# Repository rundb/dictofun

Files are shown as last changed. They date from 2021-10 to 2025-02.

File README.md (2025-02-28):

# DictoFun



Small wearable NRF52832-based-based voice recorder.

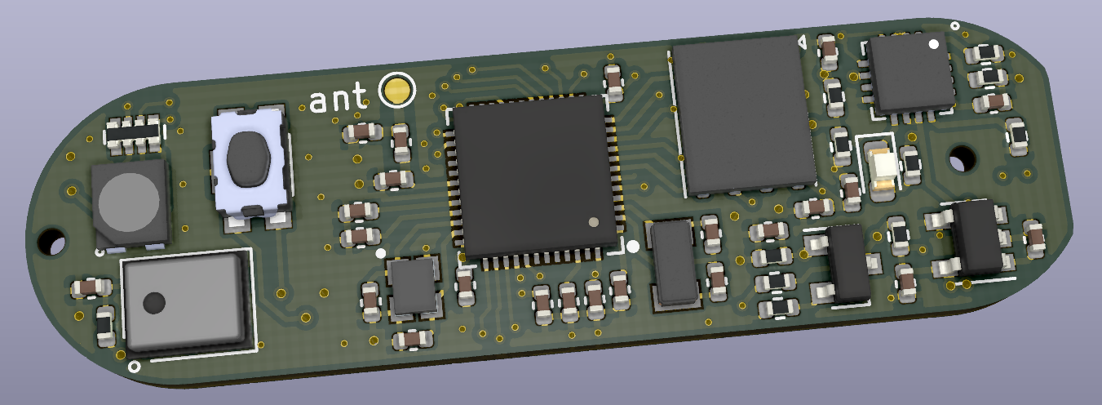
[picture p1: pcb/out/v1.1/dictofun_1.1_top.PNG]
DictoFun


## Concept

Device was initiated after my frustration while using voice recorder for storing ideas. It was taking up to 7 seconds from taking the voice recorder of the pocket to start recording the data. 

Idea behind the device: press and hold the big button on the device and start speaking. The device should start recording _immediately_ (== under human reaction time, <=0.4 sec), without the need for any other presses or for looking at the screen. When you're done - release the button. This should end the record. 

After finishing the record device should transfer the record to the phone. The record is then transferred to the voice recognition service. The recognized text should then be sent to the note keeper of your choice.

## Project structure

Project consists of 3 parts: 
* `pcb` - everything related to the schematics/PCB/boards' production. Currently v1.0, 1.1 and 1.2 exist, only v1.2 is supported in the software.
* `firmware` - software components for NRF52 chip. 
* `case` - STL files for 3D-printing the case for the Dictofun device.
* `doc` - folder with documentation used in the process of the development (datasheets, and potentially later schematic files).

`iOS` and `Android` counterparts are placed in a separate repository.

## Schematics

Relevant schematics for device is located here: `out/v1.2/schematic/nRF52832_qfaa.pdf`

## Build firmware

TBD.

Before building the firmware, SDK should be downloaded. To do that, go to `firmware/sdk` folder and execute script
`download_nordic_sdk.sh`. This command downloads and extracts the SDK files into the folder locally.

After the download one can open a corresponding Segger SES Project with SES. Later it should be possible to build with CMake. 

## Prerequisites

* install `gcc-arm-none-eabi-10.3-2021.10` to `/usr/share/gcc-arm-none-eabi-10.3-2021.10`.
* install `cmake` 3.22 or newer
* install `make`
* run script `firmware/sdk/download_nordic_sdk.sh`

## Flashing

`nrfjprog` is required to flash firmware into the device. Following command performs flashing (without changing the SoftDevice)

```
nrfjprog --reset --program ./build/src/targets/dictofun/Dictofun.hex --sectorerase --family NRF52 --verify
```

If SoftDevice is not flashed, it should be flashed using the following command:

```
nrfjprog --reset --program ./sdk/nRF5_SDK_17.1.0_ddde560/components/softdevice/s140/hex/s140_nrf52_7.2.0_softdevice.hex  --family NRF52 --sectorerase --verify
```

Both commands should be executed from folder `firmware` in the project structure.

## Clang-format

This command is used to format code recursively. 

```
find ./ -iname "*h" -o -iname "*.cpp" | xargs clang-format -i
```

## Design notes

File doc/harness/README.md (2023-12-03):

# Dictofun flashing harness

Special harness PCB has been developed to ease development of Dictofun. It is basically a bed of nails, where nails are connected
to pins of `Raspberry Pi Pico` evaluation board. It allows to combine flashing device, USB-UART bridge and button control into one 
single device and thus use only one USB connection to do all functions needed during the development.

In order to use this harness, following steps should be performed:
- flash Picoprobe firmware into Raspberry Pi Pico
- build OpenOCD with support of Picoprobe
- set up Picoprobe OpenOCD rules

After that flashing becomes possible.

## Picoprobe firmware

Picoprobe firmware implements a composite USB device with 2 devices: one used by OpenOCD for flashing and one - USB-UART bridge.

Here is the list of steps to perform (particular revision of repo is used in order to guarantee reproducibility):

```
# Assumption: we are in our working folder
# export DICTOFUN_PATH=/home/user/dictofun
git clone https://github.com/raspberrypi/pico-sdk.git
cd pico-sdk
git checkout 6a7db34ff63345a7badec79ebea3aaef1712f374
git submodule update --init --recursive
cd ..
git clone https://github.com/raspberrypi/picoprobe.git
cd picoprobe
git checkout 7de418cce3dae75ad854029b14e8869955f0afaa
git submodule update --init --recursive
git apply $DICTOFUN_PATH/doc/harness/dictofun_harness_config.patch
mkdir build && cd build
export PICO_SDK_PATH=../../pico-sdk
cmake ..
make -j
```

This chain of commands results in file `picoprobe.uf2` residing in the `build` folder. This file should be used to flash Raspberry Pi Pico on 
the harness. After flashing this file (instructions for that can be found in Chapter 3.2.4 of [Getting started with Raspberry Pi Pico](https://datasheets.raspberrypi.com/pico/getting-started-with-pico.pdf)) Raspberry Pico becomes a flashing device as well as a USB-UART bridge.

## OpenOCD

OpenOCD has to be built according to `Appendix A` in [Getting started with Raspberry Pi Pico](https://datasheets.raspberrypi.com/pico/getting-started-with-pico.pdf) document (here - Linux only)

```
cd <DEVELOPMENT/FOLDER>
sudo apt install automake autoconf build-essential texinfo libtool libftdi-dev libusb-1.0-0-dev
git clone https://github.com/raspberrypi/openocd.git --branch rp2040 --depth=1
cd openocd
./bootstrap
./configure
make -j
sudo make install
```

## udev rules

I had to install `udev` rules as well. It might eventually work without it, as I haven't checked this scenario, but I don't think it's a bad idea to install them:

```
# /etc/udev/rules.d/99-pico.rules

# Make an RP2040 in BOOTSEL mode writable by all users, so you can `picotool`
# without `sudo`. 
SUBSYSTEM=="usb", ATTRS{idVendor}=="2e8a", ATTRS{idProduct}=="0003", MODE="0666"

# Symlink an RP2040 running MicroPython from /dev/pico.
#
# Then you can `mpr connect $(realpath /dev/pico)`.
SUBSYSTEM=="tty", ATTRS{idVendor}=="2e8a", ATTRS{idProduct}=="0005", SYMLINK+="pico"

#picoprobe
SUBSYSTEM=="usb", ATTRS{idVendor}=="2e8a", MODE="0666"

#after adding this execute
# sudo udevadm control --reload-rules &&  sudo udevadm trigger 
# connect and disconnetc the USB device
#
```
I have connected and disconnected the device after that and also rebooted the computer. After that I was able to launch flashing scripts.

## Usage

Following script performs flashing of an appropriate HEX file (assuming that build has been done):

```
cd <PATH/TO/DICTOFUN/firmware/build>
openocd -f interface/cmsis-dap.cfg -f target/nrf52.cfg -c "program ./src/targets/dictofun/Dictofun.hex verify reset exit"
```

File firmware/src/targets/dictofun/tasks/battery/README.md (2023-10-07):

# Battery measurement

Battery measurement is taken to a separate task due to the importance of this function.

Basically this task performs 3 functions:
- perform measurements of battery voltage level (so it configures ADC and performs filtering)
- perform a conversion of the collected samples into an estimation of voltage level
- provide the battery level estimation to the consumers.

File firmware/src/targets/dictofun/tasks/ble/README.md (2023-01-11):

# BLE subsystem

This module aggregates all BLE configurations and functions. 

Dictofun should utilize following services:

- Led and Button service - a basic service used to bring up basic software and hardware components.
- Object Transfer service - main service that should be used 
- Distant Firmware Update service - service used for firmware upgrades

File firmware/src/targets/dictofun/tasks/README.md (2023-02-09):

# Tasks architecture

This module implements following system architecture:

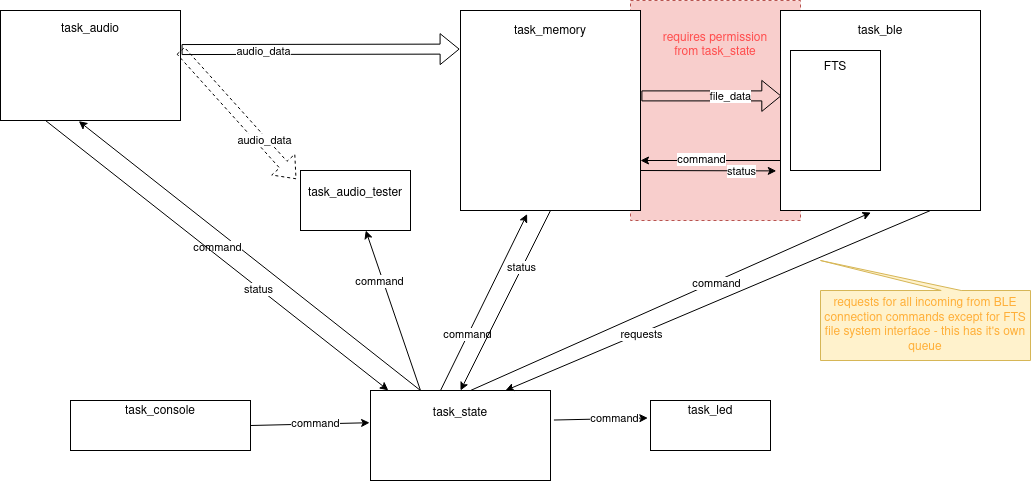
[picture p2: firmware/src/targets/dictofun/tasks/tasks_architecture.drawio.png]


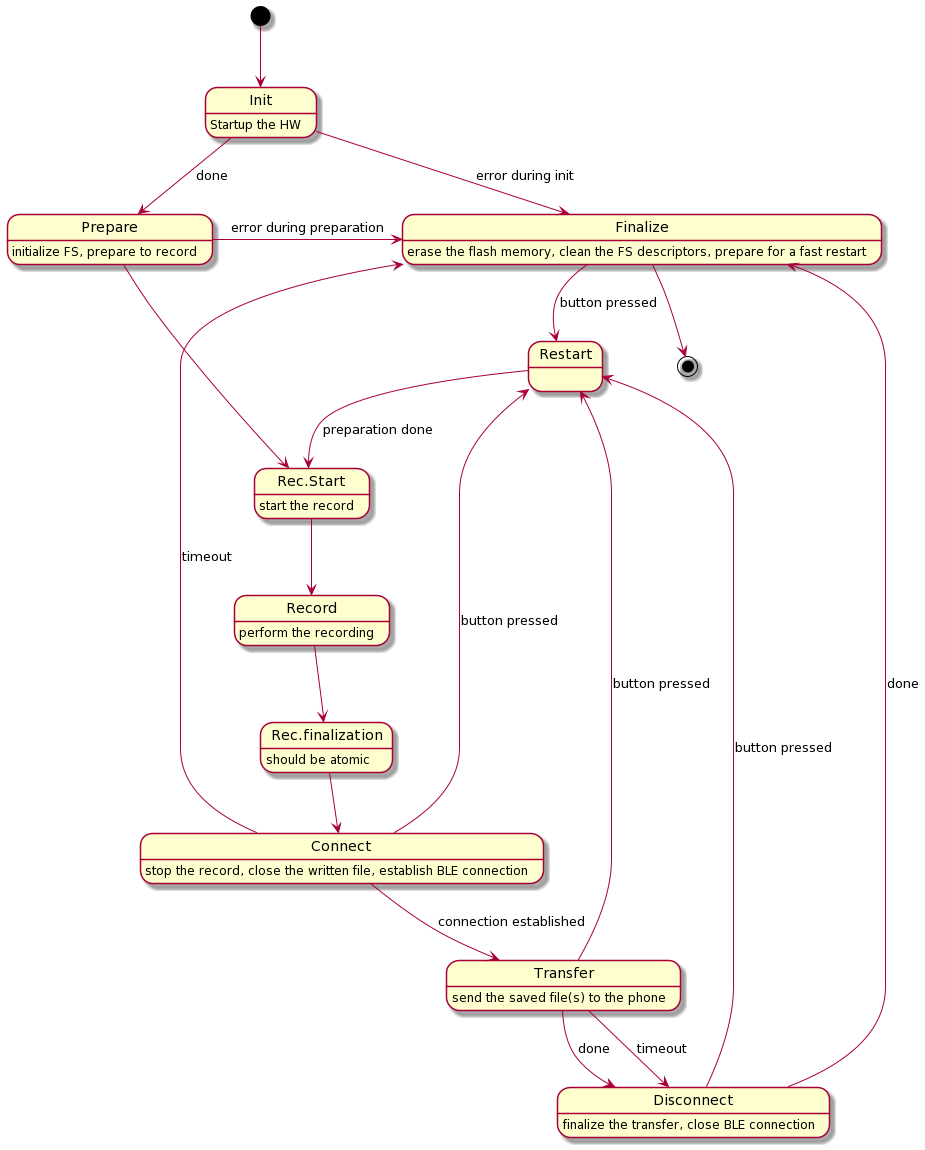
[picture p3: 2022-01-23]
firmware/src/targets/dictofun/tasks/dictofun_fsm.png

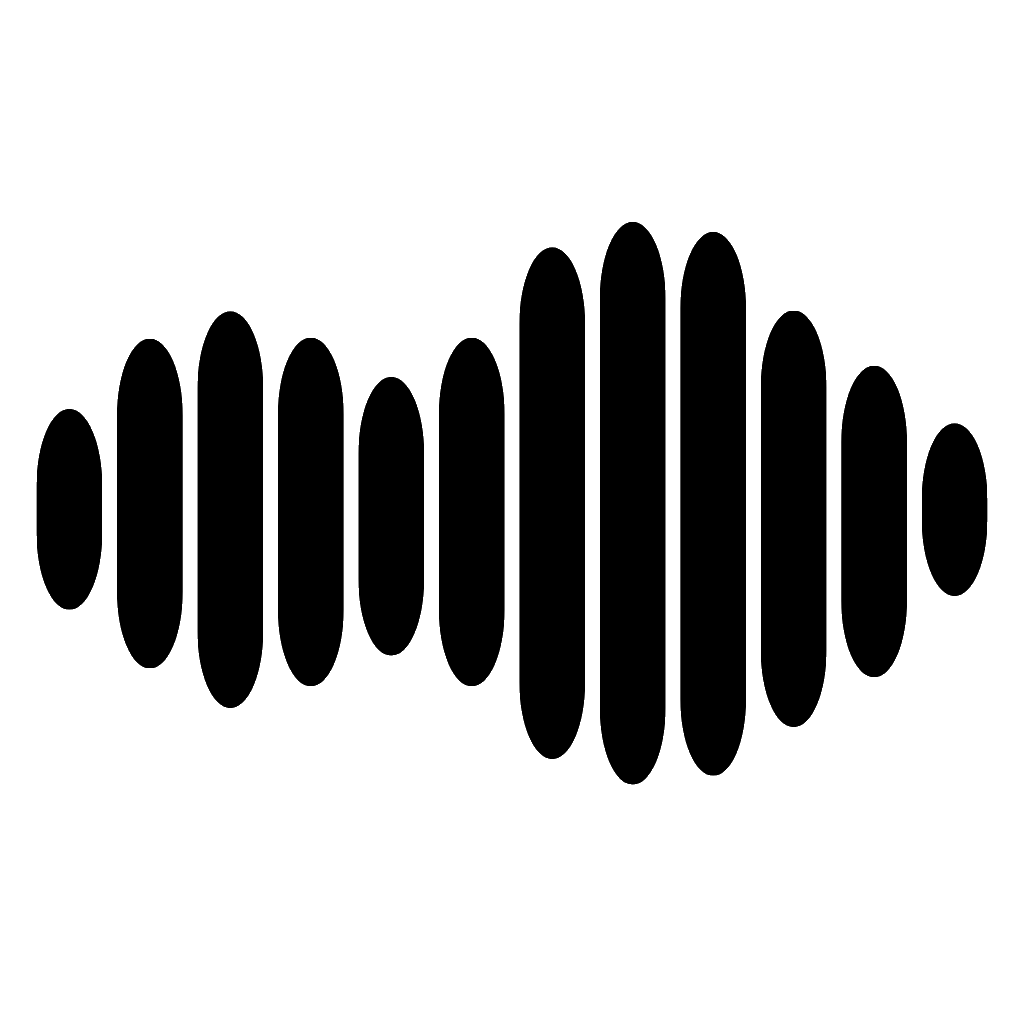
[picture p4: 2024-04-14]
pcb/Dictofun.png

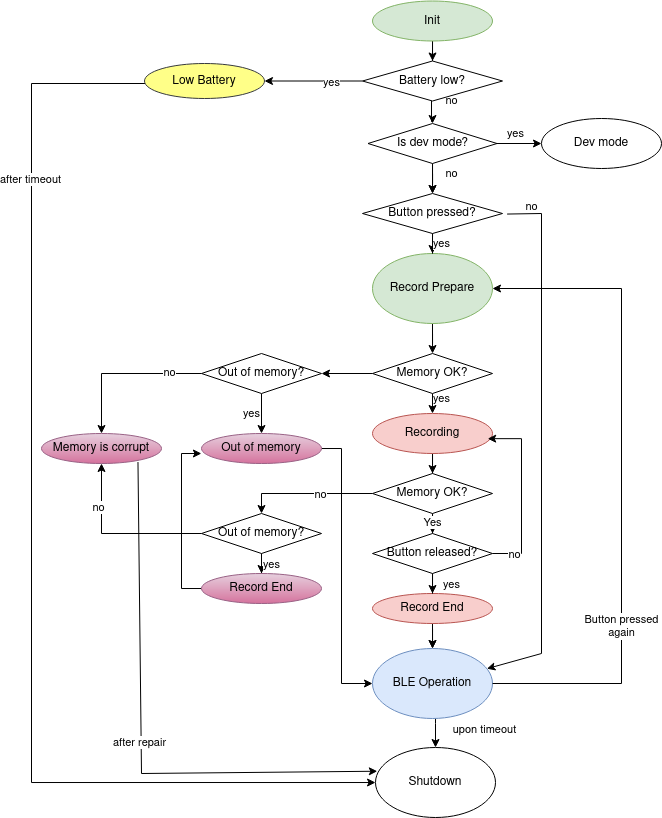
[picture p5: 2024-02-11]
firmware/src/targets/dictofun/tasks/systemstate/df-states.drawio.png

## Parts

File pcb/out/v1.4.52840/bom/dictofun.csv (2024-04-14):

Designator | Value | Footprint | LCSC | Qty
C1, C2 | 22uF | Capacitor_SMD:C_0603_1608Metric | C84419 | 2
C3, C4, C5, C7, C8, C13, C15, C18, C22, C25, C27, C53, C54 | 100nF | Capacitor_SMD:C_0402_1005Metric | C1525 | 13
C6, C14, C17, C19, C24, C26, C55 | 1uF | Capacitor_SMD:C_0402_1005Metric | C77007 | 7
C9, C10, C11, C12 | 10pF | Capacitor_SMD:C_0402_1005Metric | C32949 | 4
C20, C21 | 4.7uF | Capacitor_SMD:C_0402_1005Metric | C23733 | 2
C23 | 10uF | Capacitor_SMD:C_0402_1005Metric | C15525 | 1
C28 | 100p | Capacitor_SMD:C_0402_1005Metric | C445763 | 1
C29 | 47nF | Capacitor_SMD:C_0402_1005Metric | C338148 | 1
C47 | 0.7pF | Capacitor_SMD:C_0402_1005Metric | C2194394 | 1
C49 | 820pF | Capacitor_SMD:C_0402_1005Metric | C161159 | 1
C50, C51, C52 | 4.7uF | Capacitor_SMD:C_0603_1608Metric | C108342 | 3
D1 | PRTR5V0U2X | Package_TO_SOT_SMD:SOT-143 | C2827688 | 1
D3 | LED | LED_SMD:LED_0603_1608Metric | C2981448 | 1
D5 | D_Schottky | Diode_SMD:D_SOD-123F | C223608 | 1
FB1, FB2, FB3 | FerriteBead | Inductor_SMD:L_0402_1005Metric | C19136 | 3
L1 | 0.47uH | Inductor_SMD:L_1008_2520Metric | C1333867 | 1
L2 | 10uH | Inductor_SMD:L_0402_1005Metric | C910650 | 1
L3 | 15nH | Inductor_SMD:L_0402_1005Metric |  | 1
L7 | 2.2nH | Inductor_SMD:L_0402_1005Metric | C97985 | 1
Q1 | PMOS | Package_TO_SOT_SMD:SOT-23 | C332106 | 1
R1, R14, R18, R19, R24 | 100K | Resistor_SMD:R_0402_1005Metric | C25741 | 5
R2, R4, R22 | 4.7k | Resistor_SMD:R_0402_1005Metric | C25900 | 3
R3, R12, R25 | 330 | Resistor_SMD:R_0402_1005Metric | C25104 | 3
R5, R17, R21 | 1.6K | Resistor_SMD:R_0402_1005Metric | C25867 | 3
R6 | 1.13K | Resistor_SMD:R_0402_1005Metric | C67014 | 1
R7 | 10K | Resistor_SMD:R_0402_1005Metric | C25744 | 1
R8 | 1.18K | Resistor_SMD:R_0402_1005Metric | C270651 | 1
R9, R13 | 1K | Resistor_SMD:R_0402_1005Metric | C11702 | 2
R10, R11, R23 | 1M | Resistor_SMD:R_0402_1005Metric | C226699 | 3
R15 | 255k | Resistor_SMD:R_0603_1608Metric | C728604 | 1
R16 | 91k | Resistor_SMD:R_0603_1608Metric | C227535 | 1
RN3 | R_Pack04 | Resistor_SMD:R_Array_Convex_4x0402 | C25726 | 1
S1 | KMR221GLFS | df_components:SW_KMR221GLFS | C72443 | 1
U1 | nRF52840 | Package_DFN_QFN:Nordic_AQFN-73-1EP_7x7mm_P0.5mm | C190794 | 1
U2 | W25Q128JWPIQ | nRF52832_qfaa:WSON-8-1EP_6x5mm_P1.27mm_EP3.4x4.3mm | C2689660 | 1
U3 | TPS63802DLAR | df_components:VREG_TPS63802DLAR | C2845237 | 1
U4 | BQ24078RGTR | _other:VQFN-16-1EP_3x3mm_P0.5mm_EP1.45x1.45mm_ThermalVias | C15464 | 1
U6 | SN74LVC1G79DBVT | Package_TO_SOT_SMD:SOT-23-5 | C42878 | 1

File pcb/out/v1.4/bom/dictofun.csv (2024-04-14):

Designator | Footprint | LCSC
C1 | Capacitor_SMD:C_0603_1608Metric | C109447
C2 | Capacitor_SMD:C_0603_1608Metric | C109447
C3 | Capacitor_SMD:C_0402_1005Metric | C1525
C4 | Capacitor_SMD:C_0201_0603Metric | C5142565
C5 | Capacitor_SMD:C_0201_0603Metric | C5142565
C6 | Capacitor_SMD:C_0402_1005Metric | C77007
C7 | Capacitor_SMD:C_0201_0603Metric | C5142565
C8 | Capacitor_SMD:C_0201_0603Metric | C5142565
C10 | Capacitor_SMD:C_0402_1005Metric | C32949
C13 | Capacitor_SMD:C_0402_1005Metric | C32949
C15 | Capacitor_SMD:C_0402_1005Metric | C1525
C17 | Capacitor_SMD:C_0402_1005Metric | C52923
C18 | Capacitor_SMD:C_0402_1005Metric | C1525
C19 | Capacitor_SMD:C_0402_1005Metric | C52923
C20 | Capacitor_SMD:C_0402_1005Metric | C23733
C21 | Capacitor_SMD:C_0402_1005Metric | C23733
C23 | Capacitor_SMD:C_0402_1005Metric | C15525
C24 | Capacitor_SMD:C_0402_1005Metric | C52923
C25 | Capacitor_SMD:C_0402_1005Metric | C1525
C26 | Capacitor_SMD:C_0402_1005Metric | C52923
C27 | Capacitor_SMD:C_0402_1005Metric | C1525
C28 | Capacitor_SMD:C_0201_0603Metric | C5142565
C29 | Capacitor_SMD:C_0201_0603Metric | C5142565
C30 | Capacitor_SMD:C_0201_0603Metric | C5142565
C31 | Capacitor_SMD:C_0201_0603Metric | C5142565
C32 | Capacitor_SMD:C_0201_0603Metric | C5142565
C33 | Capacitor_SMD:C_0201_0603Metric | C5142565
C34 | Capacitor_SMD:C_0201_0603Metric | C5142565
C35 | Capacitor_SMD:C_0201_0603Metric | C5142565
C37 | Capacitor_SMD:C_0402_1005Metric | C77007
C38 | Capacitor_SMD:C_0402_1005Metric | C77007
C39 | Capacitor_SMD:C_0402_1005Metric | C77007
C40 | Capacitor_SMD:C_0402_1005Metric | C77007
C41 | Capacitor_SMD:C_0603_1608Metric | C77183
C42 | Capacitor_SMD:C_0603_1608Metric | C2961288
C43 | Capacitor_SMD:C_0603_1608Metric | C108342
C44 | Capacitor_SMD:C_0402_1005Metric | C77007
C45 | Capacitor_SMD:C_0201_0603Metric | C5142565
D1 | Package_TO_SOT_SMD:SOT-143 | C2827688
D3 | LED_SMD:LED_0603_1608Metric | C131282
D5 | Diode_SMD:D_SOD-123F | C223608
FB1 | Inductor_SMD:L_0402_1005Metric | C19136
FB2 | Inductor_SMD:L_0402_1005Metric | C19136
FB3 | Inductor_SMD:L_0402_1005Metric | C19136
L1 | Inductor_SMD:L_1008_2520Metric | C1333867
L3 | Inductor_SMD:L_0603_1608Metric | C5339208
L4 | Inductor_SMD:L_0603_1608Metric | C5339208
L5 | Inductor_SMD:L_0201_0603Metric | C1332892
L6 | Inductor_SMD:L_0201_0603Metric | C1332892
L7 | Inductor_SMD:L_0201_0603Metric | C1329438
Q1 | Package_TO_SOT_SMD:SOT-23 | C332106
R1 | Resistor_SMD:R_0402_1005Metric | C25741
R2 | Resistor_SMD:R_0402_1005Metric | C25900
R3 | Resistor_SMD:R_0402_1005Metric | C25104
R4 | Resistor_SMD:R_0402_1005Metric | C25900
R5 | Resistor_SMD:R_0402_1005Metric | C25867
R6 | Resistor_SMD:R_0402_1005Metric | C67014
R7 | Resistor_SMD:R_0402_1005Metric | C25744
R8 | Resistor_SMD:R_0402_1005Metric | C270651
R9 | Resistor_SMD:R_0402_1005Metric | C11702
R10 | Resistor_SMD:R_0402_1005Metric | C226699
R11 | Resistor_SMD:R_0402_1005Metric | C226699
R12 | Resistor_SMD:R_0402_1005Metric | C25104
R13 | Resistor_SMD:R_0402_1005Metric | C11702
R14 | Resistor_SMD:R_0402_1005Metric | C25741
R15 | Resistor_SMD:R_0603_1608Metric | C728604
R16 | Resistor_SMD:R_0603_1608Metric | C227535
R17 | Resistor_SMD:R_0402_1005Metric | C25867
R18 | Resistor_SMD:R_0402_1005Metric | C25741
R19 | Resistor_SMD:R_0402_1005Metric | C25741
R20 | Resistor_SMD:R_0201_0603Metric | C166070
R21 | Resistor_SMD:R_0402_1005Metric | C25867
R22 | Resistor_SMD:R_0402_1005Metric | C25900
R23 | Resistor_SMD:R_0402_1005Metric | C226699
R24 | Resistor_SMD:R_0402_1005Metric | C25741
R25 | Resistor_SMD:R_0402_1005Metric | C25104
RN3 | Resistor_SMD:R_Array_Convex_4x0402 | C25726
S1 | df_components:SW_KMR221GLFS | C72443
U2 | nRF52832_qfaa:WSON-8-1EP_6x5mm_P1.27mm_EP3.4x4.3mm | C2689660
U3 | df_components:VREG_TPS63802DLAR | C2845237
U4 | _other:VQFN-16-1EP_3x3mm_P0.5mm_EP1.45x1.45mm_ThermalVias | C15464
U6 | Package_TO_SOT_SMD:SOT-23-5 | C42878
U7 | _other:XCVR_NRF5340-QKAA-R7 | C3015611
C47 | Capacitor_SMD:C_0402_1005Metric | C384700
C11 | Capacitor_SMD:C_0402_1005Metric | C161369
C12 | Capacitor_SMD:C_0402_1005Metric | C161369

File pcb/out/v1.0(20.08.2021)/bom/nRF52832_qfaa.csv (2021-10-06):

Id | Designator | Package | Quantity | Designation | Supplier and ref
1 | R5 | R_0402_1005Metric | 1 | 1M
2 | R4,R3,R2,R6 | R_0402_1005Metric | 4 | 330
3 | C13,C20,C17,C16,C4,C5,C8 | RESC0402_N | 7 | 100nF
4 | J2 | PinHeader_2x05_P1.27mm_Vertical_SMD | 1 | Conn_02x05_Odd_Even
5 | C19,C18 | C_0603_1608Metric | 2 | 10uF
6 | C15 | RESC0402_N | 1 | 1uF
7 | C10 | RESC0402_N | 1 | 1µF
8 | U4 | SPU0410HR5H | 1 | SPU0410HR5H
9 | J1 | PinHeader_1x02_P2.54mm_Vertical | 1 | Battery
10 | RN1 | R_Array_Convex_4x0603 | 1 | R_Pack04
11 | D1 | LED_Cree-PLCC4_2x2mm_CW | 1 | ASMB-MTB0-0A3A2
12 | J3 | PinHeader_1x03_P2.54mm_Vertical | 1 | Conn_01x03_Male
13 | L2 | RESC0402_N | 1 | 2.7nH
14 | AE1 | ANT_2450AT18B100 | 1 | Antenna_Chip
15 | U5 | WSON-8-1EP_6x5mm_P1.27mm_EP3.4x4.3mm | 1 | W25Q32JVZP
16 | U3 | SOT-23-5 | 1 | TLV75533PDBVR
17 | U2 | LED_BUTTON | 1 | LED-Button
18 | U1 | QFN40P600X600X90-48_N | 1 | NRF52832
19 | X1 | BT-XTAL_2016_N | 1 | 32MHz
20 | L1 | RESC0402_N | 1 | 3.3nH
21 | C2,C1,C11,C12 | RESC0402_N | 4 | 12pF
22 | C3 | RESC0402_N | 1 | 1.2pF
23 | C6 | RESC0402_N | 1 | N.M.
24 | C7 | RESC0402_N | 1 | 100pF
25 | C9 | RESC0603_N | 1 | 4.7µF
26 | X2 | XTAL_3215_N | 1 | 32.768kHz

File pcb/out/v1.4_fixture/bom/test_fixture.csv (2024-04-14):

Designator | Comment | Footprint | LCSC
C2, C3, C6, C7, C11, C12, C13, C14 | 100n | Capacitor_SMD:C_0402_1005Metric | C1525
C9 | 10u | Resistor_SMD:R_1206_3216Metric | C165101
C10 | 22u | Capacitor_SMD:C_1206_3216Metric | C92818
Q1 | NMOS | Package_TO_SOT_SMD:SOT-23 | C916396
R1 | 415 | Resistor_SMD:R_0603_1608Metric | C114669
R2 | 187 | Resistor_SMD:R_0603_1608Metric | C22828
R4, R5, R6, R11 | 100K | Resistor_SMD:R_0603_1608Metric | C122538
R7 | 200K | Resistor_SMD:R_0603_1608Metric | C118142
R8 | 300K | Resistor_SMD:R_0603_1608Metric | C103526
R10, R12 | 1K | Resistor_SMD:R_0603_1608Metric | C375503
SW1 | SW_SPDT | df_footprints:K3_1235S_f1 | C92660
U2 | MIC29302WU | Package_TO_SOT_SMD:TO-263-5_TabPin3 | C11149
U4, U6, U7 | SN74AVC4T774RSVR | df_footprints:QFN40P260X180X55_16N | C1849454
U5 | TXB0104RGY | Package_DFN_QFN:Texas_S-PVQFN-N14 | C400708

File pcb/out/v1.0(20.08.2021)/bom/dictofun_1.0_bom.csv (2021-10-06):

Comment | Designator | Footprint | LCSC
100pF | C7 | C_0402 | C1546
NRF52832 | U1 | QFN40P600X600X90-48_N | C77540
12pF | C1,C2,C11,C12 | C_0402 | C85873
0.8pF | C3 | C_0402 | C88902
1µF | C10 | C_0402 | C92755
1uF | C15 | C_0402 | C92755
1M | R5 | R_0402 | C93949
2.7nH | L2 | L_0402 | C98058
4.7µF | C9 | C_0603 | C109456
R_Pack04 | RN1 | R_Array_Convex_4x0603 | C110021
3.3nH | L1 | L_0402 | C162542
330 | R2,R3,R4,R6 | R_0402 | C168225
10uF | C18,C19 | C_0603 | C326057
TLV75533PDBVR | U3 | SOT-23-5 | C404027
100nF | C4,C5,C8,C13,C16,C17,C20 | C_0402 | C541464
W25Q32JVZP | U5 | WSON-8 | C2689660

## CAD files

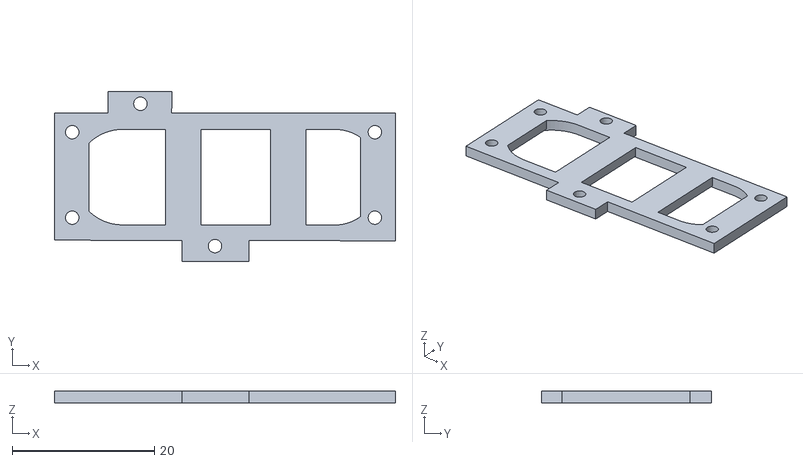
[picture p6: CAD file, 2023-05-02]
case/dictofun_1.3_bed_top.stl
48.0 x 23.9 x 1.70

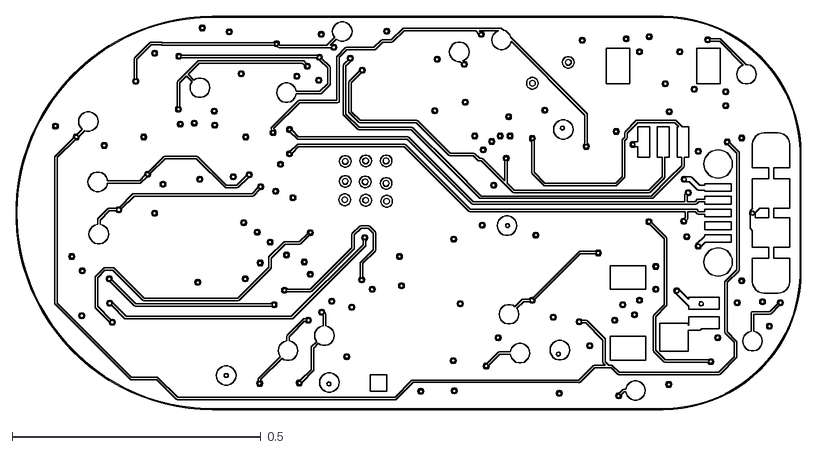
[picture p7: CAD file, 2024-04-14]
pcb/test_fixture/v1.4/dictofun-Bottom.dxf
1.58 x 0.789

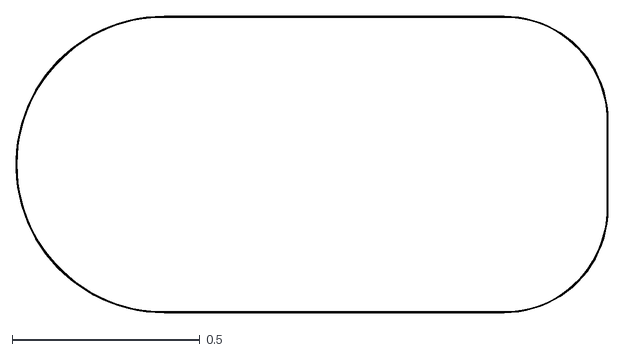
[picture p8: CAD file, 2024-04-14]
pcb/v1.4/nrf52840/out/v1.4_fixture/dictofun-Edge_Cuts.dxf
1.58 x 0.789

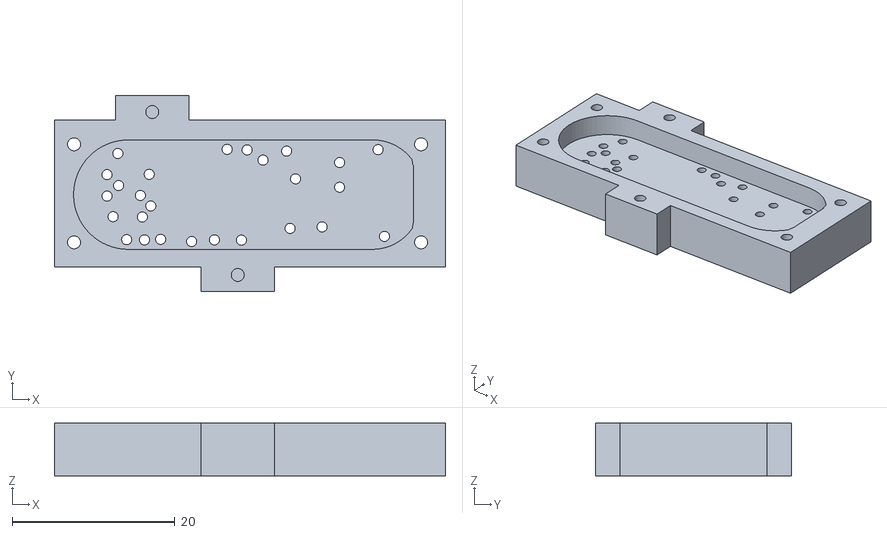
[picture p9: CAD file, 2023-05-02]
case/dictofun_1.3_bed_of_nails.stl
48.0 x 24.0 x 6.50

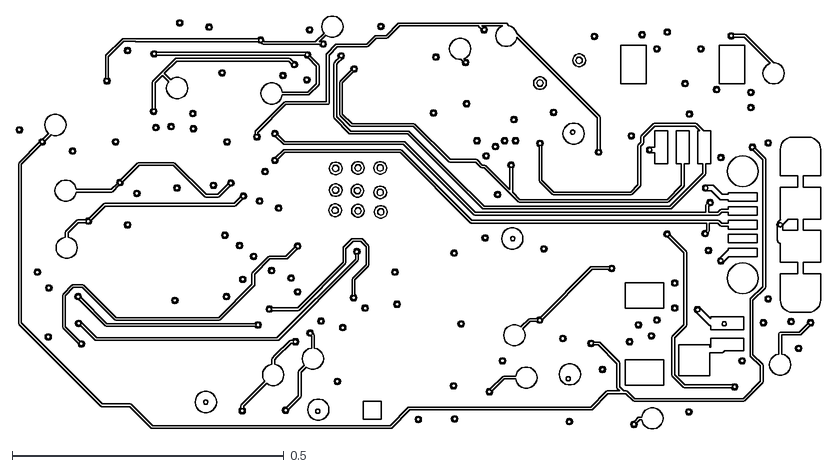
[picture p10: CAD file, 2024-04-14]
pcb/v1.4/nrf52840/out/v1.4_fixture/dictofun-Bottom.dxf
1.48 x 0.76

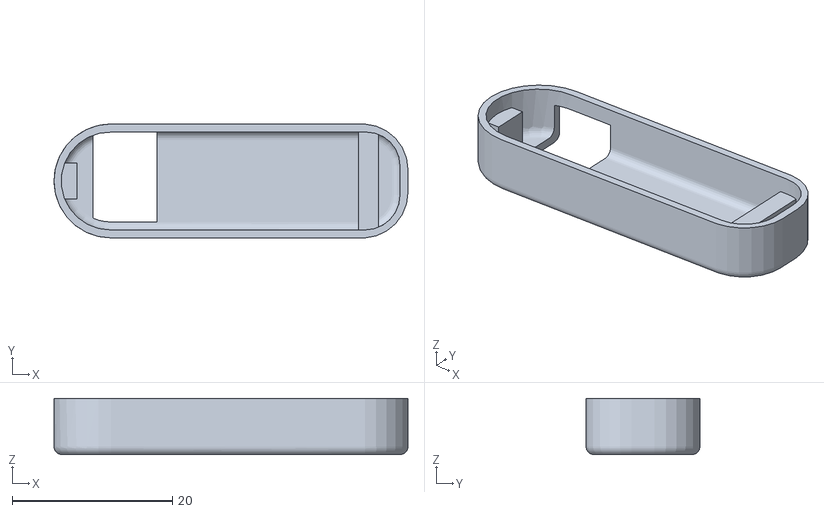
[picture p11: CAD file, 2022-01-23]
case/bottom.stl
44.1 x 14.2 x 7.00

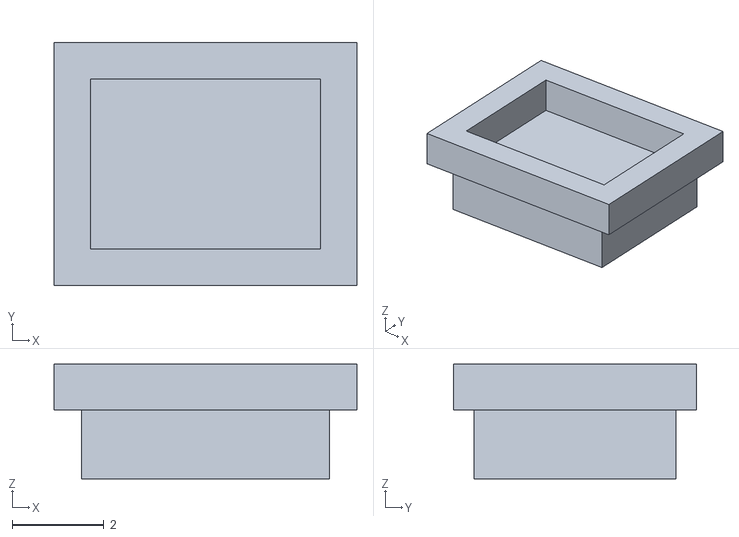
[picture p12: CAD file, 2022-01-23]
case/button.stl
6.60 x 5.30 x 2.50

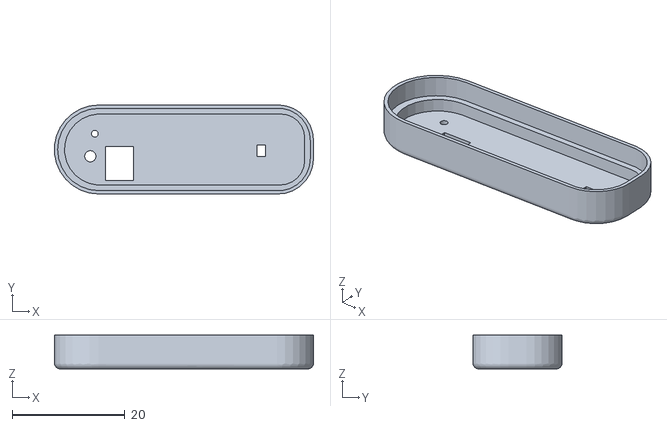
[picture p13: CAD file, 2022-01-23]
case/top.stl
46.0 x 15.8 x 6.00

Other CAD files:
case/bottom.ipt
case/button.ipt
case/dictofun_1.3_bed_of_nails.f3d
case/dictofun_1.3_bed_top.f3d
case/dictofun_button.f3d
case/dictofun_case_bottom.f3d
case/ductofun_case_top.f3d
case/top.ipt

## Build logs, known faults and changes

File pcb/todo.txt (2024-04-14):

v1.4
- install Schottky between button and LDO input
- consider lower operating voltage
- optimize power circuit by price and components' availability
- (consider) replacing power circuits with NPM1300
- leave more space around the button
- take interrupt output of the RTC as wake up input to power regulator
- use a bigger flash memory
- utilize NRF5340
- consider the option of installing NFC antenna
- install USB Type C connector
- figure out, where VDDH should be connected

Rework for v1.1.
* cut lines that are coming to pins p0.25 and p0.26 and put a ~1k resistor into the cut. If this is not done, NRF52 burns down.

TODO for v1.1:
* investigate why LDO is not shutdown after it is pulled down.

For newer versionss
* add current limiting resistors on lines MAIN_BUTTON and DBG_POWER_LATCH that enter the microcontroller. 
* use teardrops for the pins
* enforce the testpoints and b- / b+ points (with vias and/or with thicker lines/more vias)
* consider a debug plug that wouldn't require soldering a 10-pin JTAG connector for flashing.

Requirements for v1.2

* fix known issues of v1.1
* move button closer to the center of the PCB
* strict size constraints are not a prio anymore (width can be increased to 1-2 mm, length as well)
* develop a sufficient set of testpoints for bring-up checks and tests
* provide bottom testpoints for development purposes
* provide top testpoints for power, battery and charging-related tests + JTAG + console
* develop a test fixture with pogo-pins for development

Development testpoints (bottom)
* all JTAG pins
* UART
* power input
* charger output
* LDO en
* 3.3V
* one of DEC caps
* PDM clock and data
* SPI bus
* 1-3 GPIOs

Production testpoints (top)
* JTAG
* UART
* power in
* LDO in
* LDO out
* charger in

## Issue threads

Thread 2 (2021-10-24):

Add BQ24072RGTR to the schematics

rundb, 2021-10-24:
https://www.ti.com/store/ti/en/p/product/?p=BQ24072RGTR

Add this charger control to the schematics (including periphery and necessary resistors/LEDs/test points).

Please perform it in the branch https://github.com/rundb/dictofun/tree/rotu/add_ldo_latching_circuit (thus no need to redo work on the electrical OR for LDO)

al-nordlicht, 2021-11-21:
done

Closed 2021-11-21.

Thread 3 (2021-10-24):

Implement pairing procedure between Android and DictoFun

rundb, 2021-10-24:
Implement proper pairing procedure (several activities on Android side, reset procedures for both Android and device)

rundb, 2021-12-22:
https://github.com/rundb/dictofun/pull/4

Closed 2021-12-22.

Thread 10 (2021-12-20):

FTS is not starting

rundb, 2021-12-20:
After pairing is complete, file transfer never starts.

Steps to reproduce:
HW 1.1.

Build the Nordic SW. Erase the chip. Download the app. Start recording.

On the phone side - erase the bonds, exit the app, start again. Start pairing procedure.

Pairing procedure passes. After it Android attempts to start file transfer, but _fts_data_handler_ doesn't receive any FTS requests on the nordic side.

rundb, 2021-12-22:
**Rootcause:** Android app has been connecting to the first element of associations, without relating it to any of the bonds. Therefore, when I changed platform from 1.0 to 1.1, app still has been trying to connect to the device with MAC address of the device 1.0.

**Resolution:** Erase the associations' list together with erase of the bonds, connect to the first bonded device. Current workflow makes it impossible to pair more than one dictofun, so this fix should be sufficient with the current SW structure.

Closed 2021-12-22.

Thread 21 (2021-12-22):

Implement proper SPI Flash driver

rundb, 2021-12-22:
* utilize all 256 bytes of the SPI Flash page
* utilize DMA, if it is not yet utilized

rundb, 2022-02-19:
Resolved by  PR #39

Closed 2022-02-19.

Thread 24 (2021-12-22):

Create case for the device

rundb, 2021-12-22:
Design, prototype and print the cases for the device

rundb, 2022-01-23:
Resolved without PR in commit f7a7b3be24397b7ddcb93116247e966a12858f35

Closed 2022-01-23.

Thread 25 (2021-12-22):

Implement battery management

rundb, 2021-12-22:
1) use battery power
2) test battery charging
3) implement battery level monitoring and management

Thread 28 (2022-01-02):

[pcb] current limiting resistors are missing on lines MAIN_BUTTON and DBG_POWER_LATCH

rundb, 2022-01-02:
First run of the board burns down the power controller of the Nordic  chip.

Closed 2022-01-14.

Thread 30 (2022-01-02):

HW v1.1 restarts after shutdown with LDO

rundb, 2022-01-02:
**TODO:** add a note on the set of fixes that should be applied for the next revision of the hardware.

After the transmission of the last recorded file to the phone is done, device should shutdown. This is done by pulling LDO_EN pin down.

Observed behavior: device restarts, records exactly 0 bytes of data and attempts a data transfer again.

Probable rootcause: self-latch of LDO isn't properly shut down with LDO_EN pin pulling down. Should be checked with an oscilloscope.
Possible solutions:
- cut the self-latch line (most radical one)
- select a proper resistor nominal for this self-latch line and for the LDO_EN line.
- possibly: find a SW solution to ensure pin is pulled down properly (like noInitRam containing status which enforces pulling the line down ASAP after the startup of the chip)

rundb, 2022-02-19:
Additional note: LDO_EN needs additionally a 10n capacitor

Closed 2022-07-08.

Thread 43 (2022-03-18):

When >1 files are recorded, all files but first are corrupt

rundb, 2022-03-18:
When several files are transferred from device to the phone, second, third and so on files fail to play/recognize

Closed 2022-03-18.

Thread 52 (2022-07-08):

Implement full button-related FSM

rundb, 2022-07-08:
Currently FSM supports only linear movement along the FSM. Add jumps back to the recording state from all other states (connection, transmission, etc)

rundb, 2022-07-28:
done with other PRs

Closed 2022-07-28.

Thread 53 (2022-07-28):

Integrate an Audio codec

rundb, 2022-07-28:
Currently we have 2 big issues - long transmission time and short battery life. Both issues can be solved with a codec.

Current audio data rate - 24 kByte/sec. Target - >= 4kByte/sec, I'd be happy to see 1 KByte/sec.

Closed 2023-02-26.

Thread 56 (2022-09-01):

Current set of issues

rundb, 2022-09-01:
1. IPhone often fails to issue the appropriate set of commands that trigger the transaction.
2. Restart behavior is unstable. In particular, seems like device attempts to reconnect to the phone before the recording is finished.

Closed 2022-11-09.

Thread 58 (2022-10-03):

Set of tasks needed to convert project to a platform

rundb, 2022-10-03:
Most of current project issues are related to its initially planned lifetime. It wasn't developed initially as a platform, and thus it's hard to introduce now any kind of complex logic and make any significant changes in the logic.

Purpose of this issue is to move the project from a standalone state into a sort of a SW platform, so that a) any new developer can be easily introduced into the development and b) project could be presented to the open-source community.

What has to be changed?

* introduce a platform-independent build system
* introduce a reliable firmware update process (based on both BLE and UART)
* introduce a clearer architecture (consider using FreeRTOS)
** possibly - introduce RTOS
** possibly - add app modes, development/engineering and field (with different shutdown and startup procedures)
* add support of automated unit-tests for the modules
* add console and set of tester modules for the existing driver/logic modules

Closed 2023-02-26.

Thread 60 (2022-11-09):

Hardware improvements for next revision

rundb, 2022-11-09:
* add set of TPs for a full testability (plus several testpoints to connect external test devices)
* add RTC
* use a discrete logical element with a fixed state for enabling/disabling the LDO
* switch to a low-power DC-DC converter for the supply

Closed 2023-02-26.

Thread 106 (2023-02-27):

Implement full setup control with RP2040

rundb, 2023-02-27:
1. enable openocd-based flashing process using RP2040
2. use RP2040 as a bridge for the UART console
3. implement control over setup using GPIO pins (button on/off in particular)
4. implement ADC readout to PC
5. implement PC counterpart for tests

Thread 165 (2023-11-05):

Shutdown happens soon after recording restart

rundb, 2023-11-05:
if record is launched twice or more in one session, the timeout to shutdown doesn't seem to reset back to default value and device shuts down immediately after the record stop

rundb, 2023-11-05:
unable to reproduce consistently

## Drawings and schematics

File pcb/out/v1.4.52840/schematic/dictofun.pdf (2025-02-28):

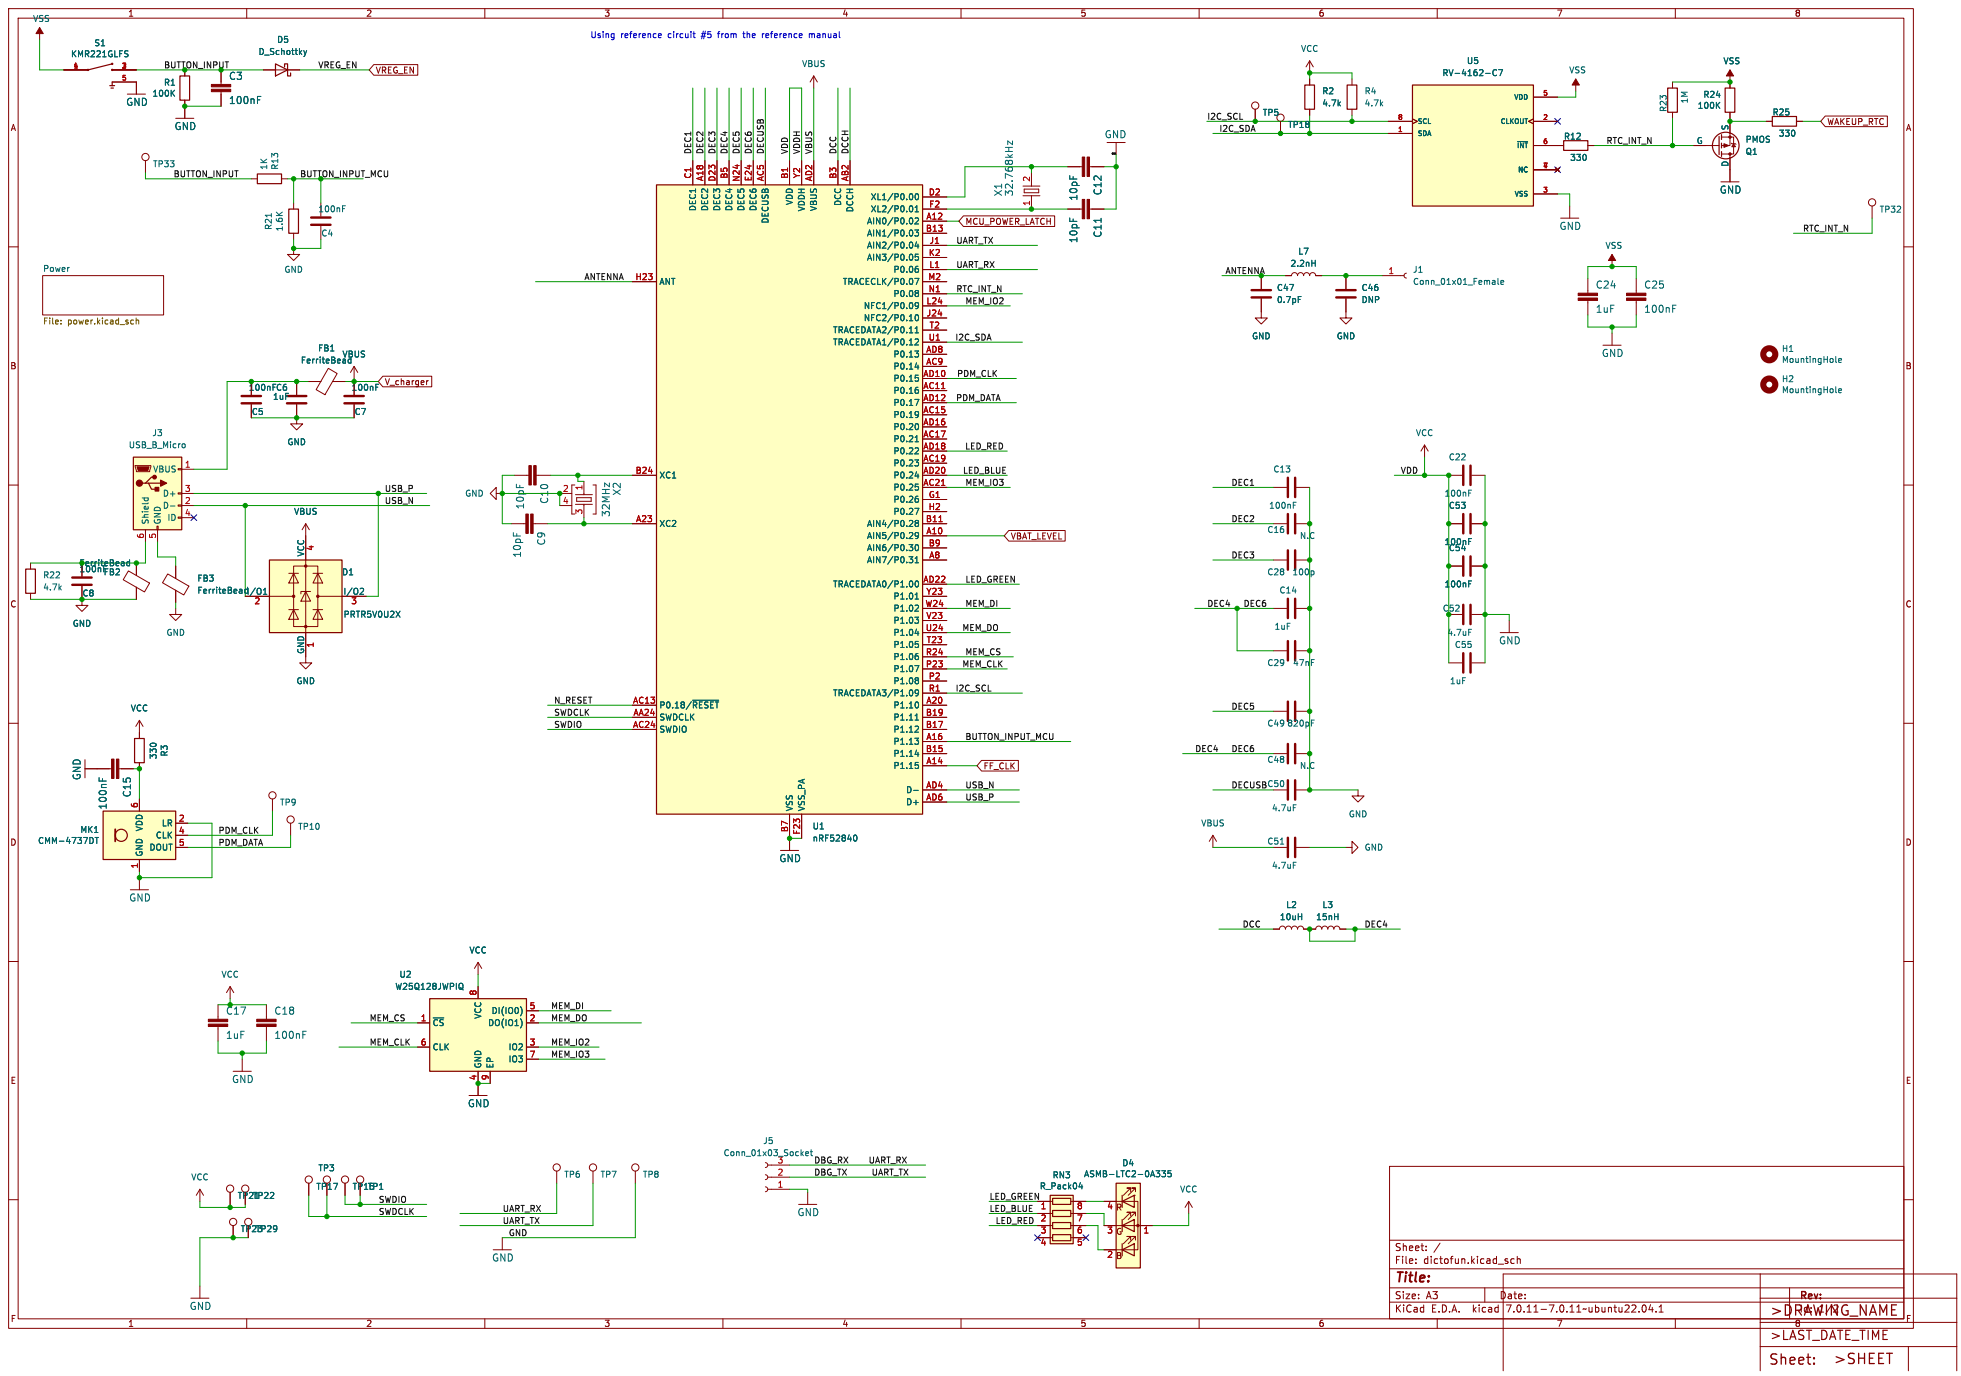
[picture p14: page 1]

LR 2 CLK 4 DOUT 5 VDD

Id: 1/2 Title: File: dictofun.kicad_sch Sheet: /

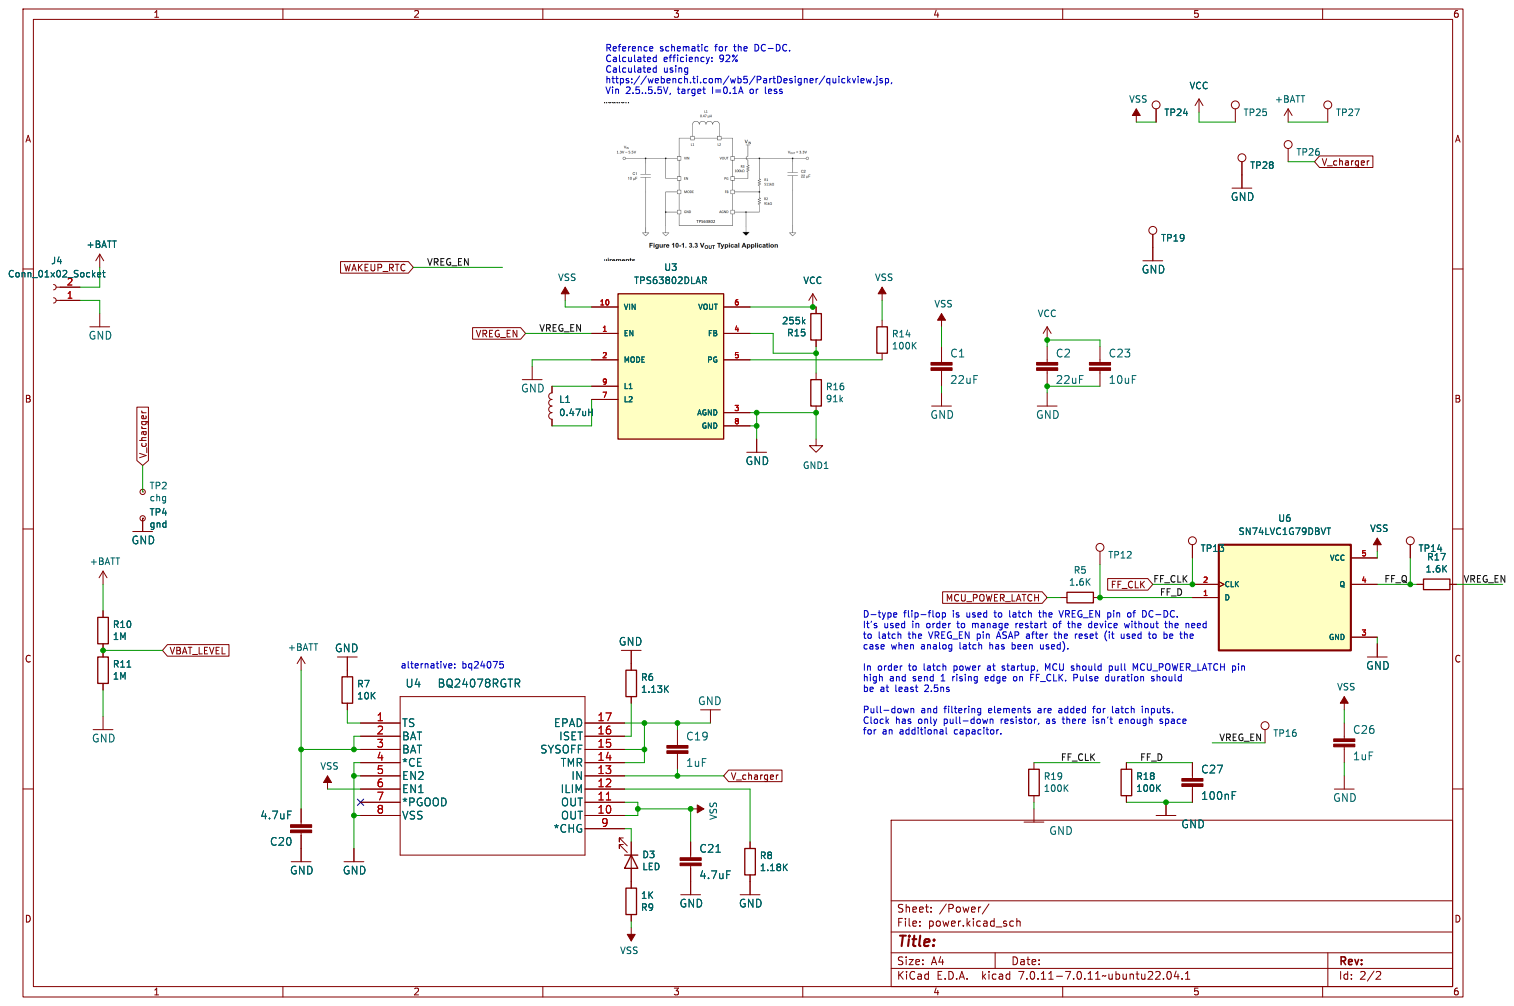
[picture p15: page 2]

It's used in order to manage restart of the device without the need
to latch the VREG_EN pin ASAP after the reset (it used to be the
case when analog latch has been used).

Id: 2/2 Title: File: power.kicad_sch Sheet: /Power/

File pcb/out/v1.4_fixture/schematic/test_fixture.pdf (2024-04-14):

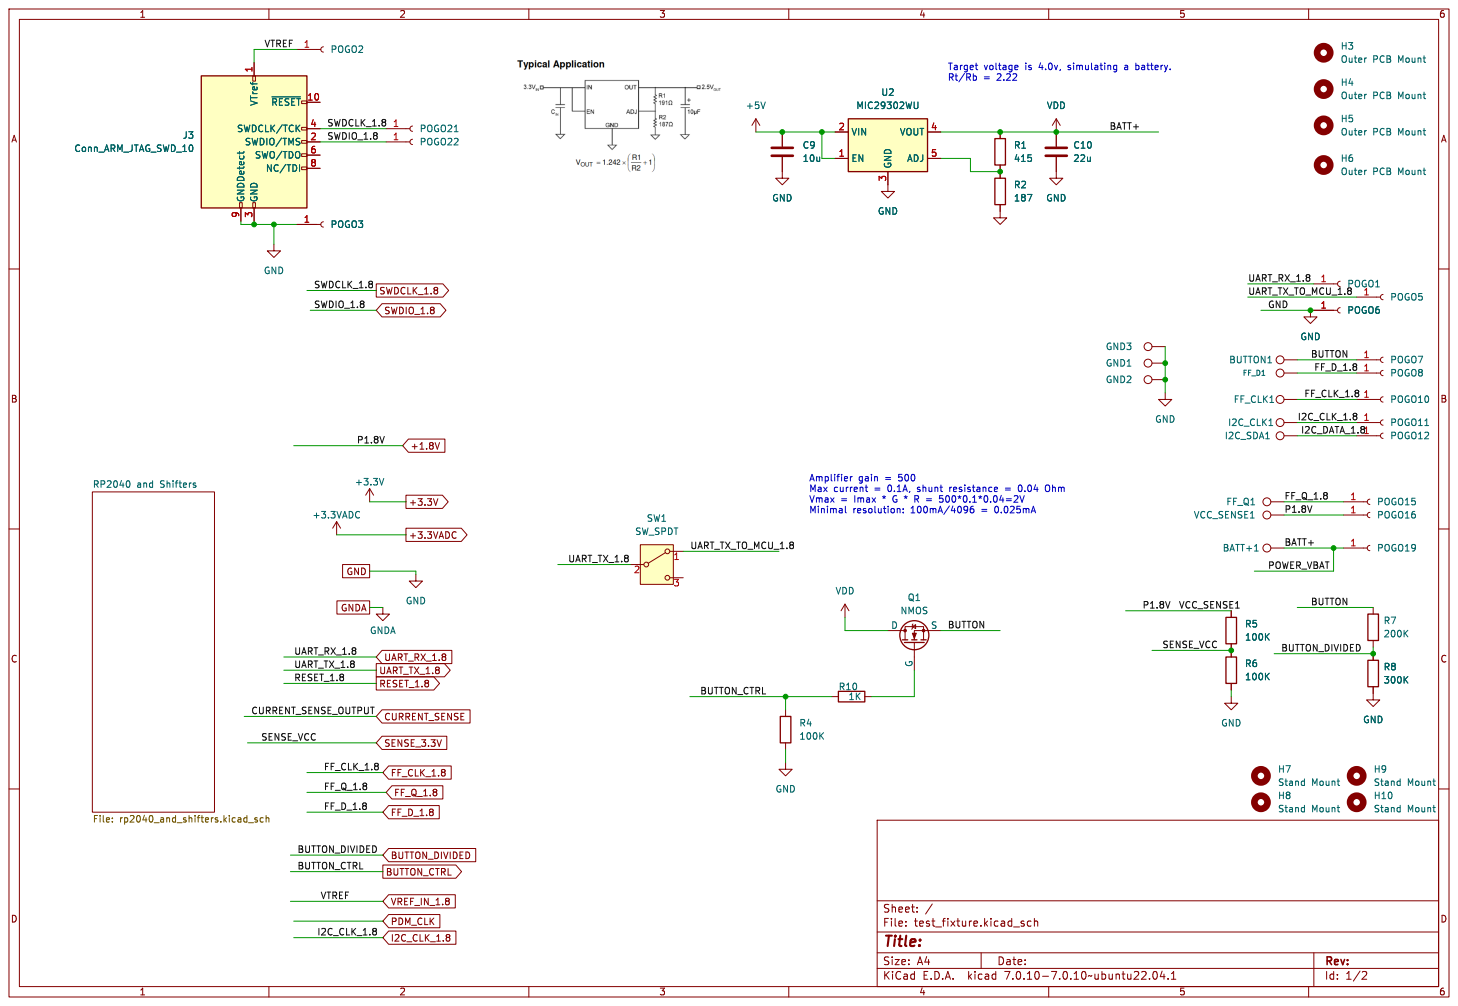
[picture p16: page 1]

3 SWDCLK/TCK 4 SWO/TDO 6 NC/TDI 8 GNDDetect 9
BATT+ CURRENT_SENSE_OUTPUT VTREF

3 SWDCLK/TCK 4 SWO/TDO 6 NC/TDI 8 GNDDetect 9 C9

Id: 1/2 Title: File: test_fixture.kicad_sch Sheet: / RP2040 and Shifters File: rp2040_and_shifters.kicad_sch

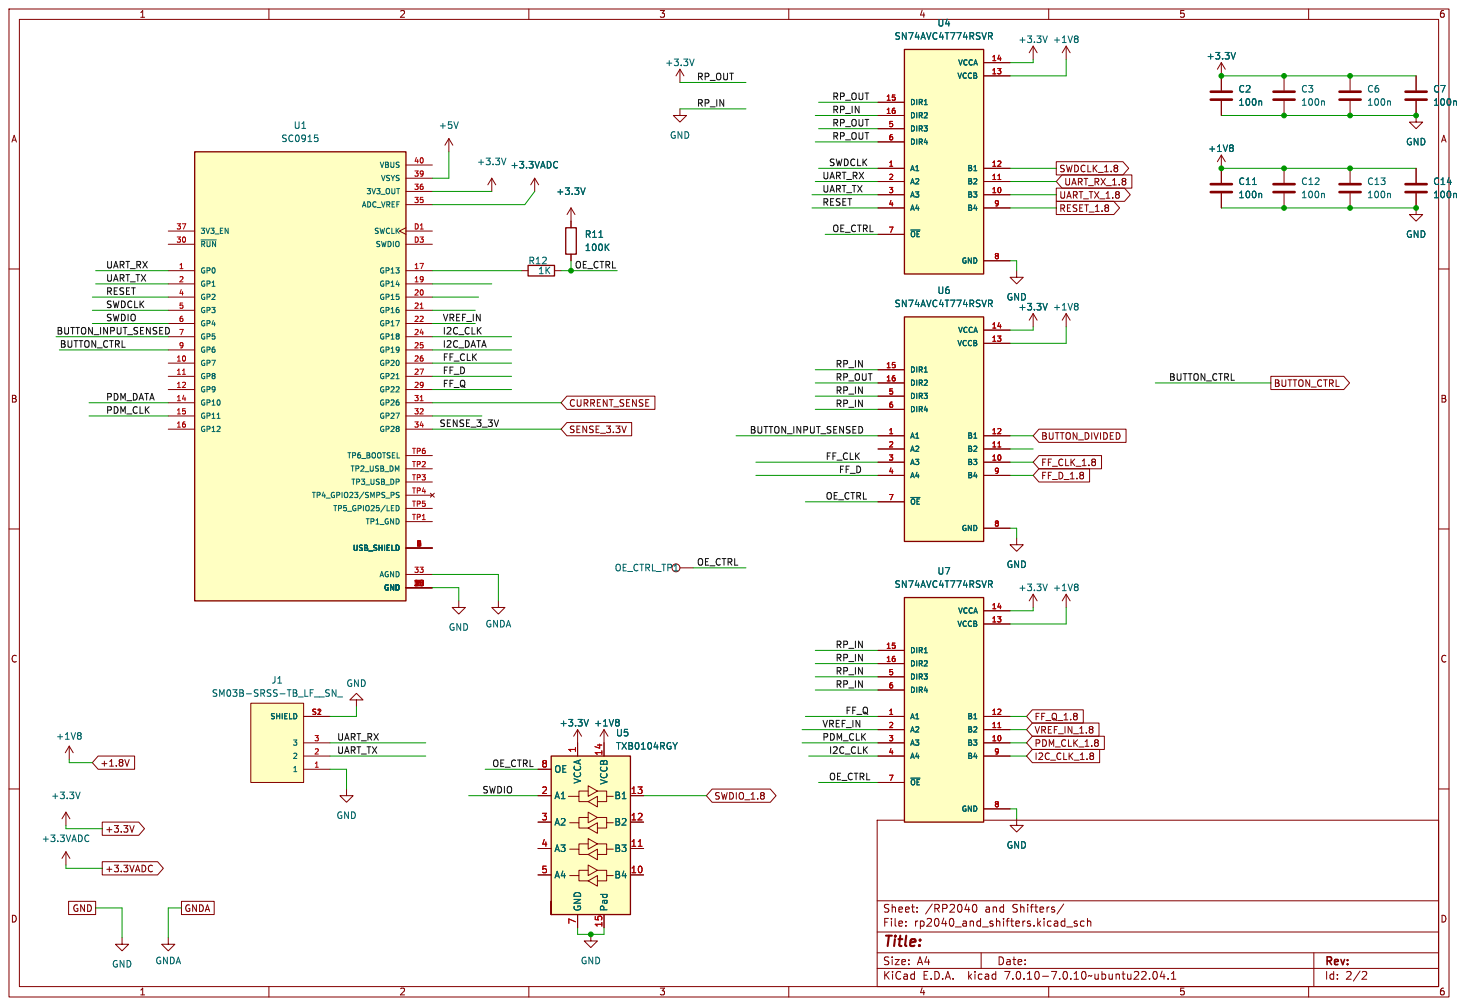
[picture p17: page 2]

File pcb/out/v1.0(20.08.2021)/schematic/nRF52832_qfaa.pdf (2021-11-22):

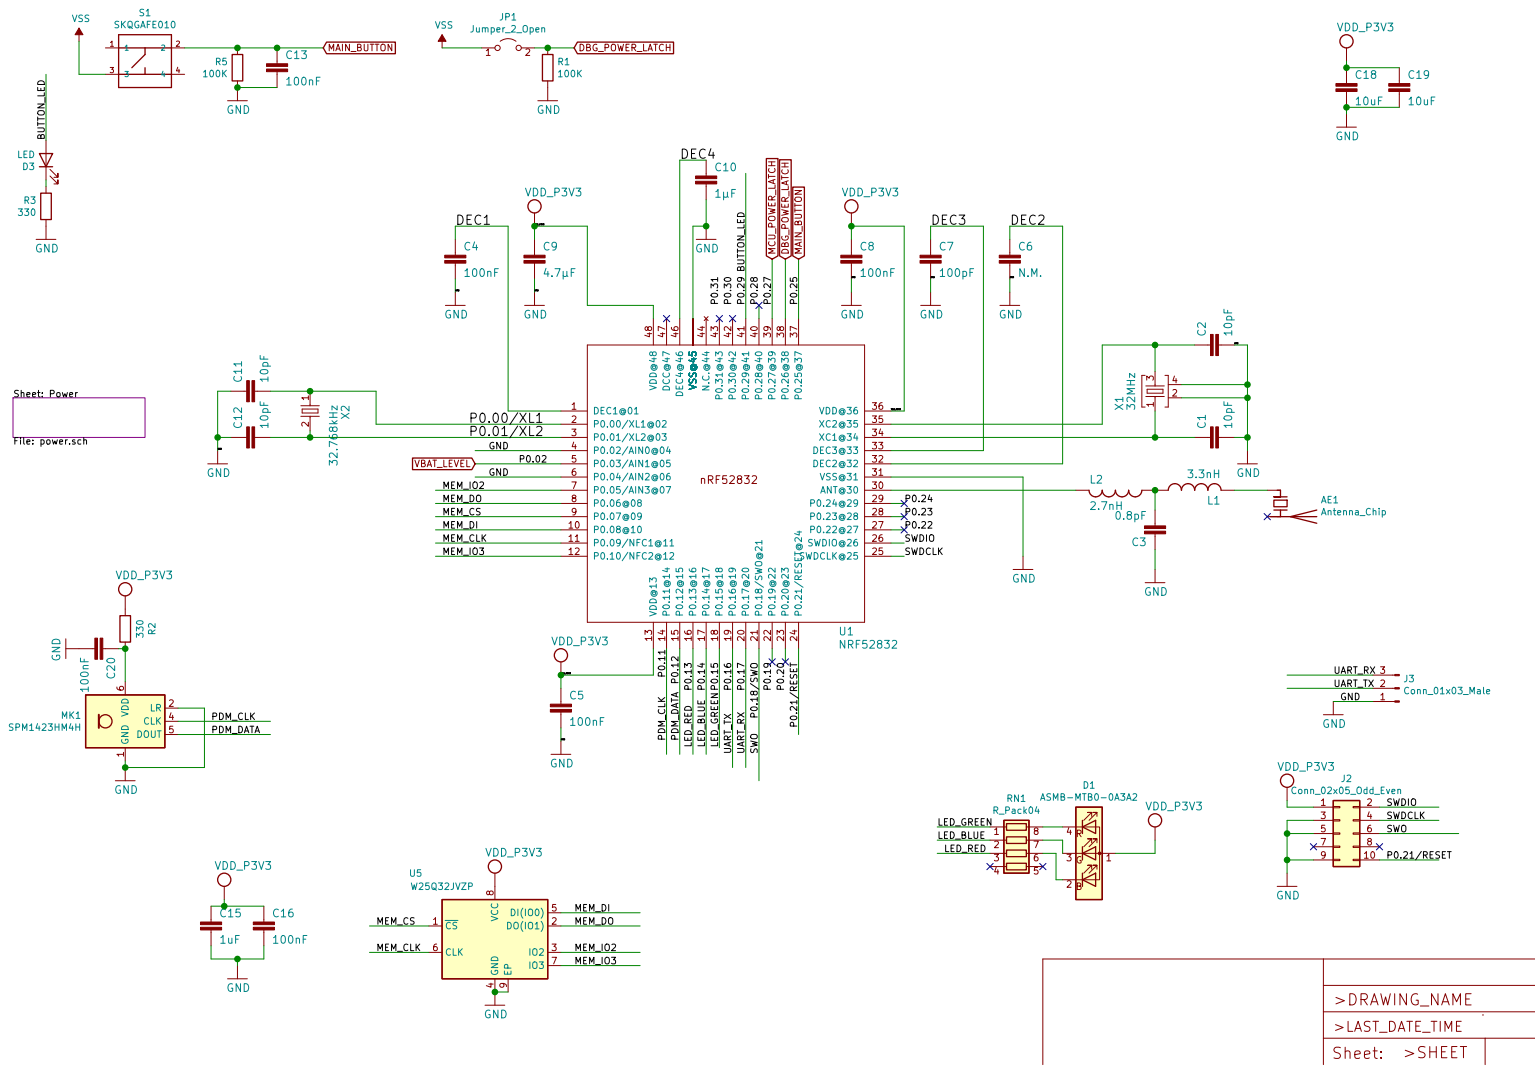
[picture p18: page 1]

Sheet: Power File: power.sch

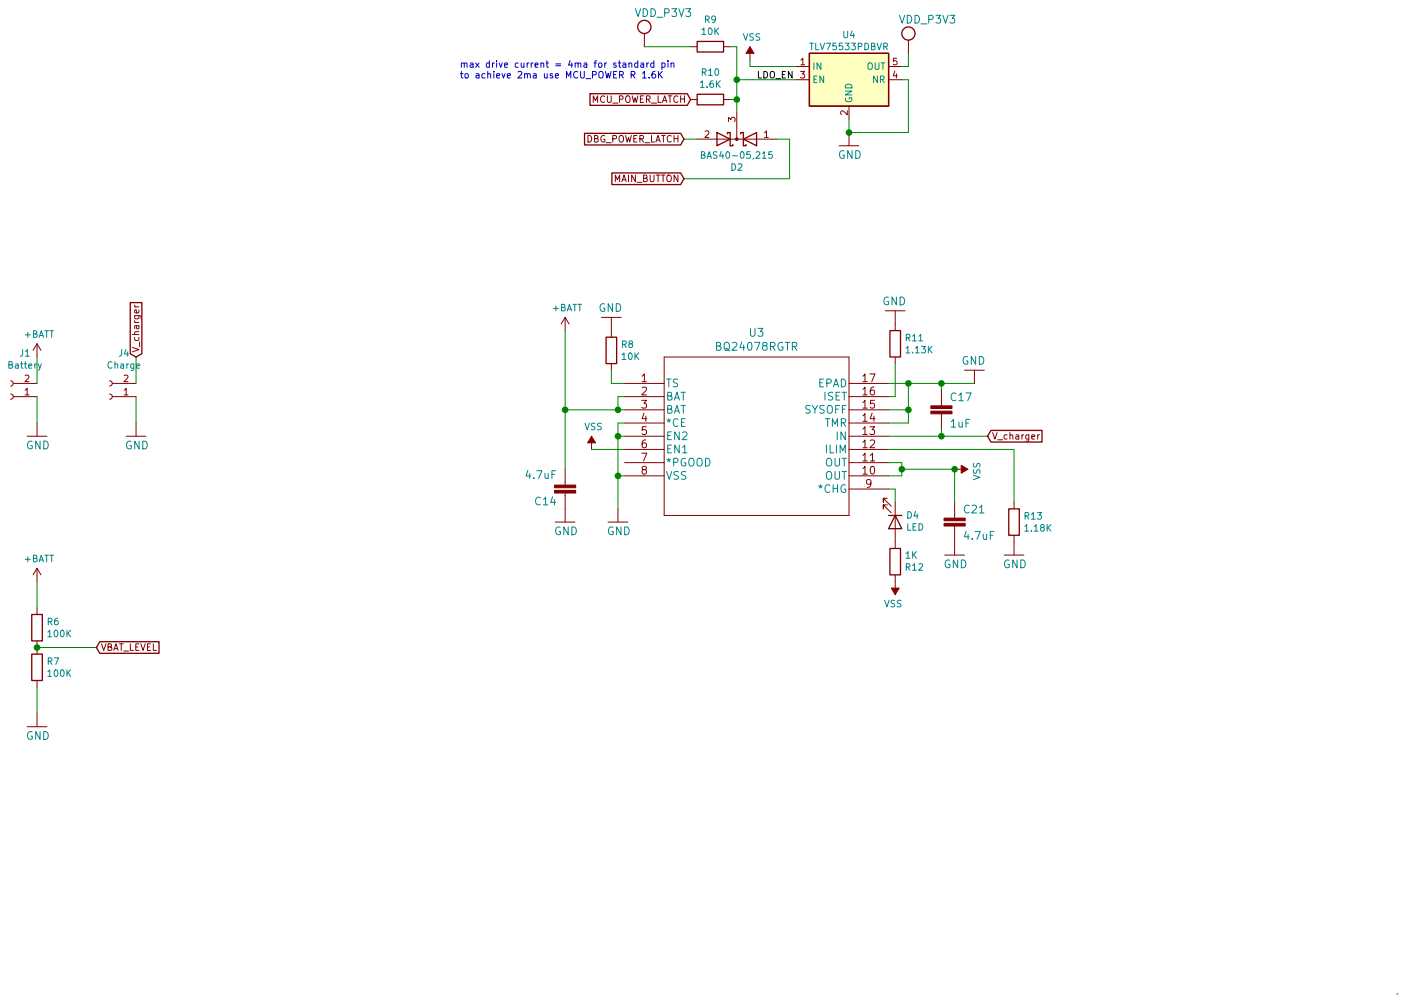
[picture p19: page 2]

LDO_EN max drive current = 4ma for standard pin
to achieve 2ma use MCU_POWER R 1.6K

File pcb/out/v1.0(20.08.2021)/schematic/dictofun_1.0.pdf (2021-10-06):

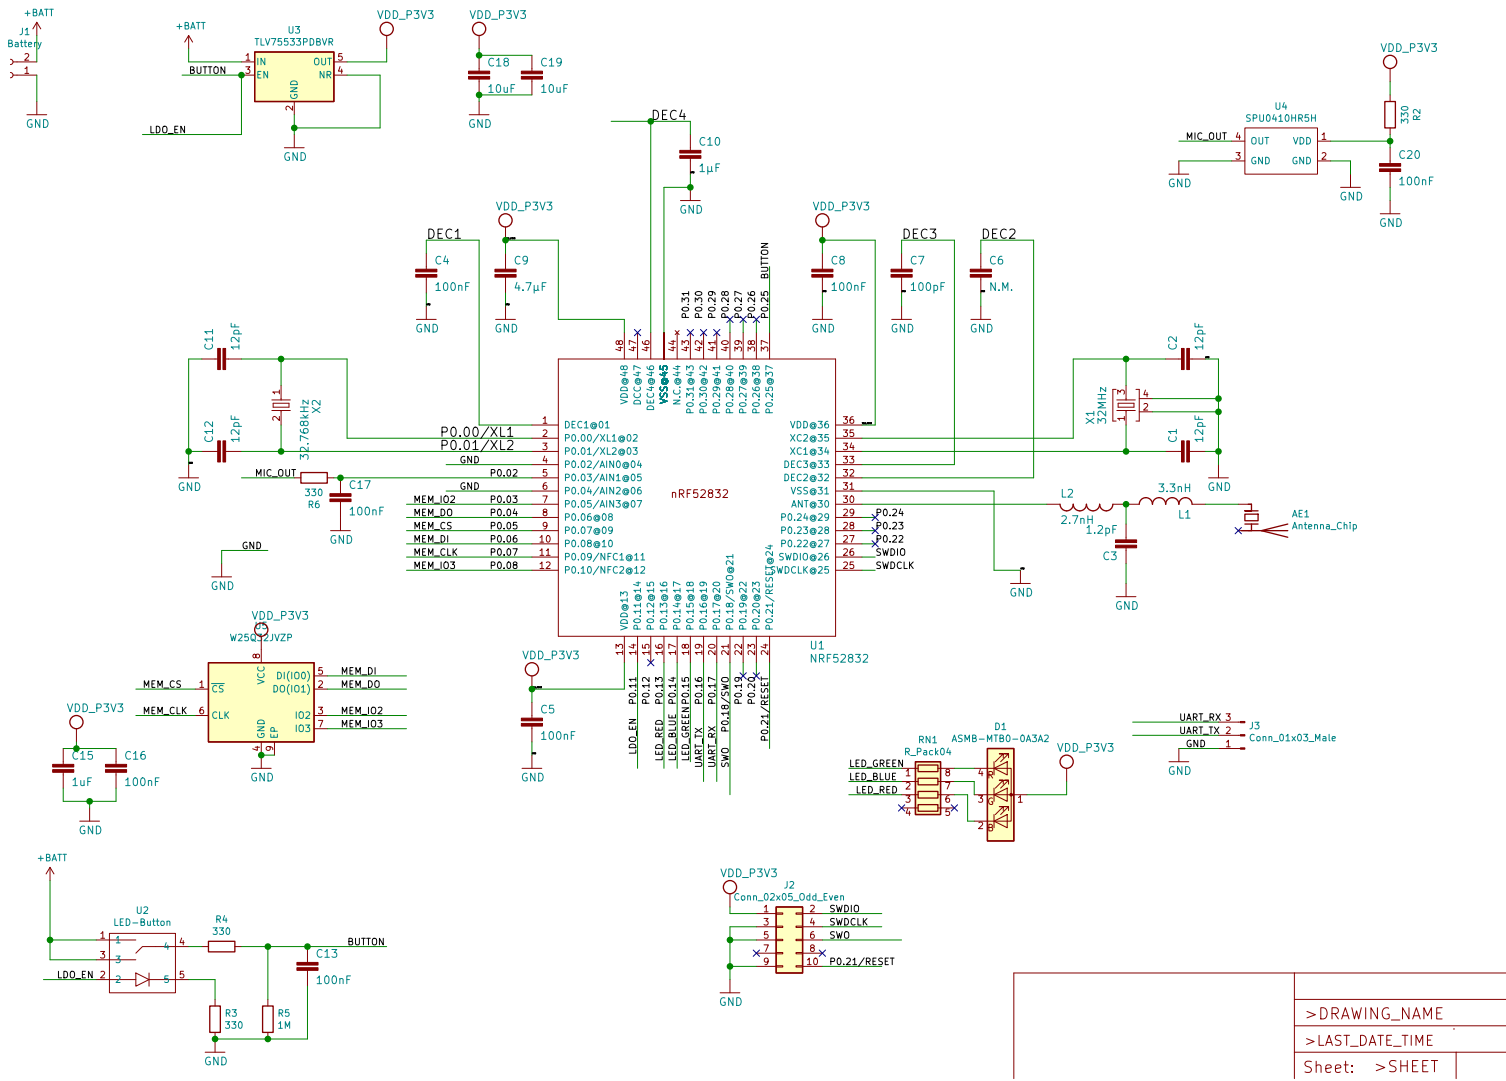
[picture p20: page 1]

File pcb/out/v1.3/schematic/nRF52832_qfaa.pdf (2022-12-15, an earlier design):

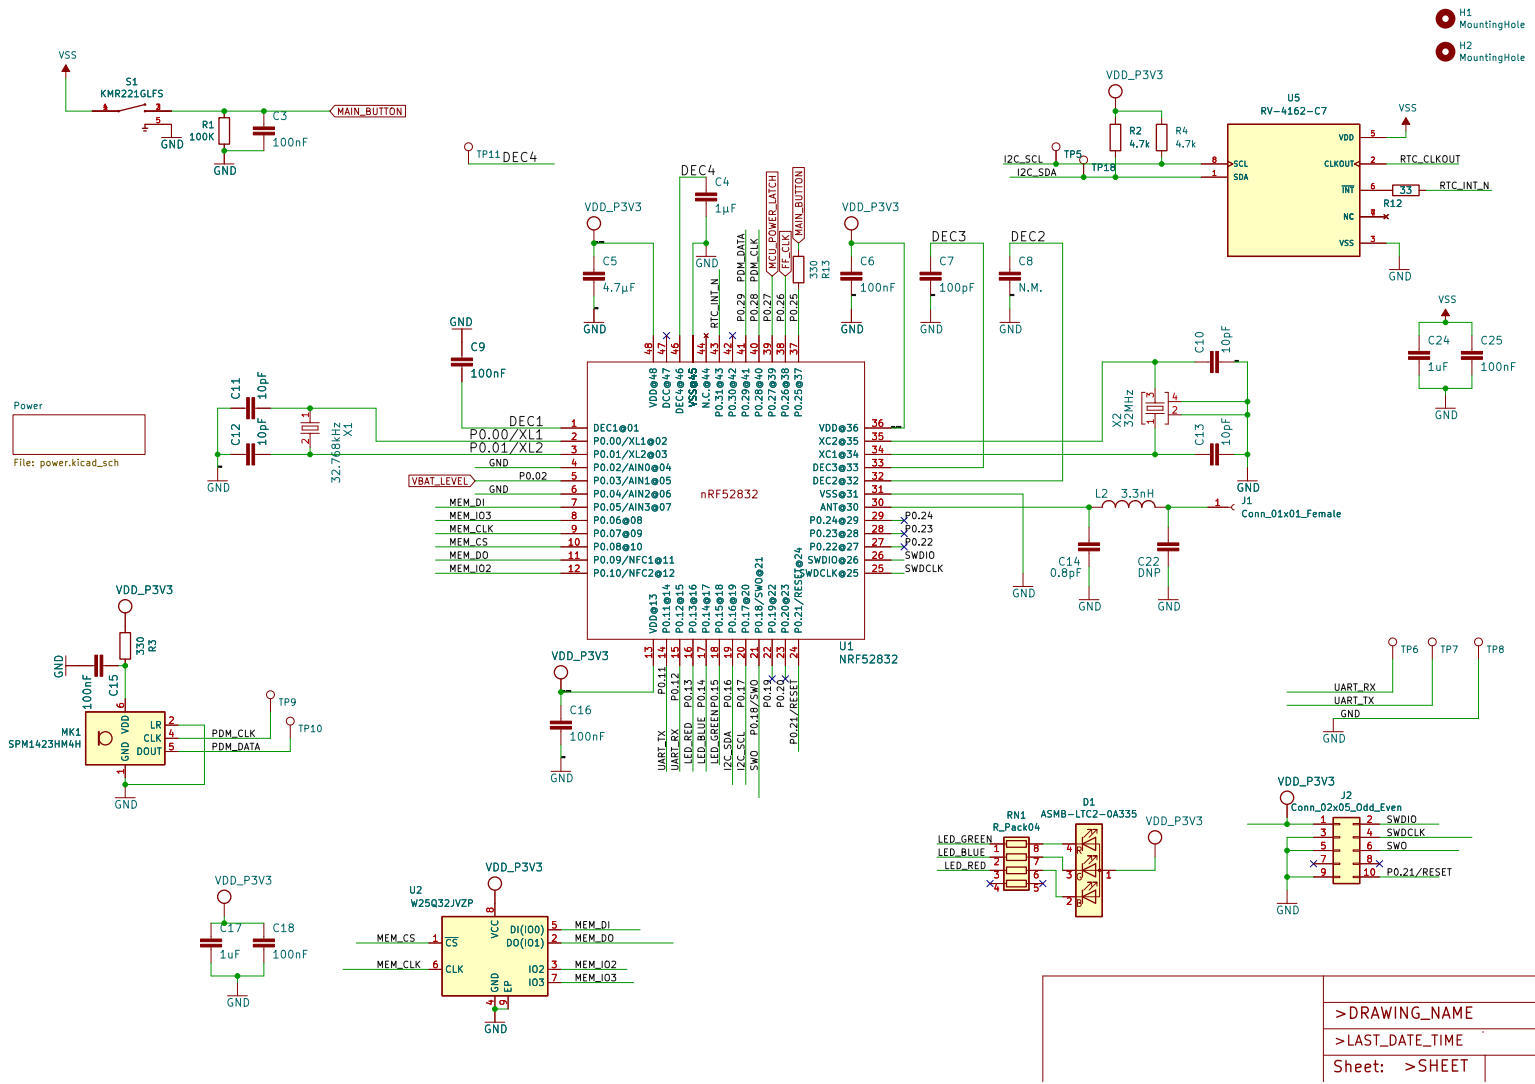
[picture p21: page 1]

9 U2W25Q32JVZP 330 R13 nRF52832 DEC1@01 1 P0.08@10 10 P0.09/NFC1@11 11 P0.10/NFC2@12 12 VDD@13 13 P0.11@14 14 P0.12@15 15 P0.13@16 16 P0.14@17 17 P0.15@18 18 P0.16@19 19 P0.00/XL1@02 2 P0.17@20 20 P0.18/SWO@21 21 P0.19@22 22 P0.20@23 23 P0.21/RESET@24 24 SWDCLK@25 25 SWDIO@26 26 P0.22@27 27 P0.23@28 28 P0.24@29 29 P0.01/XL2@03 3 ANT@30 30 VSS@31 31 DEC2@32 32 DEC3@33 33 XC1@34 34 XC2@35 35 VDD@36 36 P0.25@37 37 P0.26@38 38 P0.27@39 39 P0.02/AIN0@04 4 P0.28@40 40 P0.29@41 41 P0.30@42 42 P0.31@43 43 N.C.@44 44 VSS@45 DEC4@46 46 DCC@47 47 VDD@48 48 P0.03/AIN1@05 5 P0.04/AIN2@06 6 P0.05/AIN3@07 7 P0.06@08 8 P0.07@09 9 VSS@45 U1 VDD_P3V3 NRF52832 VDD_P3V3 GND C10 10pF C22 DNP

VDD_P3V3 PDM_DATA
Power File: power.kicad_sch GND

6 VDD_P3V3 U1NRF52832 DEC1@01 1 P0.08@10 10 P0.09/NFC1@11 11 P0.10/NFC2@12 12 VDD@13 13 P0.11@14 14 P0.12@15 15 P0.13@16 16 P0.14@17 17 P0.15@18 18 P0.16@19 19 P0.00/XL1@02 2 P0.17@20 20 P0.18/SWO@21 21 P0.19@22 22 P0.20@23 23 P0.21/RESET@24 24 SWDCLK@25 25 SWDIO@26 26 P0.22@27 27 P0.23@28 28 P0.24@29 29 P0.01/XL2@03 3 ANT@30 30 VSS@31 31 DEC2@32 32 DEC3@33 33 XC1@34 34 XC2@35 35 VDD@36 36 P0.25@37 37 P0.26@38 38 P0.27@39 39 P0.02/AIN0@04 4 P0.28@40 40 P0.29@41 41 P0.30@42 42 P0.31@43 43 N.C.@44 44 VSS@45 DEC4@46 46 DCC@47 47 VDD@48 48 P0.03/AIN1@05 5 P0.04/AIN2@06 6 P0.05/AIN3@07 7 P0.06@08 8 P0.07@09 9 VSS@45 U2W25Q32JVZP

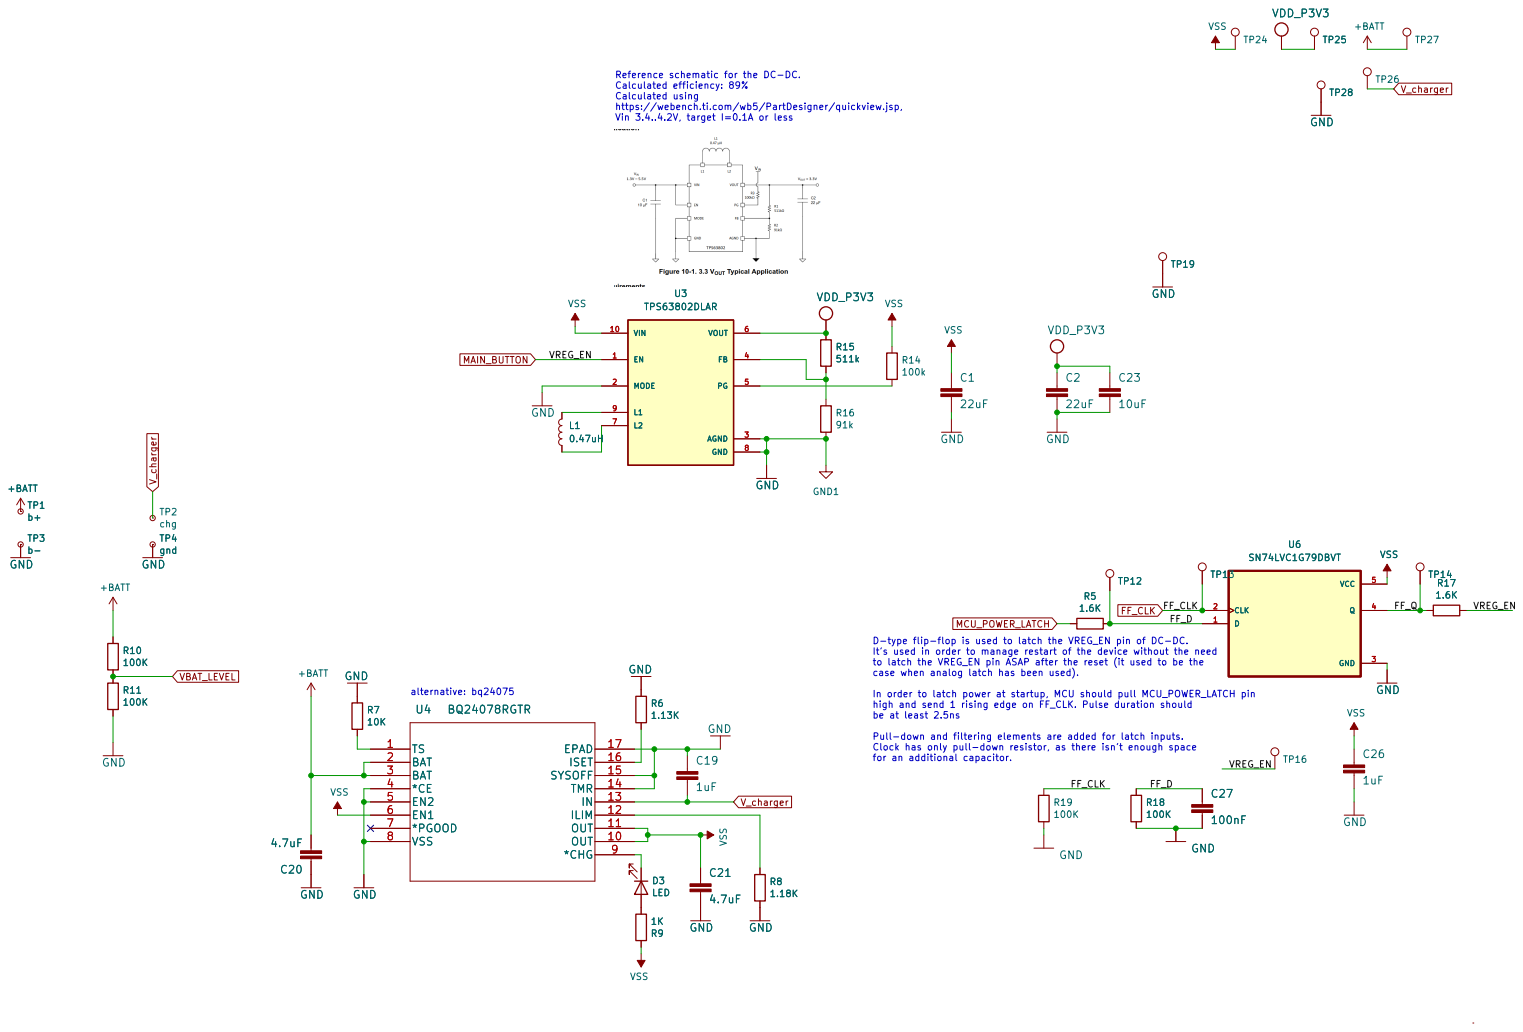
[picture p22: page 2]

Reference schematic for the DC-DC. Calculated efficiency: 89%

Calculated using
https://webench.ti.com/wb5/PartDesigner/quickview.jsp,

D-type flip-flop is used to latch the VREG_EN pin of DC-DC.
It's used in order to manage restart of the device without the need
to latch the VREG_EN pin ASAP after the reset (it used to be the
case when analog latch has been used).

In order to latch power at startup, MCU should pull MCU_POWER_LATCH pin
high and send 1 rising edge on FF_CLK. Pulse duration should be at least 2.5ns Pull-down and filtering elements are added for latch inputs.

Clock has only pull-down resistor, as there isn't enough space
for an additional capacitor.

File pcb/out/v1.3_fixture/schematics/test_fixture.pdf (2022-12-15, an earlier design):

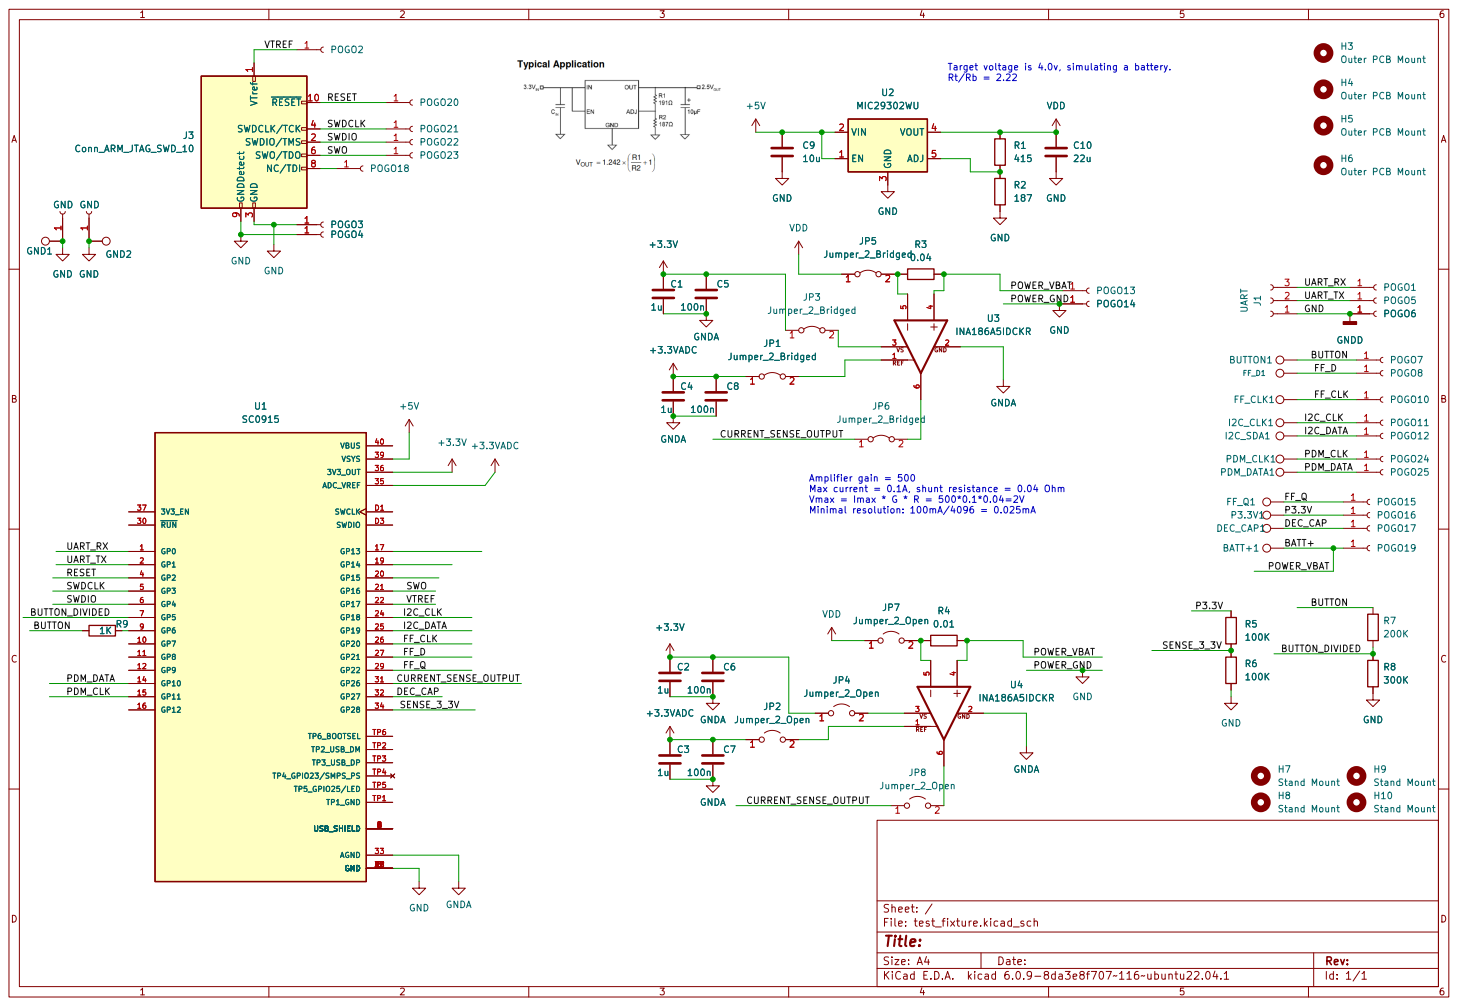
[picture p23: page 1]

3 SWDCLK/TCK 4 SWO/TDO 6 NC/TDI 8 GNDDetect 9 GND2 POGO3 1 POGO4 1 GND

3 SWDCLK/TCK 4 SWO/TDO 6 NC/TDI 8 GNDDetect 9

3 VOUT 4 ADJ 5 POGO14 1 GND GNDA R5

Amplifier gain = 500 Max current = 0.1A, shunt resistance = 0.04 Ohm

Vmax = Imax * G * R = 500*0.1*0.04=2V Minimal resolution: 100mA/4096 = 0.025mA

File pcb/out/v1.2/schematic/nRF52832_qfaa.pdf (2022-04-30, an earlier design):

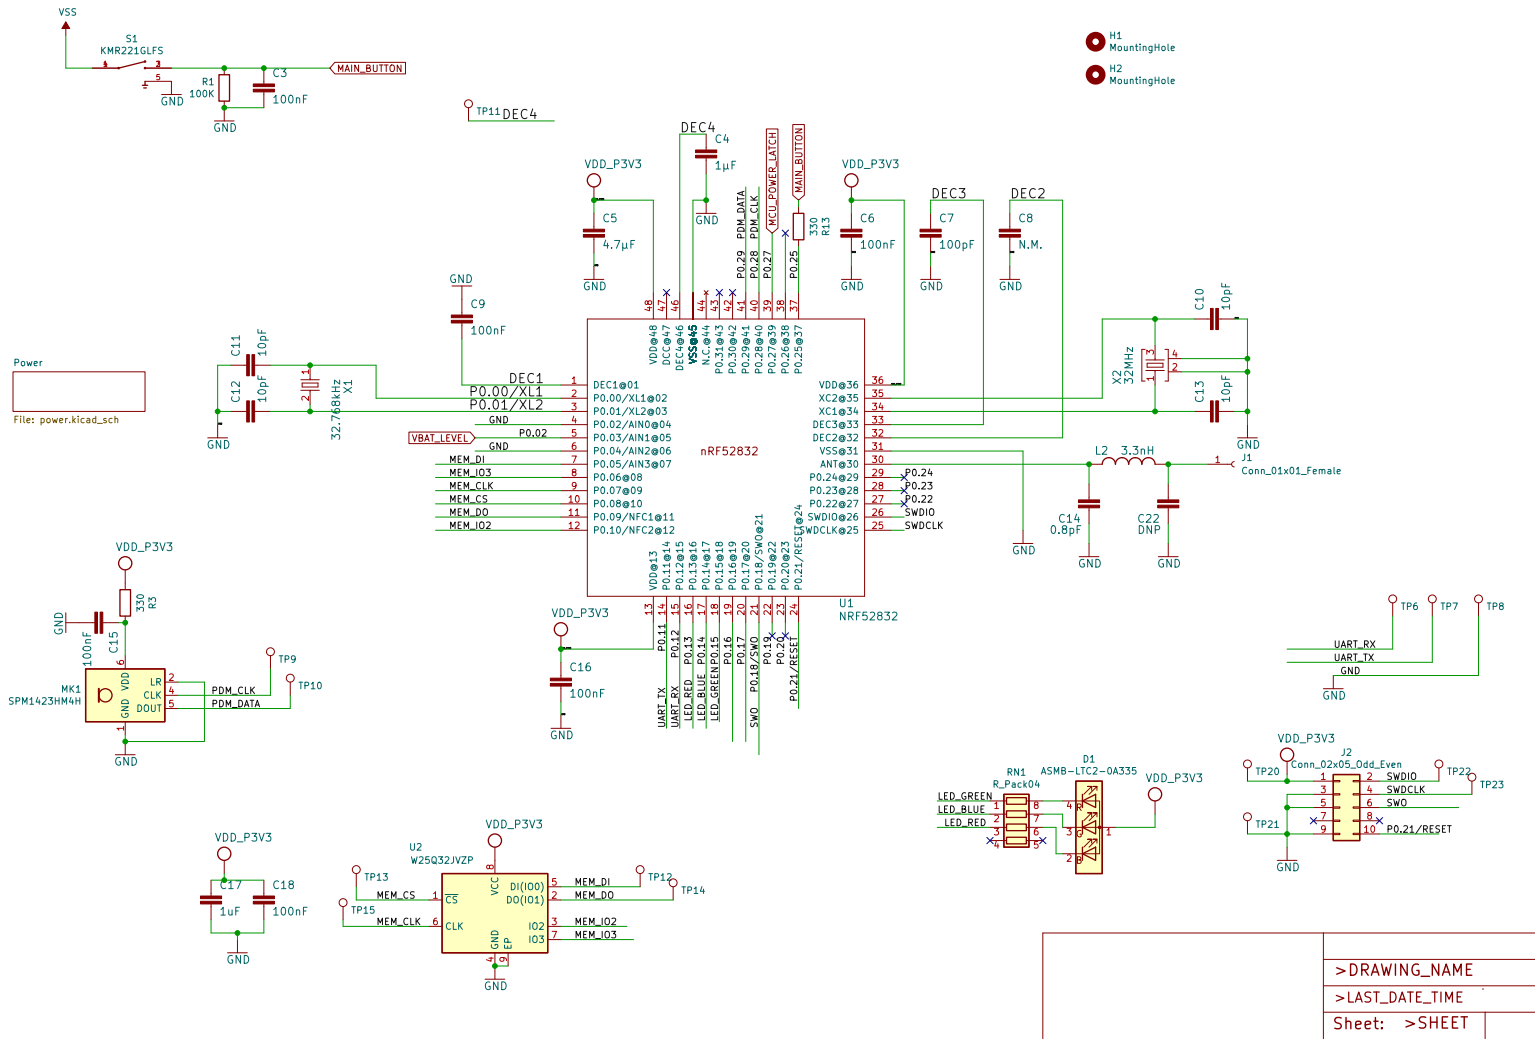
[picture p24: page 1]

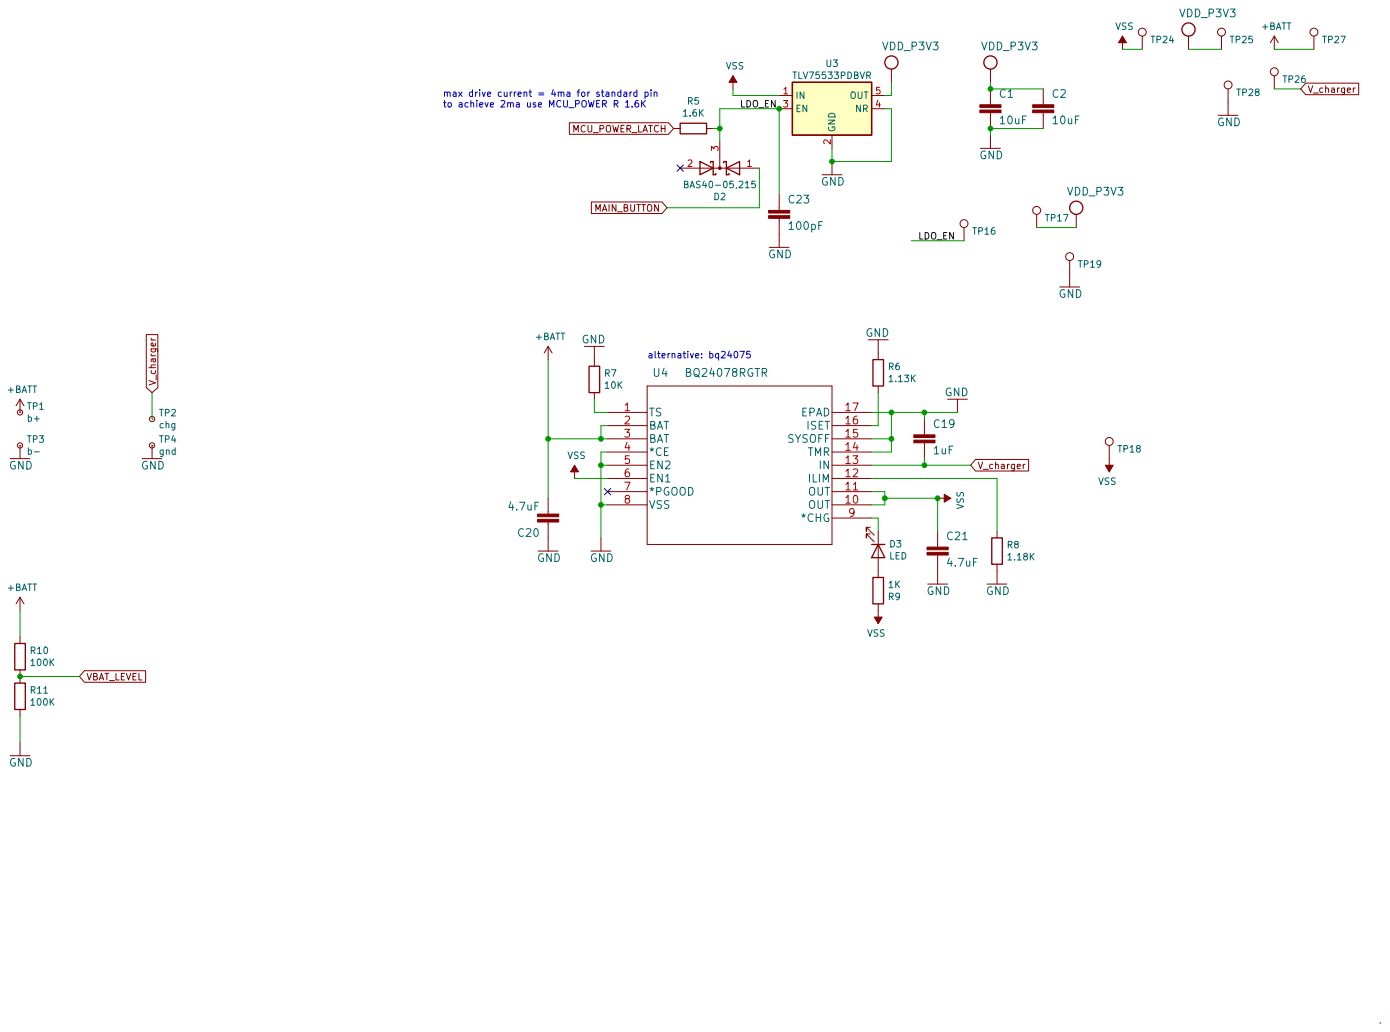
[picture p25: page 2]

max drive current = 4ma for standard pin
to achieve 2ma use MCU_POWER R 1.6K

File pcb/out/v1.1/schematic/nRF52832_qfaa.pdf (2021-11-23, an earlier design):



max drive current = 4ma for standard pin
to achieve 2ma use MCU_POWER R 1.6K

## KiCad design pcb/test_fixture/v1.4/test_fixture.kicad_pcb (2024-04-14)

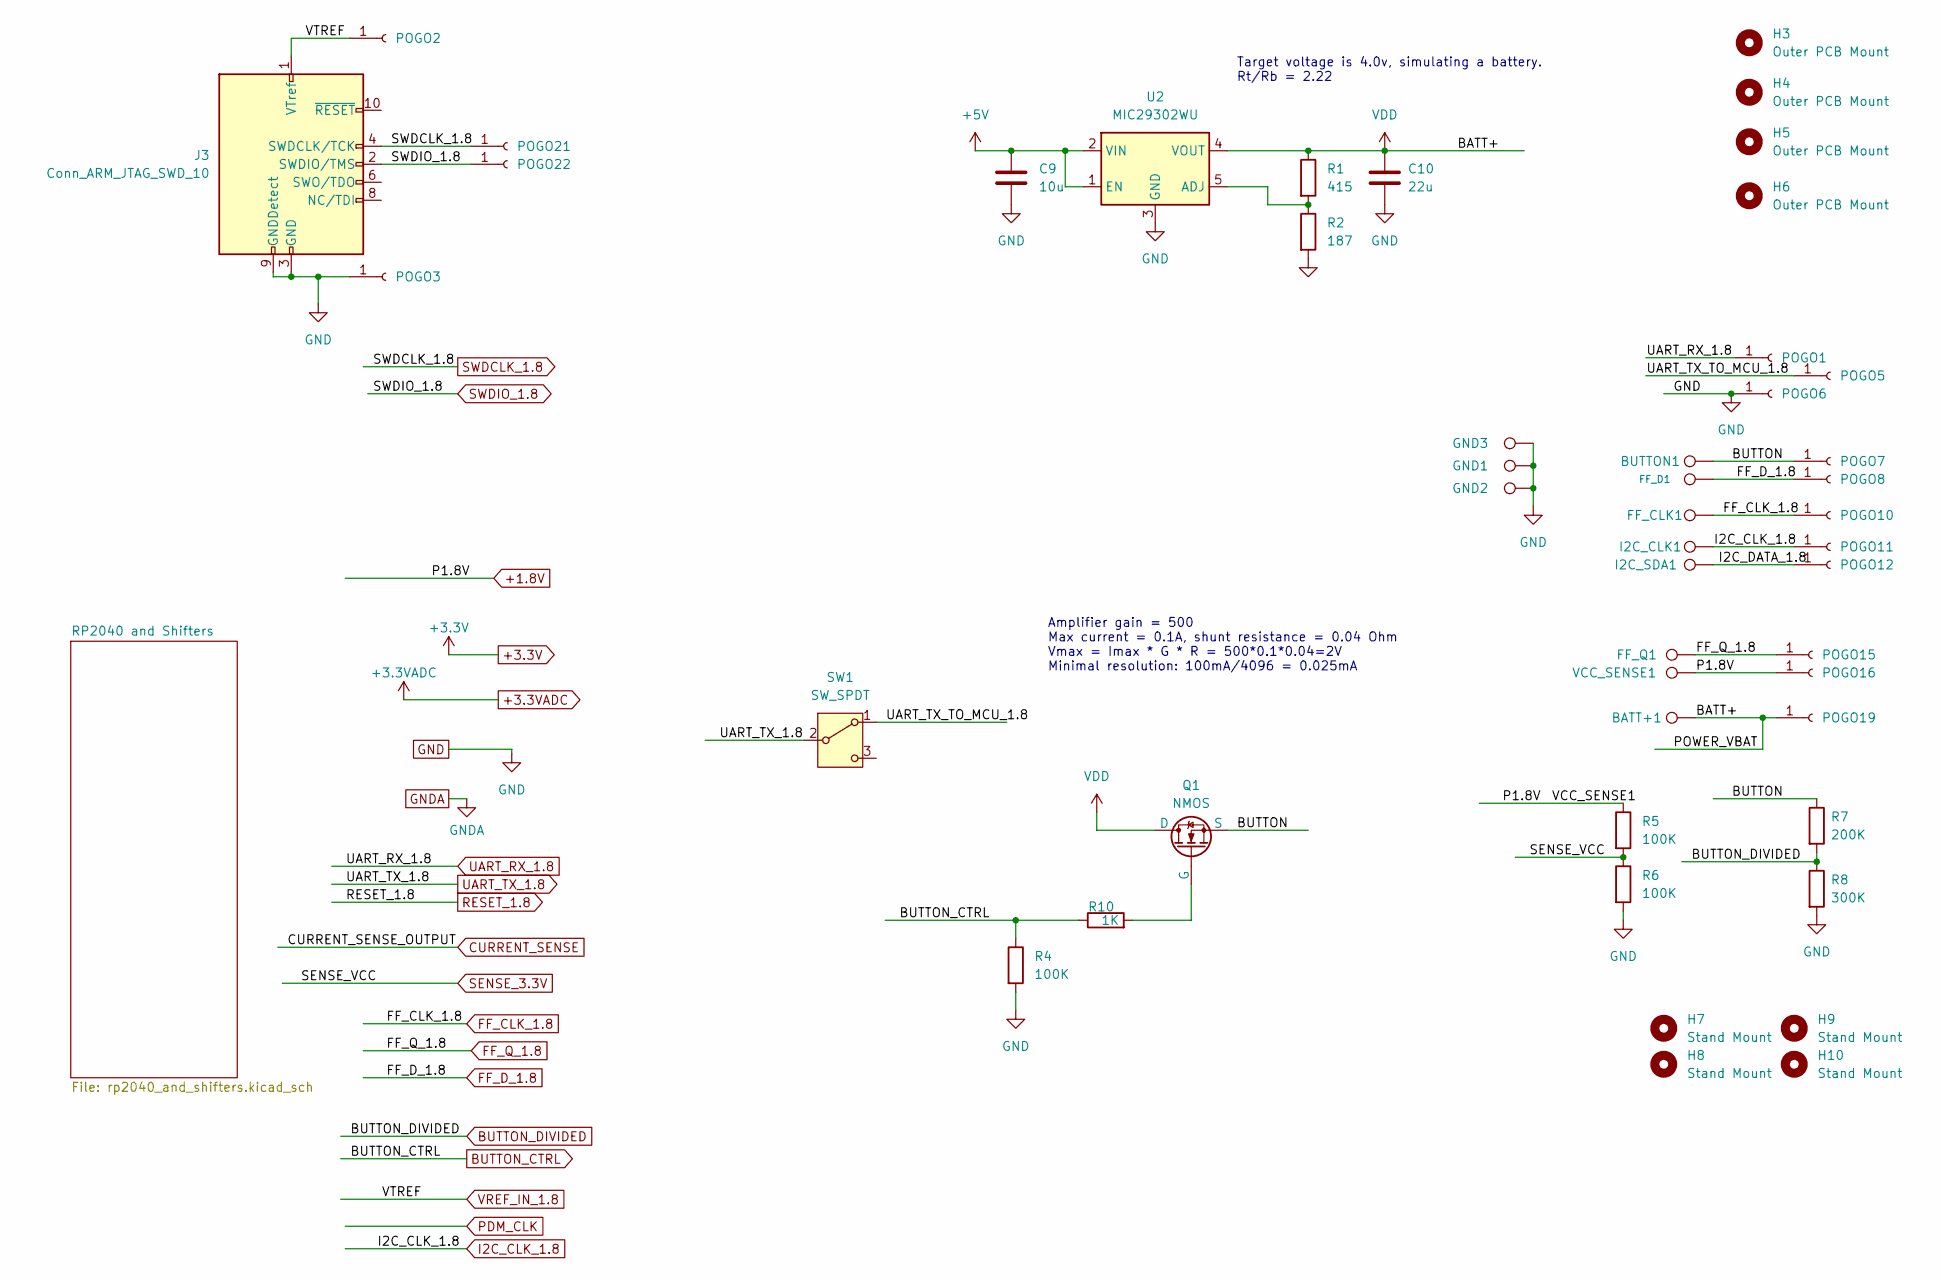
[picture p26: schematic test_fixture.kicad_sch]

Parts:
BATT+1: TestPoint_Pad_D1.5mm
BUTTON1: TestPoint_Pad_D1.5mm
C9: 10u; R_1206_3216Metric; LCSC C165101
C10: 22u; C_1206_3216Metric; LCSC C92818
FF_CLK1: TestPoint_Pad_D1.5mm
FF_D1: TestPoint_Pad_D1.5mm
FF_Q1: TestPoint_Pad_D1.5mm
GND1, GND2, GND3: TestPoint_Pad_D1.5mm
H3, H4, H5, H6: Outer PCB Mount; MountingHole_2.1mm
H7, H8, H9, H10: Stand Mount; MountingHole_2.1mm
I2C_CLK1, I2C_SDA1: TestPoint_Pad_D1.5mm
J3: Conn_ARM_JTAG_SWD_10; PinHeader_2x05_P1.27mm_Vertical_SMD
POGO1, POGO2, POGO3, POGO5, POGO6, POGO7, POGO8, POGO10, POGO11, POGO12, POGO15, POGO16, POGO19, POGO21, POGO22: pogo; POGO
Q1: NMOS; SOT-23; LCSC C916396
R1: 415; R_0603_1608Metric; LCSC C114669
R2: 187; R_0603_1608Metric; LCSC C22828
R4, R5, R6: 100K; R_0603_1608Metric; LCSC C122538
R7: 200K; R_0603_1608Metric; LCSC C118142
R8: 300K; R_0603_1608Metric; LCSC C103526
R10: 1K; R_0603_1608Metric; LCSC C375503
SW1: SW_SPDT; K3-1235S-f1; LCSC C92660
U2: MIC29302WU; TO-263-5_TabPin3; LCSC C11149
VCC_SENSE1: TestPoint_Pad_D1.5mm

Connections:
+1.8V: POGO16.1, R5.1, VCC_SENSE1.1; also elsewhere on the board
+5V: C9.1, U2.1 (EN), U2.2 (VIN); also elsewhere on the board
/BUTTON: BUTTON1.1, POGO7.1, Q1.3 (S), R7.1
/I2C_DATA_1.8: I2C_SDA1.1, POGO12.1
/UART_TX_TO_MCU_1.8: POGO5.1, SW1.1 (A)
BUTTON_CTRL: R4.1, R10.1; also elsewhere on the board
BUTTON_DIVIDED: R7.2, R8.1; also elsewhere on the board
FF_CLK_1.8: FF_CLK1.1, POGO10.1; also elsewhere on the board
FF_D_1.8: FF_D1.1, POGO8.1; also elsewhere on the board
FF_Q_1.8: FF_Q1.1, POGO15.1; also elsewhere on the board
GND: C9.2, C10.2, GND1.1, GND2.1, GND3.1, J3.3 (GND), J3.5 (GND), J3.9 (GNDDetect), POGO3.1, POGO6.1, R2.2, R4.2, R6.2, R8.2, U2.3 (GND); also elsewhere on the board
I2C_CLK_1.8: I2C_CLK1.1, POGO11.1; also elsewhere on the board
unnamed: Q1.2 (G), R10.2
unnamed: R1.2, R2.1, U2.5 (ADJ)
SENSE_3.3V: R5.2, R6.1; also elsewhere on the board
SWDCLK_1.8: J3.4 (SWDCLK/TCK), POGO21.1; also elsewhere on the board
SWDIO_1.8: J3.2 (SWDIO/TMS), POGO22.1; also elsewhere on the board
UART_RX_1.8: POGO1.1; also elsewhere on the board
UART_TX_1.8: SW1.2 (B); also elsewhere on the board
VDD: BATT+1.1, C10.1, POGO19.1, Q1.1 (D), R1.1, U2.4 (VOUT)
VREF_IN_1.8: J3.1 (VTref), POGO2.1; also elsewhere on the board

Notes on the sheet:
Amplifier gain = 500 Max current = 0.1A, shunt resistance = 0.04 Ohm Vmax = Imax * G * R = 500*0.1*0.04=2V Minimal resolution: 100mA/4096 = 0.025mA
Target voltage is 4.0v, simulating a battery. Rt/Rb = 2.22

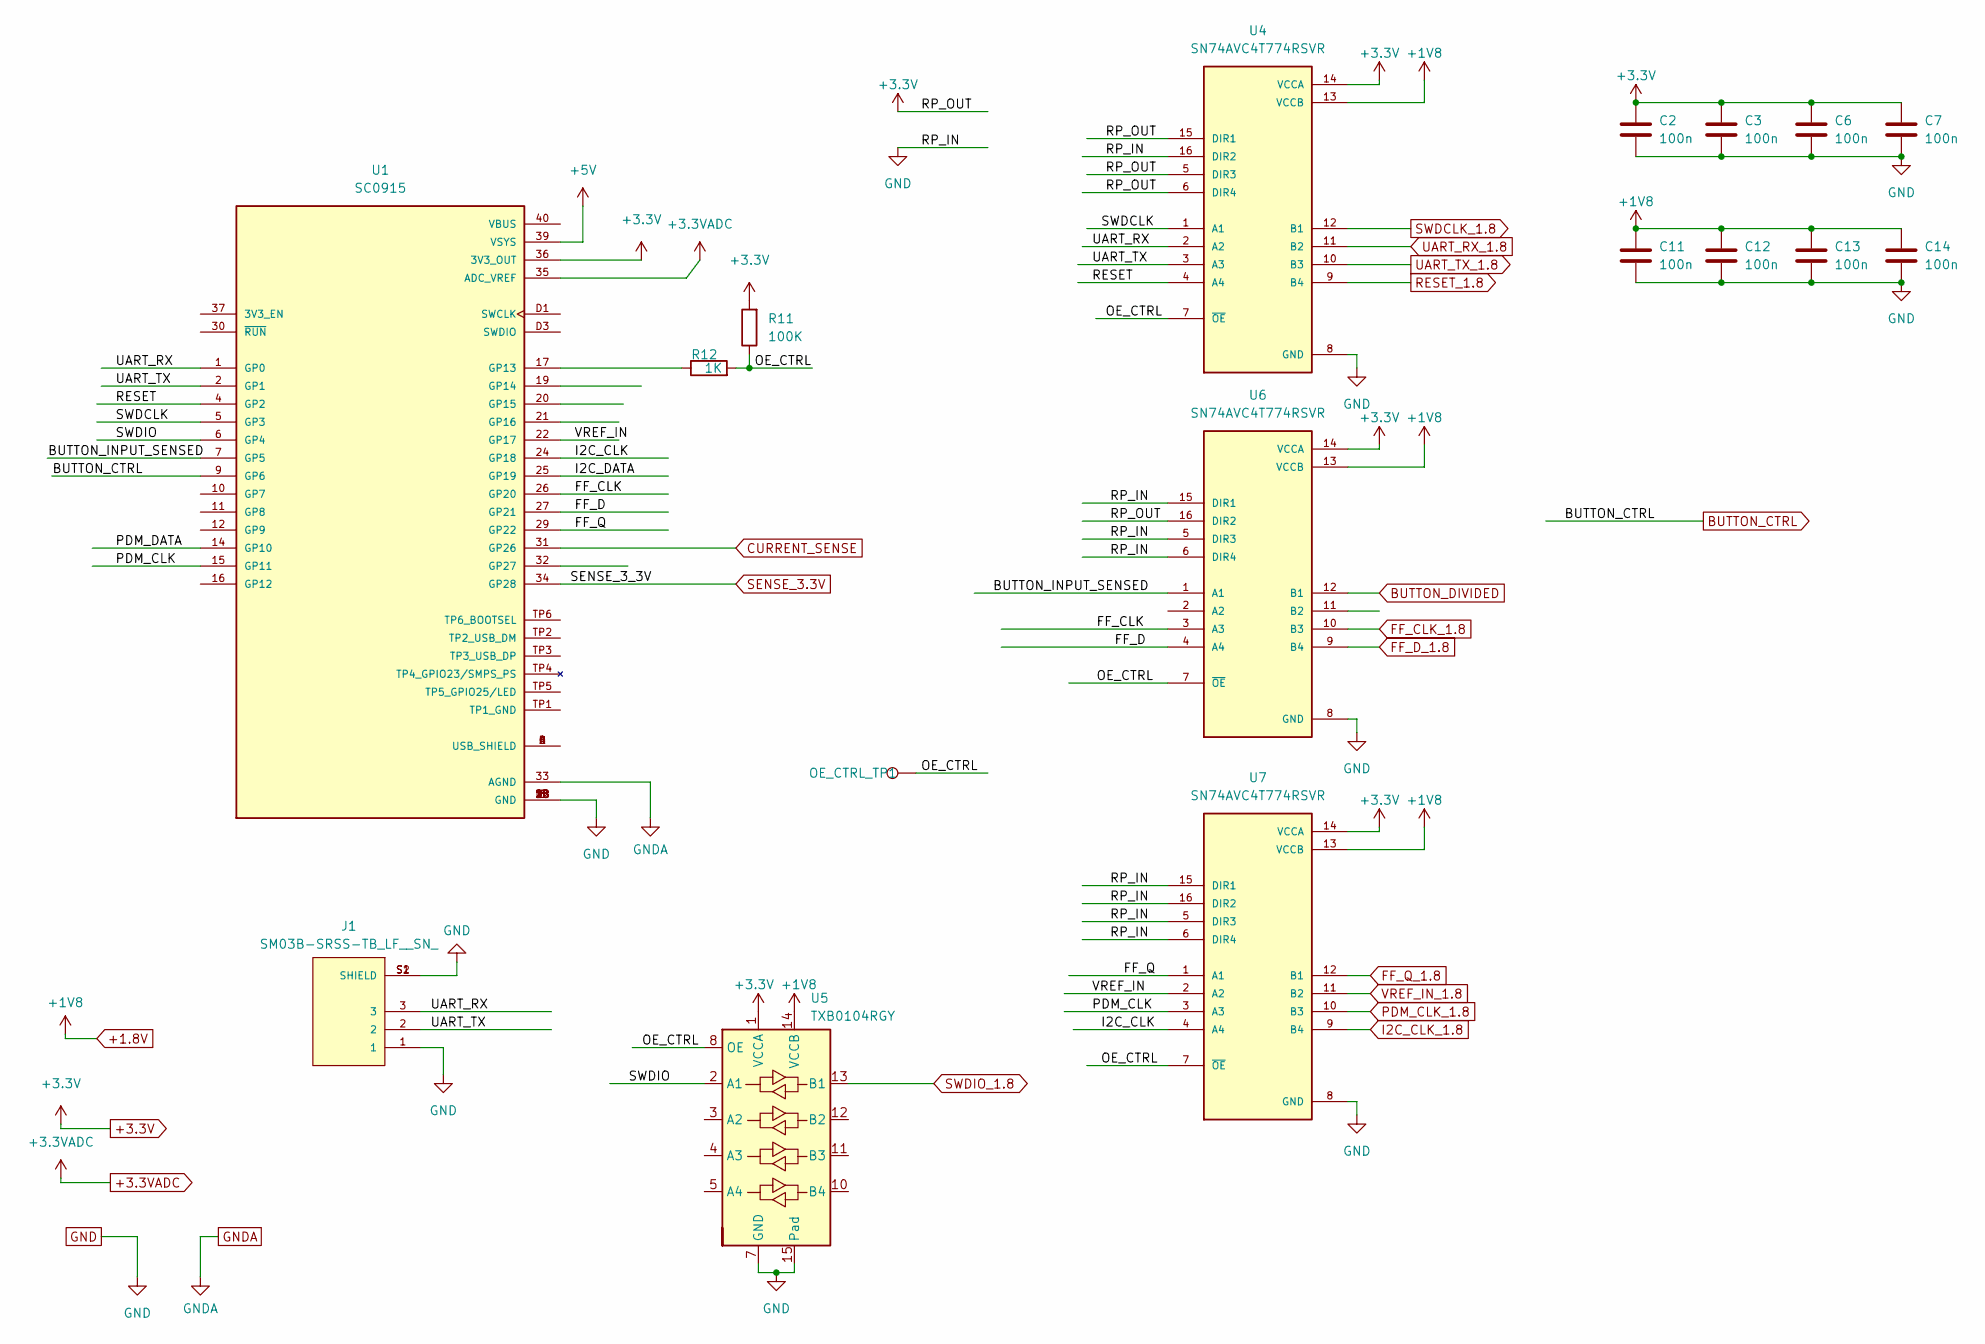
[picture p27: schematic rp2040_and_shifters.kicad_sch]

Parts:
C2, C3, C6, C7, C11, C12, C13, C14: 100n; C_0402_1005Metric; LCSC C1525
J1: SM03B-SRSS-TB_LF__SN_; JST_SM03B-SRSS-TB_LF__SN_
OE_CTRL_TP1: TestPoint_Pad_D1.5mm
R11: 100K; R_0603_1608Metric; LCSC C122538
R12: 1K; R_0603_1608Metric
U1: SC0915; MODULE_SC0915; PARTREV 1.6
U4, U6, U7: SN74AVC4T774RSVR; QFN40P260X180X55-16N; PARTREV E; LCSC C1849454
U5: TXB0104RGY; Texas_S-PVQFN-N14; LCSC C400708

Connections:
+1.8V: C11.1, C12.1, C13.1, C14.1, U4.13 (VCCB), U5.14 (VCCB), U6.13 (VCCB), U7.13 (VCCB); also elsewhere on the board
+3.3V: C2.1, C3.1, C6.1, C7.1, R11.2, U1.36 (3V3_OUT), U4.5 (DIR3), U4.6 (DIR4), U4.14 (VCCA), U4.15 (DIR1), U5.1 (VCCA), U6.14 (VCCA), U6.16 (DIR2), U7.14 (VCCA)
+3.3VADC: U1.35 (ADC_VREF)
+5V: U1.39 (VSYS); also elsewhere on the board
/RP2040 and Shifters/BUTTON_INPUT_SENSED: U1.7 (GP5), U6.1 (A1)
/RP2040 and Shifters/FF_CLK: U1.26 (GP20), U6.3 (A3)
/RP2040 and Shifters/FF_D: U1.27 (GP21), U6.4 (A4)
/RP2040 and Shifters/FF_Q: U1.29 (GP22), U7.1 (A1)
/RP2040 and Shifters/I2C_CLK: U1.24 (GP18), U7.4 (A4)
/RP2040 and Shifters/I2C_DATA: U1.25 (GP19)
/RP2040 and Shifters/OE_CTRL: OE_CTRL_TP1.1, R11.1, R12.2, U4.7 (~OE), U5.8 (OE), U6.7 (~OE), U7.7 (~OE)
/RP2040 and Shifters/PDM_CLK: U1.15 (GP11), U7.3 (A3)
/RP2040 and Shifters/PDM_DATA: U1.14 (GP10)
/RP2040 and Shifters/RESET: U1.4 (GP2), U4.4 (A4)
/RP2040 and Shifters/SWDCLK: U1.5 (GP3), U4.1 (A1)
/RP2040 and Shifters/SWDIO: U1.6 (GP4), U5.2 (A1)
/RP2040 and Shifters/UART_RX: J1.3, U1.1 (GP0), U4.2 (A2)
/RP2040 and Shifters/UART_TX: J1.2, U1.2 (GP1), U4.3 (A3)
/RP2040 and Shifters/VREF_IN: U1.22 (GP17), U7.2 (A2)
BUTTON_CTRL: U1.9 (GP6); also elsewhere on the board
BUTTON_DIVIDED: U6.12 (B1); also elsewhere on the board
CURRENT_SENSE: U1.31 (GP26)
FF_CLK_1.8: U6.10 (B3); also elsewhere on the board
FF_D_1.8: U6.9 (B4); also elsewhere on the board
FF_Q_1.8: U7.12 (B1); also elsewhere on the board
GND: C2.2, C3.2, C6.2, C7.2, C11.2, C12.2, C13.2, C14.2, J1.1, J1.S1 (SHIELD), J1.S2 (SHIELD), U1.3 (GND), U1.8 (GND), U1.13 (GND), U1.18 (GND), U1.23 (GND), U1.28 (GND), U1.38 (GND), U1.D2 (GND), U4.8 (GND), U4.16 (DIR2), U5.7 (GND), U5.15 (Pad), U6.5 (DIR3), U6.6 (DIR4), U6.8 (GND), U6.15 (DIR1), U7.5 (DIR3), U7.6 (DIR4), U7.8 (GND), U7.15 (DIR1), U7.16 (DIR2); also elsewhere on the board
GNDA: U1.33 (AGND)
I2C_CLK_1.8: U7.9 (B4); also elsewhere on the board
unnamed: R12.1, U1.17 (GP13)
unnamed: U1.A (USB_SHIELD), U1.B (USB_SHIELD), U1.C (USB_SHIELD), U1.D (USB_SHIELD)
PDM_CLK_1.8: U7.10 (B3)
RESET_1.8: U4.9 (B4)
SENSE_3.3V: U1.34 (GP28); also elsewhere on the board
SWDCLK_1.8: U4.12 (B1); also elsewhere on the board
SWDIO_1.8: U5.13 (B1); also elsewhere on the board
UART_RX_1.8: U4.11 (B2); also elsewhere on the board
UART_TX_1.8: U4.10 (B3); also elsewhere on the board
VREF_IN_1.8: U7.11 (B2); also elsewhere on the board

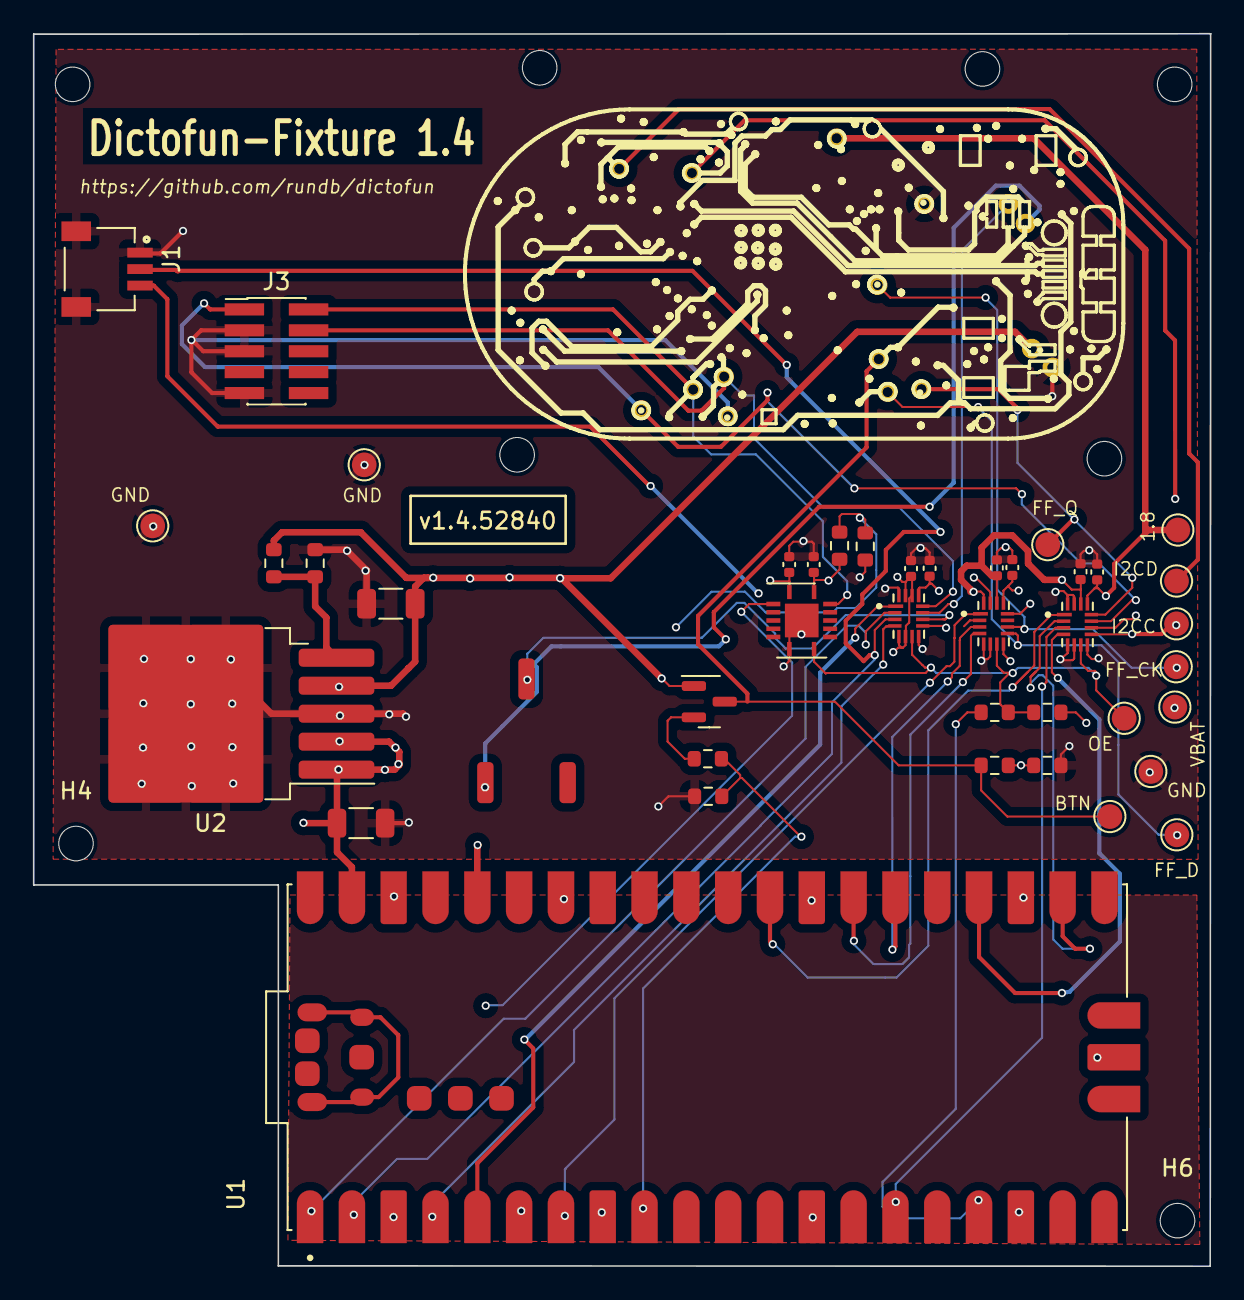
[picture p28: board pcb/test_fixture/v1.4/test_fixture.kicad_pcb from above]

Board: 4 copper layers, 71.5 x 74.9 mm, 66 parts (0 on the bottom side), 37 nets.

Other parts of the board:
POGO14: pogo; POGO

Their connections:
GND: POGO14.1; also elsewhere on the board

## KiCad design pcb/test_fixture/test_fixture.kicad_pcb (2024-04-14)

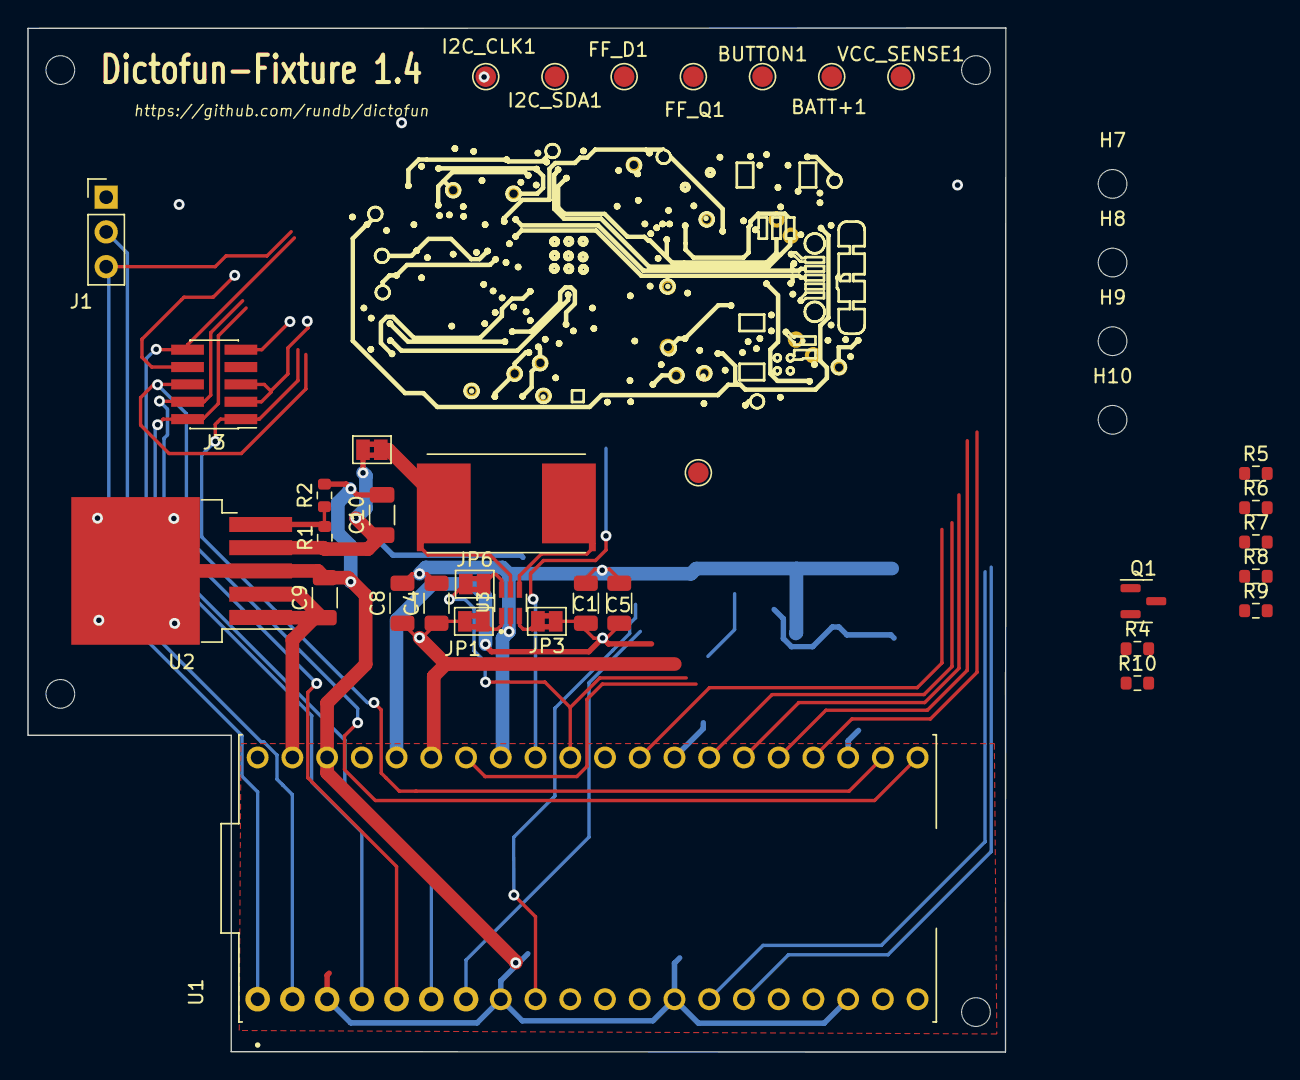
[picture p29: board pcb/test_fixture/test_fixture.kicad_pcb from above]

Board: 2 copper layers, 71.5 x 74.9 mm, 59 parts (0 on the bottom side), 30 nets.

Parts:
BATT+1: TestPoint_Pad_D1.5mm
BUTTON1: TestPoint_Pad_D1.5mm
C1, C4: 1u; R_1206_3216Metric
C5, C8: 100n; R_1206_3216Metric
C9: 10u; R_1206_3216Metric
C10: 22u; C_1206_3216Metric
FF_CLK1: TestPoint_Pad_D1.5mm
FF_D1: TestPoint_Pad_D1.5mm
FF_Q1: TestPoint_Pad_D1.5mm
H3, H4, H5, H6: Outer PCB Mount; MountingHole_2.1mm
H7, H8, H9, H10: Stand Mount; MountingHole_2.1mm
I2C_CLK1, I2C_SDA1: TestPoint_Pad_D1.5mm
J1: UART; PinHeader_1x03_P2.54mm_Vertical
J3: Conn_ARM_JTAG_SWD_10; PinHeader_2x05_P1.27mm_Vertical_SMD
JP1, JP3, JP5, JP6: Jumper_2_Bridged; SolderJumper-2_P1.3mm_Bridged2Bar_Pad1.0x1.5mm
POGO1, POGO2, POGO3, POGO5, POGO6, POGO7, POGO8, POGO10, POGO11, POGO12, POGO13, POGO14, POGO15, POGO16, POGO19, POGO21, POGO22: pogo; POGO
Q1: NMOS; SOT-23
R1: 415; R_0603_1608Metric
R2: 187; R_0603_1608Metric
R3: 0.04; R_Shunt_Vishay_WSR2_WSR3_KelvinConnection
R4, R5, R6: 100K; R_0603_1608Metric
R7: 200K; R_0603_1608Metric
R8: 300K; R_0603_1608Metric
R9, R10: 1K; R_0603_1608Metric
U1: SC0915; MODULE_SC0915
U2: MIC29302WU; TO-263-5_TabPin3
U3: INA186A5IDCKR; SOT65P210X110-6N
VCC_SENSE1: TestPoint_Pad_D1.5mm

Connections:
+3.3V: C1.1, C5.1, JP3.1 (A), U1.36 (3V3_OUT)
+3.3VADC: C4.1, C8.1, JP1.1 (A), U1.35 (ADC_VREF)
+5V: C9.1, U1.39 (VSYS), U2.1 (EN), U2.2 (VIN)
/BATT+: BATT+1.1, POGO13.1, POGO19.1, R3.2, U3.4
/BUTTON: BUTTON1.1, POGO7.1, Q1.3 (S), R7.1
/BUTTON_CTRL: R4.1, R9.1, R10.1
/BUTTON_DIVIDED: R7.2, R8.1, U1.7 (GP5)
/CURRENT_SENSE_OUTPUT: JP6.1 (A), U1.31 (GP26)
/FF_CLK: FF_CLK1.1, POGO10.1, U1.26 (GP20)
/FF_D: FF_D1.1, POGO8.1, U1.27 (GP21)
/FF_Q: FF_Q1.1, POGO15.1, U1.29 (GP22)
/I2C_CLK: I2C_CLK1.1, POGO11.1, U1.24 (GP18)
/I2C_DATA: I2C_SDA1.1, POGO12.1, U1.25 (GP19)
/P1.9V: POGO16.1, VCC_SENSE1.1
/SENSE_VCC: R5.2, R6.1
/SWDCLK: J3.4 (SWDCLK/TCK), POGO21.1, U1.5 (GP3)
/SWDIO: J3.2 (SWDIO/TMS), POGO22.1, U1.6 (GP4)
/UART_RX: J1.3, POGO1.1, U1.1 (GP0)
/UART_TX: J1.2, POGO5.1, U1.2 (GP1)
/VTREF: J3.1 (VTref), POGO2.1, U1.22 (GP17)
GND: C9.2, C10.2, J1.1, J3.3 (GND), J3.5 (GND), POGO3.1, POGO6.1, POGO14.1, R2.2, R4.2, R6.2, R8.2, U1.3 (GND), U1.8 (GND), U1.13 (GND), U1.18 (GND), U1.23 (GND), U1.28 (GND), U1.38 (GND), U2.3 (GND)
GNDA: C1.2, C4.2, C5.2, C8.2, U1.33 (AGND), U3.2
unnamed: JP1.2 (B), U3.1
unnamed: JP3.2 (B), U3.3
unnamed: JP5.2 (B), R3.1, U3.5
unnamed: JP6.2 (B), U3.6
unnamed: Q1.2 (G), R10.2
unnamed: R9.2, U1.9 (GP6)
unnamed: R1.2, R2.1, U2.5 (ADJ)
VDD: C10.1, JP5.1 (A), Q1.1 (D), R1.1, U2.4 (VOUT)

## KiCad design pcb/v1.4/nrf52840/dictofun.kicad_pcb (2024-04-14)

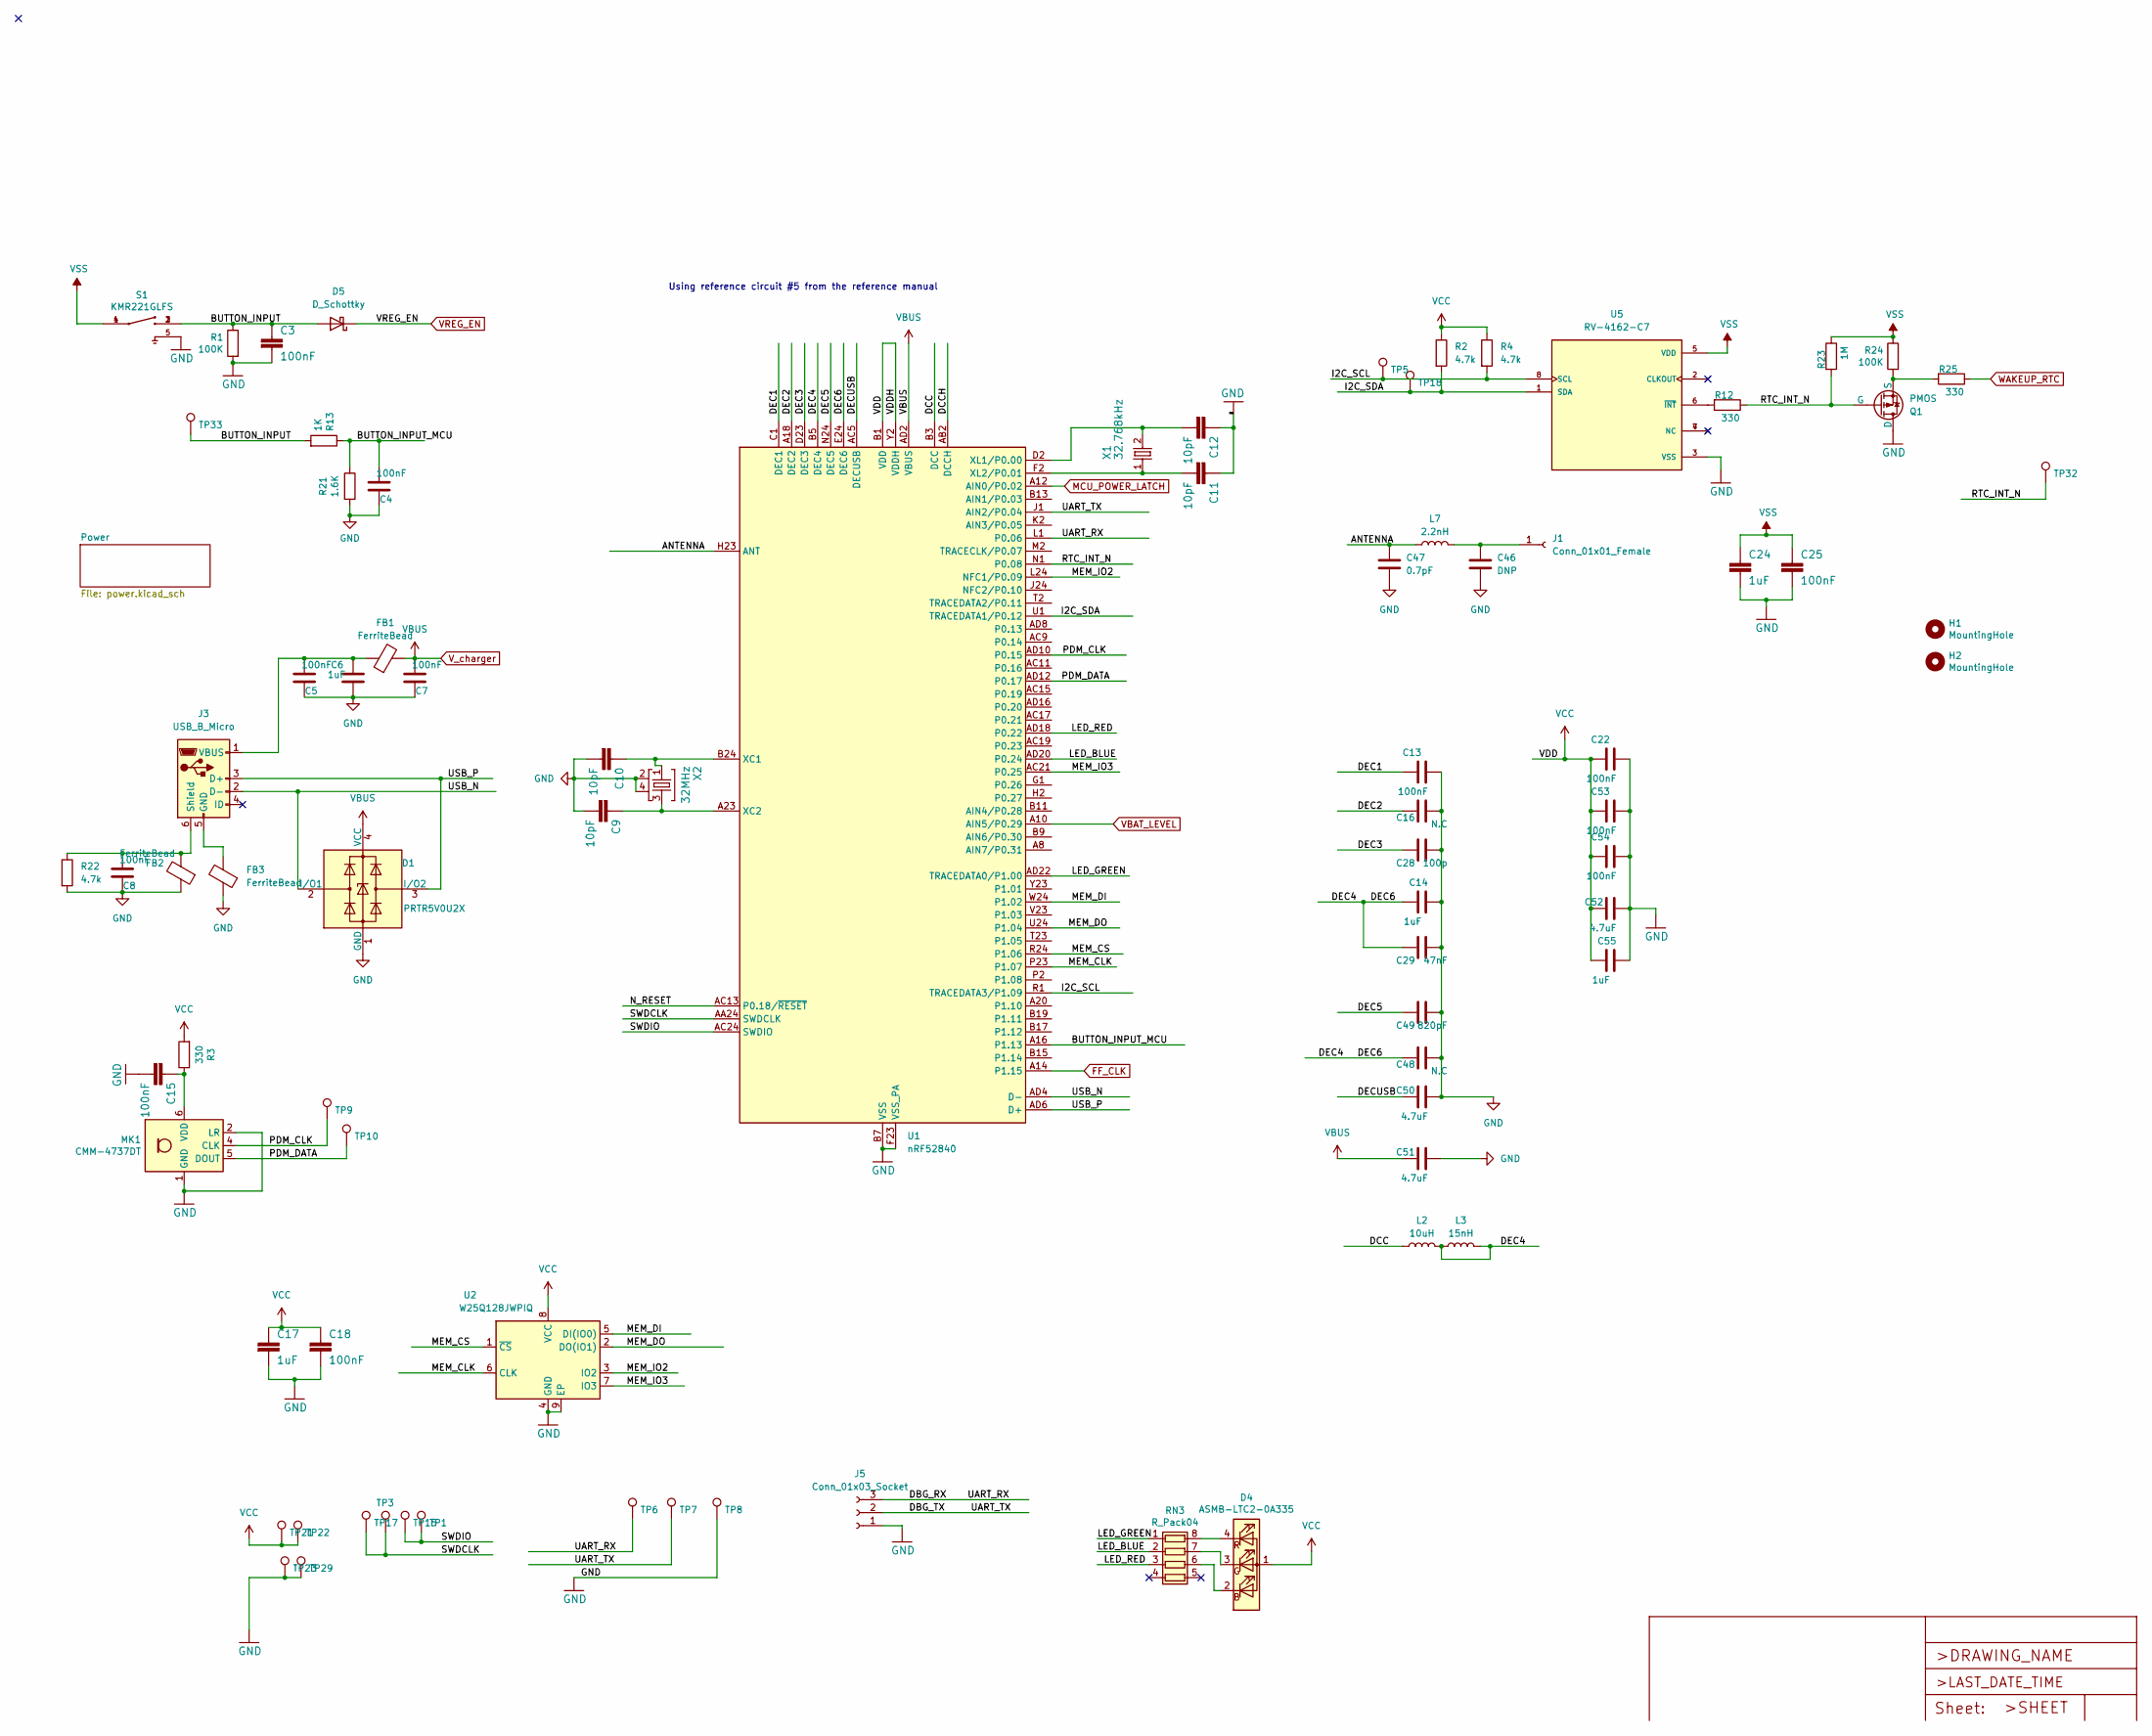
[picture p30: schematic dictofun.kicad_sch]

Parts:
C3, C4, C5, C7, C8, C13, C15, C18, C22, C25, C53, C54: 100nF; C_0402_1005Metric; LCSC C1525
C6, C14, C17, C24, C55: 1uF; C_0402_1005Metric; LCSC C77007
C9, C10, C11, C12: 10pF; C_0402_1005Metric; LCSC C32949
C16, C48: N.C; C_0402_1005Metric
C28: 100p; C_0402_1005Metric; LCSC C445763
C29: 47nF; C_0402_1005Metric; LCSC C338148
C46: DNP; C_0402_1005Metric
C47: 0.7pF; C_0402_1005Metric; LCSC C2194394
C49: 820pF; C_0402_1005Metric; LCSC C161159
C50, C51, C52: 4.7uF; C_0603_1608Metric; LCSC C108342
D1: PRTR5V0U2X; SOT-143; LCSC C2827688
D4: ASMB-LTC2-0A335; LED_Cree-PLCC4_2x2mm_CW
D5: D_Schottky; D_SOD-123F; LCSC C223608
FB1, FB2, FB3: FerriteBead; L_0402_1005Metric; LCSC C19136
H1, H2: MountingHole; MountingHole_1mm
J1: Conn_01x01_Female; PinHeader_1x01_P1.00mm_Vertical
J3: USB_B_Micro; USB_Micro-B_Molex-105017-0001
J5: Conn_01x03_Socket; JST_SM03B-SRSS-TB_LF__SN_
L2: 10uH; L_0402_1005Metric; LCSC C910650
L3: 15nH; L_0402_1005Metric
L7: 2.2nH; L_0402_1005Metric; LCSC C97985
MK1: CMM-4737DT; ST_HLGA-6_3.76x4.72mm_P1.65mm
Q1: PMOS; SOT-23; LCSC C332106
R1, R24: 100K; R_0402_1005Metric; LCSC C25741
R2, R4, R22: 4.7k; R_0402_1005Metric; LCSC C25900
R3, R12, R25: 330; R_0402_1005Metric; LCSC C25104
R13: 1K; R_0402_1005Metric; LCSC C11702
R21: 1.6K; R_0402_1005Metric; LCSC C25867
R23: 1M; R_0402_1005Metric; LCSC C226699
RN3: R_Pack04; R_Array_Convex_4x0402; LCSC C25726
S1: KMR221GLFS; SW_KMR221GLFS; LCSC C72443
TP1, TP3, TP5, TP6, TP7, TP8, TP9, TP10, TP15, TP17, TP18, TP21, TP22, TP23, TP29, TP32, TP33: TestPoint; TestPoint_Pad_D1.0mm
U1: nRF52840; Nordic_AQFN-73-1EP_7x7mm_P0.5mm; LCSC C190794
U2: W25Q128JWPIQ; WSON-8-1EP_6x5mm_P1.27mm_EP3.4x4.3mm; LCSC C2689660
U5: RV-4162-C7; IC_RV-4162-C7; PARTREV 5.1/09.2020
X1: 32.768kHz; Crystal_SMD_MicroCrystal_CM9V-T1A-2Pin_1.6x1.0mm
X2: 32MHz; BT-XTAL_2016_N

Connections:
/ANTENNA: C47.1, L7.1, U1.H23 (ANT)
/BUTTON_INPUT: C3.1, D5.2 (A), R1.1, R13.2, S1.2, S1.3, TP33.1
/BUTTON_INPUT_MCU: C4.1, R13.1, R21.1, U1.A16 (P1.13)
/DBG_RX: J5.3, TP6.1, U1.L1 (P0.06)
/DBG_TX: J5.2, TP7.1, U1.J1 (AIN2/P0.04)
/DCC: L2.1, U1.B3 (DCC)
/DCCH: U1.AB2 (DCCH)
/DEC1: C13.1, U1.C1 (DEC1)
/DEC2: C16.1, U1.A18 (DEC2)
/DEC3: C28.1, U1.D23 (DEC3)
/DEC4: C14.1, C29.1, C48.1, L2.2, L3.1, L3.2, U1.B5 (DEC4), U1.E24 (DEC6)
/DEC5: C49.1, U1.N24 (DEC5)
/DECUSB: C50.1, U1.AC5 (DECUSB)
/I2C_SCL: R4.2, TP5.1, U1.R1 (TRACEDATA3/P1.09), U5.8 (SCL)
/I2C_SDA: R2.2, TP18.1, U1.U1 (TRACEDATA1/P0.12), U5.1 (SDA)
/LED_BLUE: RN3.2 (R2.1), U1.AD20 (P0.24)
/LED_GREEN: RN3.1 (R1.1), U1.AD22 (TRACEDATA0/P1.00)
/LED_RED: RN3.3 (R3.1), U1.AD18 (P0.22)
/MEM_CLK: U1.P23 (P1.07), U2.6 (CLK)
/MEM_CS: U1.R24 (P1.06), U2.1 (~CS)
/MEM_DI: U1.W24 (P1.02), U2.5 (DI(IO0))
/MEM_DO: U1.U24 (P1.04), U2.2 (DO(IO1))
/MEM_IO2: U1.L24 (NFC1/P0.09), U2.3 (IO2)
/MEM_IO3: U1.AC21 (P0.25), U2.7 (IO3)
/N_RESET: U1.AC13 (P0.18/~RESET)
/PDM_CLK: MK1.4 (CLK), TP9.1, U1.AD10 (P0.15)
/PDM_DATA: MK1.5 (DOUT), TP10.1, U1.AD12 (P0.17)
/RTC_INT_N: Q1.2 (G), R12.1, R23.2, TP32.1, U1.N1 (P0.08)
/SWDCLK: TP3.1, TP17.1, U1.AA24 (SWDCLK)
/SWDIO: TP1.1, TP15.1, U1.AC24 (SWDIO)
/USB_N: D1.2 (I/O1), J3.2 (D-), U1.AD4 (D-)
/USB_P: D1.3 (I/O2), J3.3 (D+), U1.AD6 (D+)
FF_CLK: U1.A14 (P1.15); also elsewhere on the board
GND: C3.2, C4.2, C5.2, C6.2, C7.2, C8.2, C9.2, C10.2, C11.1, C12.1, C13.2, C14.2, C15.2, C16.2, C17.2, C18.2, C22.2, C24.2, C25.2, C28.2, C29.2, C46.2, C47.2, C48.2, C49.2, C50.2, C51.2, C52.2, C53.2, C54.2, C55.2, D1.1 (GND), FB2.1, FB3.1, J5.1, MK1.1 (GND), MK1.2 (LR), MK1.3 (GND), Q1.1 (D), R1.2, R21.2, R22.2, S1.5, TP8.1, TP23.1, TP29.1, U1.B7 (VSS), U1.EP (VSS), U1.F23 (VSS_PA), U2.4 (GND), U2.9 (EP), U5.3 (VSS), X2.2, X2.4; also elsewhere on the board
MCU_POWER_LATCH: U1.A12 (AIN0/P0.02); also elsewhere on the board
unnamed: D4.2 (BK), RN3.6 (R3.2)
unnamed: D4.3 (GK), RN3.7 (R2.2)
unnamed: D4.4 (RK), RN3.8 (R1.2)
unnamed: C46.1, J1.1, L7.2
unnamed: FB3.2, J3.5 (GND)
unnamed: C8.1, FB2.2, J3.6 (Shield), R22.1
unnamed: C5.1, C6.1, FB1.1, J3.1 (VBUS)
unnamed: C15.1, MK1.6 (VDD), R3.1
unnamed: Q1.3 (S), R24.2, R25.2
unnamed: C10.1, U1.B24 (XC1), X2.1
unnamed: C9.1, U1.A23 (XC2), X2.3
unnamed: C12.2, U1.D2 (XL1/P0.00), X1.2
unnamed: C11.2, U1.F2 (XL2/P0.01), X1.1
unnamed: R12.2, U5.6 (~INT)
VBAT_LEVEL: U1.A10 (AIN5/P0.29); also elsewhere on the board
VCC: C17.1, C18.1, C22.1, C52.1, C53.1, C54.1, C55.1, D4.1 (A), R2.1, R3.2, R4.1, TP21.1, TP22.1, U1.A22 (VDD), U1.AD14 (VDD), U1.AD23 (VDD), U1.B1 (VDD), U1.W1 (VDD), U1.Y2 (VDDH), U2.8 (VCC); also elsewhere on the board
VREG_EN: D5.1 (K), R25.1; also elsewhere on the board
VSS: C24.1, C25.1, R23.1, R24.1, S1.1, S1.4, U5.5 (VDD); also elsewhere on the board
V_charger: C7.1, C51.1, D1.4 (VCC), FB1.2, U1.AD2 (VBUS); also elsewhere on the board

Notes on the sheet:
Using reference circuit #5 from the reference manual

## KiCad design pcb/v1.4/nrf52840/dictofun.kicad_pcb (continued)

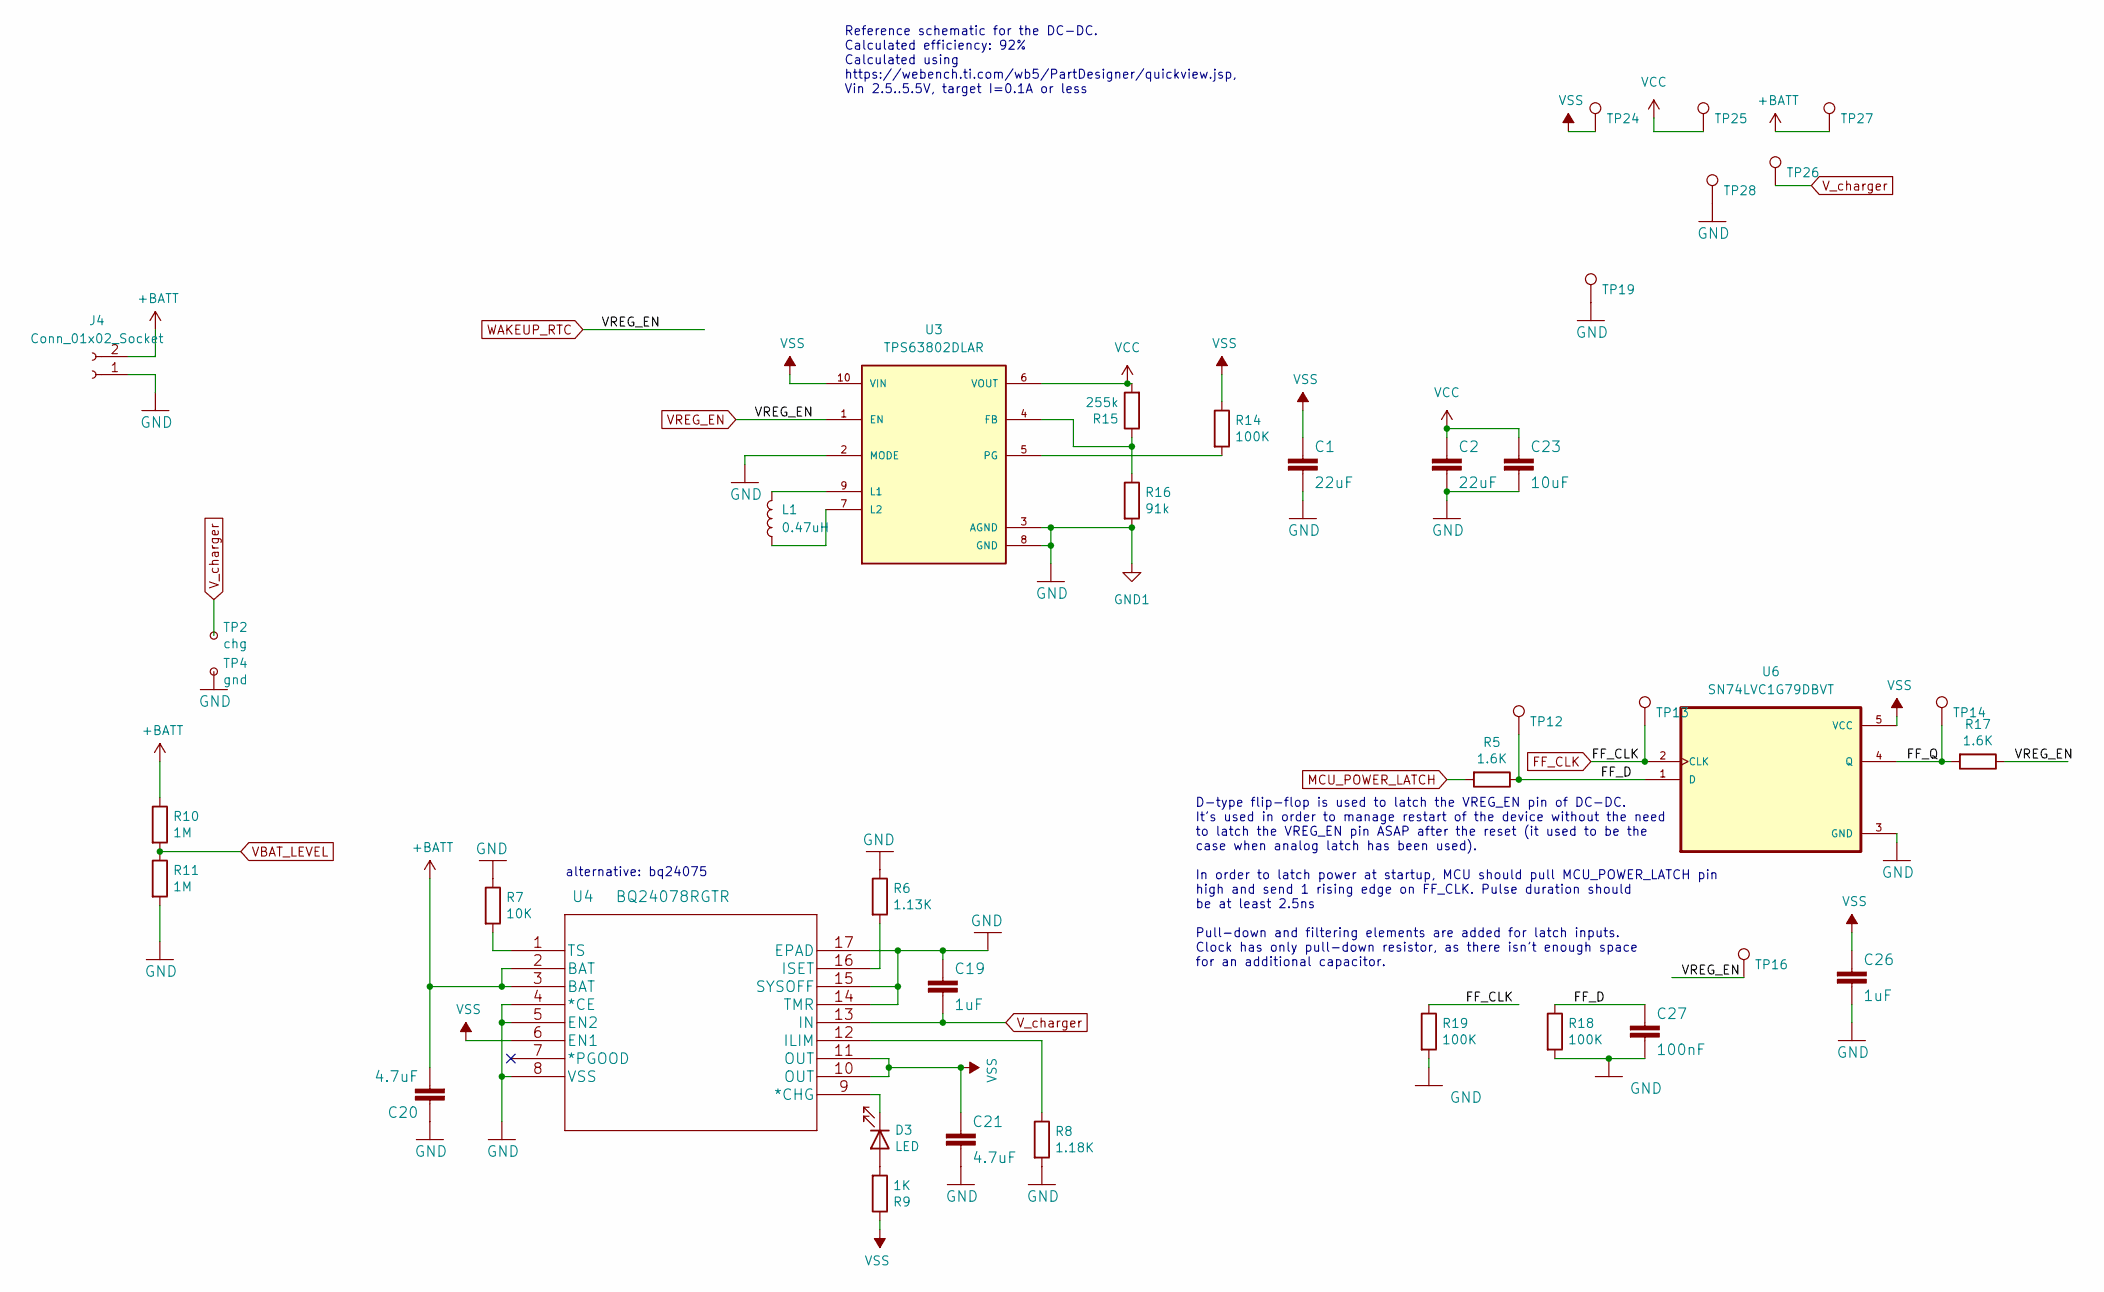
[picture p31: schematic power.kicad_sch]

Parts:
C1, C2: 22uF; C_0603_1608Metric; LCSC C109447
C19, C26: 1uF; C_0402_1005Metric; LCSC C77007
C20, C21: 4.7uF; C_0402_1005Metric; LCSC C23733
C23: 10uF; C_0402_1005Metric; LCSC C15525
C27: 100nF; C_0402_1005Metric; LCSC C1525
D3: LED; LED_0603_1608Metric; LCSC C131282
J4: Conn_01x02_Socket; SM02B-SRSS-TB_LF__SN_
L1: 0.47uH; L_1008_2520Metric; PartN LQM2HPNR47MG0L; LCSC C1333867
R5, R17: 1.6K; R_0402_1005Metric; LCSC C25867
R6: 1.13K; R_0402_1005Metric; LCSC C67014
R7: 10K; R_0402_1005Metric; LCSC C25744
R8: 1.18K; R_0402_1005Metric; LCSC C270651
R9: 1K; R_0402_1005Metric; LCSC C11702
R10, R11: 1M; R_0402_1005Metric; LCSC C226699
R14, R18, R19: 100K; R_0402_1005Metric; LCSC C25741
R15: 255k; R_0603_1608Metric; LCSC C728604
R16: 91k; R_0603_1608Metric; LCSC C227535
TP2: chg; TestPoint_Pad_D1.0mm
TP4: gnd; TestPoint_Pad_D1.0mm
TP12, TP13, TP14, TP16, TP19, TP24, TP25, TP26, TP27, TP28: TestPoint; TestPoint_Pad_D1.0mm
U3: TPS63802DLAR; VREG_TPS63802DLAR; PARTREV B; LCSC C2845237
U4: BQ24078RGTR; VQFN-16-1EP_3x3mm_P0.5mm_EP1.45x1.45mm_ThermalVias; LCSC C15464
U6: SN74LVC1G79DBVT; SOT-23-5; LCSC C42878

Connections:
+BATT: C20.2, J4.2, R10.1, TP27.1, U4.2 (BAT), U4.3 (BAT)
/Power/FF_D: C27.1, R5.1, R18.1, TP12.1, U6.1 (D)
/Power/FF_Q: R17.2, TP14.1, U6.4 (Q)
FF_CLK: R19.1, TP13.1, U6.2 (CLK); also elsewhere on the board
GND: C1.2, C2.2, C19.1, C20.1, C21.2, C23.2, C26.2, C27.2, J4.1, R6.1, R7.1, R8.2, R11.2, R16.2, R18.2, R19.2, TP4.1, TP19.1, TP28.1, U3.2 (MODE), U3.3 (AGND), U3.8 (GND), U4.4 (*CE), U4.5 (EN2), U4.8 (VSS), U4.14 (TMR), U4.15 (SYSOFF), U4.17 (EPAD), U6.3 (GND); also elsewhere on the board
MCU_POWER_LATCH: R5.2; also elsewhere on the board
unnamed: D3.2 (A), R9.2
unnamed: D3.1 (K), U4.9 (*CHG)
unnamed: R15.1, R16.1, U3.4 (FB)
unnamed: L1.2, U3.9 (L1)
unnamed: L1.1, U3.7 (L2)
unnamed: R14.2, U3.5 (PG)
unnamed: R8.1, U4.12 (ILIM)
unnamed: R6.2, U4.16 (ISET)
unnamed: R7.2, U4.1 (TS)
VBAT_LEVEL: R10.2, R11.1; also elsewhere on the board
VCC: C2.1, C23.1, R15.2, TP25.1, U3.6 (VOUT); also elsewhere on the board
VREG_EN: R17.1, TP16.1, U3.1 (EN); also elsewhere on the board
VSS: C1.1, C21.1, C26.1, R9.1, R14.1, TP24.1, U3.10 (VIN), U4.6 (EN1), U4.10 (OUT), U4.11 (OUT), U6.5 (VCC); also elsewhere on the board
V_charger: C19.2, TP2.1, TP26.1, U4.13 (IN); also elsewhere on the board

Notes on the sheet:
alternative: bq24075
D-type flip-flop is used to latch the VREG_EN pin of DC-DC. It's used in order to manage restart of the device without the need to latch the VREG_EN pin ASAP after the reset (it used to be the case when analog latch has been used). In order to latch power at startup, MCU should pull MCU_POWER_LATCH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
Reference schematic for the DC-DC. Calculated efficiency: 92% Calculated using https://webench.ti.com/wb5/PartDesigner/quickview.jsp, Vin 2.5..5.5V, target I=0.1A or less

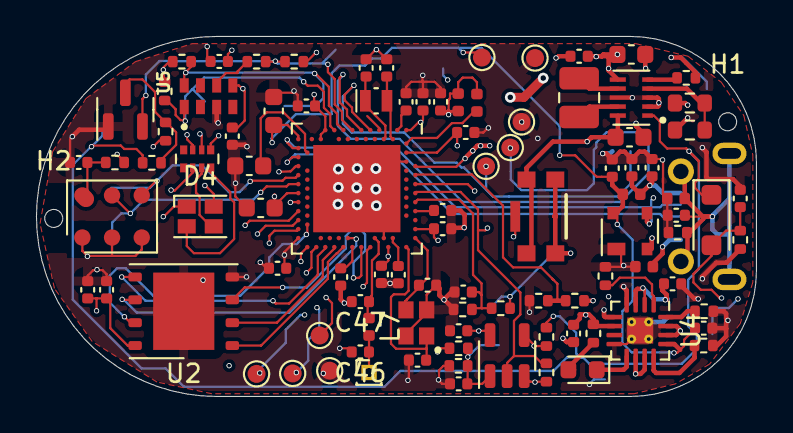
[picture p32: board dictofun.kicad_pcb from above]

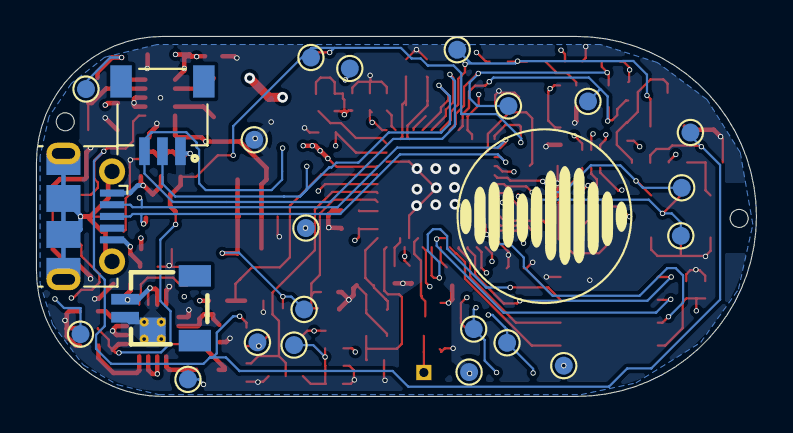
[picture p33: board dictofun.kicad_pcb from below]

Board: 4 copper layers, 40.0 x 20.0 mm, 121 parts (23 on the bottom side), 64 nets.

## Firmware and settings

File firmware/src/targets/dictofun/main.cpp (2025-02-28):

// SPDX-License-Identifier:  Apache-2.0
/*
 * Copyright (c) 2022, Roman Turkin
 */

#include "app_error.h"

#include "nrf_drv_clock.h"
#include "nrf_log.h"
#include "nrf_log_ctrl.h"
#include <boards.h>
#include <nrf_gpio.h>

#include "FreeRTOS.h"
#include "queue.h"
#include "task.h"
#include "timers.h"

// TODO: this dependency here is really bad
#include "codec_decimate.h"
#include "microphone_pdm.h"

#include "task_audio.h"
#include "task_audio_tester.h"
#include "task_battery.h"
#include "task_ble.h"
#include "task_button.h"
#include "task_cli_logger.h"
#include "task_led.h"
#include "task_memory.h"
#include "task_rtc.h"
#include "task_state.h"
#include "task_wdt.h"

#include <stdint.h>

#include "freertos_wrappers.hpp"

// clang-format off
// ============================= Tasks ======================================

application::TaskDescriptor<256,  3> audio_task;
application::TaskDescriptor<256,  1> audio_tester_task;
application::TaskDescriptor<330,  2> log_task;
application::TaskDescriptor<256,  3> systemstate_task;
application::TaskDescriptor<1500, 2> memory_task;
application::TaskDescriptor<1250, 2> ble_task;
application::TaskDescriptor<96,   1>  led_task;
application::TaskDescriptor<128,  2>  rtc_task;
application::TaskDescriptor<96,   3>  button_task;
application::TaskDescriptor<256,  2>  battery_task;
application::TaskDescriptor<96,   1>  wdt_task;

// ============================= Queues =====================================

application::QueueDescriptor<logger::CliCommandQueueElement, 1>      cli_commands_queue;
application::QueueDescriptor<logger::CliStatusQueueElement, 1>       cli_status_queue; // This thing is under a big doubt, I don't think it's needed
application::QueueDescriptor<audio::CommandQueueElement, 1>          audio_commands_queue;
application::QueueDescriptor<audio::StatusQueueElement, 1>           audio_status_queue;
application::QueueDescriptor<audio::tester::ControlQueueElement, 1>  audio_tester_commands_queue;

application::QueueDescriptor<audio::CodecOutputType, 4>              audio_data_queue;

application::QueueDescriptor<memory::CommandQueueElement, 1>         memory_commands_queue;
application::QueueDescriptor<memory::StatusQueueElement, 1>          memory_status_queue; 
application::QueueDescriptor<memory::EventQueueElement, 1>           memory_event_queue; 

application::QueueDescriptor<ble::CommandQueueElement, 2>            ble_commands_queue;
application::QueueDescriptor<ble::RequestQueueElement, 1>            ble_requests_queue;
application::QueueDescriptor<ble::KeepaliveQueueElement, 1>          ble_keepalive_queue;
application::QueueDescriptor<ble::BatteryDataElement, 1>             ble_batt_info_queue;

application::QueueDescriptor<ble::CommandToMemoryQueueElement, 1>    ble_to_mem_commands_queue;
application::QueueDescriptor<ble::StatusFromMemoryQueueElement, 1>   ble_from_mem_status_queue;
application::QueueDescriptor<ble::FileDataFromMemoryQueueElement, 1> ble_from_mem_data_queue;

application::QueueDescriptor<led::CommandQueueElement, 3>            led_commands_queue;

application::QueueDescriptor<rtc::CommandQueueElement, 1>            rtc_commands_queue;
application::QueueDescriptor<rtc::ResponseQueueElement, 1>           rtc_response_queue;

application::QueueDescriptor<button::EventQueueElement, 1>           button_event_queue;
application::QueueDescriptor<button::RequestQueueElement, 1>         button_requests_queue;
application::QueueDescriptor<button::ResponseQueueElement, 1>        button_response_queue;

application::QueueDescriptor<battery::MeasurementsQueueElement, 1>   battery_measurements_queue;

// ============================= Timers =====================================

StaticTimer_t record_timer_buffer;
TimerHandle_t record_timer_handle{nullptr};

// ============================ Contexts ====================================
logger::CliContext      cli_context;
systemstate::Context    systemstate_context;
audio::Context          audio_context;
audio::tester::Context  audio_tester_context;
memory::Context         memory_context;
ble::Context            ble_context;
led::Context            led_context;
rtc::Context            rtc_context;
button::Context         button_context;
battery::Context        battery_context;

// clang-format on

void latch_ldo_enable()
{
    nrf_gpio_cfg_output(LDO_LATCH_D_PIN);
    nrf_gpio_cfg_output(LDO_LATCH_CLK_PIN);
    nrf_gpio_cfg_input(BUTTON_PIN, NRF_GPIO_PIN_PULLDOWN);
    nrf_gpio_pin_set(LDO_LATCH_D_PIN);

    nrf_gpio_cfg(LDO_LATCH_D_PIN,
                 NRF_GPIO_PIN_DIR_OUTPUT,
                 NRF_GPIO_PIN_INPUT_DISCONNECT,
                 NRF_GPIO_PIN_PULLDOWN,
                 NRF_GPIO_PIN_H0S1,
                 NRF_GPIO_PIN_NOSENSE);

    nrf_gpio_pin_set(LDO_LATCH_CLK_PIN);
    for (volatile int i = 0; i < 100000; ++i);
    nrf_gpio_pin_clear(LDO_LATCH_CLK_PIN);
    for (volatile int i = 0; i < 100000; ++i);
    nrf_gpio_pin_set(LDO_LATCH_CLK_PIN);
}

int main()
{
    latch_ldo_enable();

    const auto err_code = nrf_drv_clock_init();
    APP_ERROR_CHECK(err_code);
    nrf_drv_clock_lfclk_request(NULL);

    logger::log_init();

    bsp_board_init(BSP_INIT_LEDS);

    // Queues' initialization
    const auto cli_commands_init_result = cli_commands_queue.init();
    if(result::Result::OK != cli_commands_init_result)
    {
        APP_ERROR_HANDLER(NRF_ERROR_NO_MEM);
    }

    const auto cli_status_init_result = cli_status_queue.init();
    if(result::Result::OK != cli_status_init_result)
    {
        APP_ERROR_HANDLER(NRF_ERROR_NO_MEM);
    }

    const auto audio_commands_init_result = audio_commands_queue.init();
    if(result::Result::OK != audio_commands_init_result)
    {
        APP_ERROR_HANDLER(NRF_ERROR_NO_MEM);
    }

    const auto audio_data_init_result = audio_data_queue.init();
    if(result::Result::OK != audio_data_init_result)
    {
        APP_ERROR_HANDLER(NRF_ERROR_NO_MEM);
    }

    const auto audio_status_init_result = audio_status_queue.init();
    if(result::Result::OK != audio_status_init_result)
    {
        APP_ERROR_HANDLER(NRF_ERROR_NO_MEM);
    }

    const auto audio_tester_command_init_result = audio_tester_commands_queue.init();
    if(result::Result::OK != audio_tester_command_init_result)
    {
        APP_ERROR_HANDLER(NRF_ERROR_NO_MEM);
    }

    const auto memory_commands_queue_init_result = memory_commands_queue.init();
    if(result::Result::OK != memory_commands_queue_init_result)
    {
        APP_ERROR_HANDLER(NRF_ERROR_NO_MEM);
    }

    const auto memory_status_queue_init_result = memory_status_queue.init();
    if(result::Result::OK != memory_status_queue_init_result)
    {
        APP_ERROR_HANDLER(NRF_ERROR_NO_MEM);
    }

    const auto memory_event_queue_init_result = memory_event_queue.init();
    if(result::Result::OK != memory_event_queue_init_result)
    {
        APP_ERROR_HANDLER(NRF_ERROR_NO_MEM);
    }

    const auto ble_commands_queue_init_result = ble_commands_queue.init();
    if(result::Result::OK != ble_commands_queue_init_result)
    {
        APP_ERROR_HANDLER(NRF_ERROR_NO_MEM);
    }

    const auto ble_requests_queue_init_result = ble_requests_queue.init();
    if(result::Result::OK != ble_requests_queue_init_result)
    {
        APP_ERROR_HANDLER(NRF_ERROR_NO_MEM);
    }

    const auto ble_keepalive_queue_init_result = ble_keepalive_queue.init();
    if(result::Result::OK != ble_keepalive_queue_init_result)
    {
        APP_ERROR_HANDLER(NRF_ERROR_NO_MEM);
    }

    const auto ble_batt_info_queue_init_result = ble_batt_info_queue.init();
    if(result::Result::OK != ble_batt_info_queue_init_result)
    {
        APP_ERROR_HANDLER(NRF_ERROR_NO_MEM);
    }

    const auto ble_to_mem_commands_queue_init_result = ble_to_mem_commands_queue.init();
    if(result::Result::OK != ble_to_mem_commands_queue_init_result)
    {
        APP_ERROR_HANDLER(NRF_ERROR_NO_MEM);
    }

    const auto ble_from_mem_status_queue_init_result = ble_from_mem_status_queue.init();
    if(result::Result::OK != ble_from_mem_status_queue_init_result)
    {
        APP_ERROR_HANDLER(NRF_ERROR_NO_MEM);
    }

    const auto ble_from_mem_data_queue_init_result = ble_from_mem_data_queue.init();
    if(result::Result::OK != ble_from_mem_data_queue_init_result)
    {
        APP_ERROR_HANDLER(NRF_ERROR_NO_MEM);
    }

    const auto led_commands_queue_init_result = led_commands_queue.init();
    if(result::Result::OK != led_commands_queue_init_result)
    {
        APP_ERROR_HANDLER(NRF_ERROR_NO_MEM);
    }

    const auto rtc_commands_queue_init_result = rtc_commands_queue.init();
    if(result::Result::OK != rtc_commands_queue_init_result)
    {
        APP_ERROR_HANDLER(NRF_ERROR_NO_MEM);
    }

    const auto rtc_response_queue_init_result = rtc_response_queue.init();
    if(result::Result::OK != rtc_response_queue_init_result)
    {
        APP_ERROR_HANDLER(NRF_ERROR_NO_MEM);
    }

    const auto button_event_queue_init_result = button_event_queue.init();
    if(result::Result::OK != button_event_queue_init_result)
    {
        APP_ERROR_HANDLER(NRF_ERROR_NO_MEM);
    }

    const auto button_requests_queue_init_result = button_requests_queue.init();
    if(result::Result::OK != button_requests_queue_init_result)
    {
        APP_ERROR_HANDLER(NRF_ERROR_NO_MEM);
    }

    const auto button_response_queue_init_result = button_response_queue.init();
    if(result::Result::OK != button_response_queue_init_result)
    {
        APP_ERROR_HANDLER(NRF_ERROR_NO_MEM);
    }

    const auto battery_measurements_queue_init_result = battery_measurements_queue.init();
    if(result::Result::OK != battery_measurements_queue_init_result)
    {
        APP_ERROR_HANDLER(NRF_ERROR_NO_MEM);
    }

    // // Timers' initialization
    record_timer_handle = xTimerCreateStatic(
        "AUDIO", 1, pdFALSE, nullptr, systemstate::record_end_callback, &record_timer_buffer);
    if(nullptr == record_timer_handle)
    {
        APP_ERROR_HANDLER(NRF_ERROR_NO_MEM);
    }

    // Tasks' initialization
    audio_context.commands_queue = audio_commands_queue.handle;
    audio_context.status_queue = audio_status_queue.handle;
    audio_context.data_queue = audio_data_queue.handle;

    const auto audio_task_init_result = audio_task.init(audio::task_audio, "AUDIO", &audio_context);
    if(result::Result::OK != audio_task_init_result)
    {
        APP_ERROR_HANDLER(NRF_ERROR_NO_MEM);
    }

    audio_tester_context.data_queue = audio_data_queue.handle;
    audio_tester_context.commands_queue = audio_tester_commands_queue.handle;

    const auto audio_tester_task_init_result =
        audio_tester_task.init(audio::tester::task_audio_tester, "AUTEST", &audio_tester_context);
    if(result::Result::OK != audio_tester_task_init_result)
    {
        APP_ERROR_HANDLER(NRF_ERROR_NO_MEM);
    }

    cli_context.cli_commands_handle = cli_commands_queue.handle;
    cli_context.cli_status_handle = cli_status_queue.handle;

    const auto log_task_init_result = log_task.init(logger::task_cli_logger, "CLI", &cli_context);
    if(result::Result::OK != log_task_init_result)
    {
        APP_ERROR_HANDLER(NRF_ERROR_NO_MEM);
    }

    systemstate_context.cli_commands_handle = cli_commands_queue.handle;
    systemstate_context.cli_status_handle = cli_status_queue.handle;
    systemstate_context.audio_commands_handle = audio_commands_queue.handle;
    systemstate_context.audio_status_handle = audio_status_queue.handle;
    systemstate_context.record_timer_handle = record_timer_handle;
    systemstate_context.audio_tester_commands_handle = audio_tester_commands_queue.handle;
    systemstate_context.memory_commands_handle = memory_commands_queue.handle;
    systemstate_context.memory_status_handle = memory_status_queue.handle;
    systemstate_context.memory_event_handle = memory_event_queue.handle;
    systemstate_context.ble_commands_handle = ble_commands_queue.handle;
    systemstate_context.ble_requests_handle = ble_requests_queue.handle;
    systemstate_context.ble_keepalive_handle = ble_keepalive_queue.handle;
    systemstate_context.led_commands_handle = led_commands_queue.handle;
    systemstate_context.button_events_handle = button_event_queue.handle;
    systemstate_context.button_requests_handle = button_requests_queue.handle;
    systemstate_context.button_response_handle = button_response_queue.handle;
    systemstate_context.battery_measurements_handle = battery_measurements_queue.handle;
    systemstate_context.battery_level_to_ble_handle = ble_batt_info_queue.handle;

    const auto systemstate_task_init_result =
        systemstate_task.init(systemstate::task_system_state, "STATE", &systemstate_context);
    if(result::Result::OK != systemstate_task_init_result)
    {
        APP_ERROR_HANDLER(NRF_ERROR_NO_MEM);
    }

    memory_context.command_queue = memory_commands_queue.handle;
    memory_context.status_queue = memory_status_queue.handle;
    memory_context.event_queue = memory_event_queue.handle;
    memory_context.command_from_ble_queue = ble_to_mem_commands_queue.handle;
    memory_context.status_to_ble_queue = ble_from_mem_status_queue.handle;
    memory_context.data_to_ble_queue = ble_from_mem_data_queue.handle;
    memory_context.audio_data_queue = audio_data_queue.handle;
    memory_context.commands_to_rtc_queue = rtc_commands_queue.handle;
    memory_context.response_from_rtc_queue = rtc_response_queue.handle;
    const auto memory_task_init_result =
        memory_task.init(memory::task_memory, "MEM", &memory_context);

    if(result::Result::OK != memory_task_init_result)
    {
        APP_ERROR_HANDLER(NRF_ERROR_NO_MEM);
    }

    ble_context.command_queue = ble_commands_queue.handle;
    ble_context.requests_queue = ble_requests_queue.handle;
    ble_context.keepalive_queue = ble_keepalive_queue.handle;
    ble_context.command_to_mem_queue = ble_to_mem_commands_queue.handle;
    ble_context.status_from_mem_queue = ble_from_mem_status_queue.handle;
    ble_context.data_from_mem_queue = ble_from_mem_data_queue.handle;
    ble_context.commands_to_rtc_queue = rtc_commands_queue.handle;
    ble_context.battery_to_ble_queue = ble_batt_info_queue.handle;
    ble_context.ble_to_led_queue = led_commands_queue.handle;
    const auto ble_task_init_result = ble_task.init(ble::task_ble, "BLE", &ble_context);

    if(result::Result::OK != ble_task_init_result)
    {
        APP_ERROR_HANDLER(NRF_ERROR_NO_MEM);
    }

    led_context.commands_queue = led_commands_queue.handle;
    const auto led_task_init_result = led_task.init(led::task_led, "LED", &led_context);

    if(result::Result::OK != led_task_init_result)
    {
        APP_ERROR_HANDLER(NRF_ERROR_NO_MEM);
    }

    rtc_context.command_queue = rtc_commands_queue.handle;
    rtc_context.response_queue = rtc_response_queue.handle;
    const auto rtc_task_init_result = rtc_task.init(rtc::task_rtc, "RTC", &rtc_context);

    if(result::Result::OK != rtc_task_init_result)
    {
        APP_ERROR_HANDLER(NRF_ERROR_NO_MEM);
    }

    button_context.events_handle = button_event_queue.handle;
    button_context.response_handle = button_response_queue.handle;
    button_context.commands_handle = button_requests_queue.handle;
    const auto button_task_init_result =
        button_task.init(button::task_button, "BTN", &button_context);

    if(result::Result::OK != button_task_init_result)
    {
        APP_ERROR_HANDLER(NRF_ERROR_NO_MEM);
    }

    battery_context.measurements_handle = battery_measurements_queue.handle;
    const auto battery_task_init_result =
        battery_task.init(battery::task_battery, "BAT", &battery_context);

    if(result::Result::OK != battery_task_init_result)
    {
        APP_ERROR_HANDLER(NRF_ERROR_NO_MEM);
    }

    const auto wdt_task_init_result = wdt_task.init(wdt::task_wdt, "WDT", nullptr);
    if (result::Result::OK != wdt_task_init_result)
    {
        APP_ERROR_HANDLER(NRF_ERROR_NO_MEM);
    }

    vTaskStartScheduler();
}

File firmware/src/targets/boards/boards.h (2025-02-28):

#ifndef BOARDS_H
#define BOARDS_H

#include "nrf_gpio.h"
#include "nordic_common.h"

#if defined(BOARD_NRF6310)
#elif defined(BOARD_PCA10056)
  #include "pca10056.h"
#elif defined(BOARD_CUSTOM)
  #include "custom_board.h"
#elif defined(BOARD_DICTOFUN_1_1)
  #include "dictofun_1_1.h"
#elif defined(BOARD_DICTOFUN_1_3)
  #include "dictofun_1_3.h"
#elif defined(BOARD_DICTOFUN_1_4)
  #include "dictofun_1_4.h"
#else
#error "Board is not defined"
#endif

#if defined (SHIELD_BSP_INC)
  #include STRINGIFY(SHIELD_BSP_INC.h)
#endif

#ifdef __cplusplus
extern "C" {
#endif

/**@defgroup BSP_BOARD_INIT_FLAGS Board initialization flags.
 * @{ */
#define BSP_INIT_NONE    0        /**< No initialization of LEDs or buttons (@ref bsp_board_init).*/
#define BSP_INIT_LEDS    (1 << 0) /**< Enable LEDs during initialization (@ref bsp_board_init).*/
#define BSP_INIT_BUTTONS (1 << 1) /**< Enable buttons during initialization (@ref bsp_board_init).*/
/**@} */

/**
 * Function for returning the state of an LED.
 *
 * @param led_idx LED index (starting from 0), as defined in the board-specific header.
 *
 * @return True if the LED is turned on.
 */
bool bsp_board_led_state_get(uint32_t led_idx);

/**
 * Function for turning on an LED.
 *
 * @param led_idx LED index (starting from 0), as defined in the board-specific header.
 */
void bsp_board_led_on(uint32_t led_idx);

/**
 * Function for turning off an LED.
 *
 * @param led_idx LED index (starting from 0), as defined in the board-specific header.
 */
void bsp_board_led_off(uint32_t led_idx);

/**
 * Function for inverting the state of an LED.
 *
 * @param led_idx LED index (starting from 0), as defined in the board-specific header.
 */
void bsp_board_led_invert(uint32_t led_idx);
/**
 * Function for turning off all LEDs.
 */
void bsp_board_leds_off(void);

/**
 * Function for turning on all LEDs.
 */
void bsp_board_leds_on(void);

/**
 * Function for initializing the BSP handling for the board.
 *
 * @note This also initializes the USB DFU trigger library if @ref BOARDS_WITH_USB_DFU_TRIGGER is 1.
 *
 * @param[in]  init_flags  Flags specifying what to initialize (LEDs/buttons).
 *                         See @ref BSP_BOARD_INIT_FLAGS.
 */
void bsp_board_init(uint32_t init_flags);

/**
 * Function for converting pin number to LED index.
 *
 * @param pin_number Pin number.
 *
 * @return LED index of the given pin or 0xFFFFFFFF if invalid pin provided.
 */
uint32_t bsp_board_pin_to_led_idx(uint32_t pin_number);

/**
 * Function for converting LED index to pin number.
 *
 * @param led_idx LED index.
 *
 * @return Pin number.
 */
uint32_t bsp_board_led_idx_to_pin(uint32_t led_idx);

/**
 * Function for returning the state of a button.
 *
 * @param button_idx Button index (starting from 0), as defined in the board-specific header.
 *
 * @return True if the button is pressed.
 */
bool bsp_board_button_state_get(uint32_t button_idx);

/**
 * Function for converting pin number to button index.
 *
 * @param pin_number Pin number.
 *
 * @return Button index of the given pin or 0xFFFFFFFF if invalid pin provided.
 */
uint32_t bsp_board_pin_to_button_idx(uint32_t pin_number);


/**
 * Function for converting button index to pin number.
 *
 * @param button_idx Button index.
 *
 * @return Pin number.
 */
uint32_t bsp_board_button_idx_to_pin(uint32_t button_idx);

#define BSP_BOARD_LED_0 0
#define BSP_BOARD_LED_1 1
#define BSP_BOARD_LED_2 2
#define BSP_BOARD_LED_3 3
#define BSP_BOARD_LED_4 4
#define BSP_BOARD_LED_5 5
#define BSP_BOARD_LED_6 6
#define BSP_BOARD_LED_7 7

#define PIN_MASK(_pin)  /*lint -save -e504 */                     \
                        (1u << (uint32_t)((_pin) & (~P0_PIN_NUM))) \
                        /*lint -restore    */

#define PIN_PORT(_pin) (((_pin) >= P0_PIN_NUM) ? NRF_P1 : NRF_GPIO)
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

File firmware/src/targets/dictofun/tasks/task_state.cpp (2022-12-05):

// SPDX-License-Identifier:  Apache-2.0
/*
 * Copyright (c) 2022, Roman Turkin
 */

#include "task_state.h"
#include "BleSystem.h"
#include "block_device_api.h"
#include "spi_flash.h"
#include "task_audio.h"
#include "task_led.h"
#include "task_memory.h"
#include <app_timer.h>
#include <nrf_gpio.h>
#include <nrf_log.h>
#include "battery_measurement.h"

namespace application
{
AppSmState _applicationState{AppSmState::INIT};
filesystem::File _currentFile;
static const int SHUTDOWN_COUNTER_INIT_VALUE = 100;

battery::BatteryMeasurement _batteryMeasurement(2U);

const char* stateNames[] = {"INIT",
                            "PREPARE",
                            "RECORD_START",
                            "RECORD",
                            "RECORD_FINALIZATION",
                            "CONNECT",
                            "TRANSFER",
                            "DISCONNECT",
                            "FINALIZE",
                            "SHUTDOWN",
                            "RESTART"};

AppSmState getApplicationState()
{
    return _applicationState;
}

bool isRecordButtonPressed()
{
    return nrf_gpio_pin_read(BUTTON_PIN) > 0;
}

void application_init() { }

/**
 * Enum is defined within CPP file, as it's used only inside the implementation
 */
enum class CompletionStatus
{
    INVALID,
    PENDING,
    DONE,
    TIMEOUT,
    RESTART_DETECTED,
    ERROR
};

enum class InternalFsmState
{
    INIT,
    RUNNING,
    DONE
};

struct FsmContext
{
    InternalFsmState state;
    bool is_unrecoverable_error_detected;
    int counter;
    uint32_t start_timestamp;
    uint32_t last_file_transmission_report_timestamp;
};

// connection timeout in milliseconds (60 seconds)
static const uint32_t CONNECT_STATE_TIMEOUT = 30000;

// transfer timeout in milliseconds (1200 seconds)
static const uint32_t TRANSFER_STATE_TIMEOUT = 1200000;

static const uint32_t REPORT_TRANSMISSION_PROGRESS_TIMEOUT = 10000;

// activity timeout in milliseconds (120 seconds)
static const uint32_t TRANSFER_STATE_INACTIVITY_TIMEOUT = 120000;
/**
 * This context is used inside each of the do_<> functions in order to distinguish
 * first, last and other executions.
 */
FsmContext _context{InternalFsmState::DONE, false, 0, 0, 0};

/**
 * FSM action steps. 
 * If operation is not finished before the exit of the function, PENDING is returned.
 * If operation has been finished - DONE is returned.
 * If operation has timed out (states CONNECT and TRANSFER) - TIMEOUT is returned.
 * If a button press has been detected during BLE phases - RESTART_DETECTED is returned.
 * If an error that doesn't allow to continue to work is detected - ERROR is detected (f.e.
 *      crystal(s) haven't started, SPI Flash is absent, microphone is not working)
 */
CompletionStatus do_init();
CompletionStatus do_prepare();
CompletionStatus do_record_start();
CompletionStatus do_record();
CompletionStatus do_record_finalize();
CompletionStatus do_connect();
CompletionStatus do_transfer();
CompletionStatus do_disconnect();
CompletionStatus do_finalize();
CompletionStatus do_restart();
CompletionStatus do_shutdown();

/**
 * Cyclic function contains only the logic related to the FSM steps. 
 * Contents of the steps are extracted into do_<something> functions, to separate
 * FSM logic and step-related logic. 
 */
void application_cyclic()
{
    const auto timestamp = app_timer_cnt_get();
    const auto prevState = _applicationState;
    switch(_applicationState)
    {
    case AppSmState::INIT: {
        const auto res = do_init();
        if(CompletionStatus::DONE == res)
        {
            _applicationState = AppSmState::PREPARE;
        }
        else if (CompletionStatus::PENDING == res)
        {
            // do nothing, wait
        }
        else
        {
            _applicationState = AppSmState::FINALIZE;
        }
    }
    break;
    case AppSmState::PREPARE: {
        const auto res = do_prepare();
        if(CompletionStatus::DONE == res)
        {
            _applicationState = AppSmState::RECORD_START;
        }
        else if (CompletionStatus::PENDING == res)
        {
            // do nothing, wait
        }
        else
        {
            _applicationState = AppSmState::FINALIZE;
        }
    }
    break;
    case AppSmState::RECORD_START: {
        const auto res = do_record_start();
        if(CompletionStatus::DONE == res)
        {
            _applicationState = AppSmState::RECORD;
        }
        else  if (CompletionStatus::PENDING == res)
        {
            // do nothing, wait
        }
        else
        {
            _applicationState = AppSmState::FINALIZE;
        }
    }
    break;
    case AppSmState::RECORD: {
        const auto res = do_record();
        if(CompletionStatus::DONE == res)
        {
            _applicationState = AppSmState::RECORD_FINALIZATION;
        }
        else if(CompletionStatus::ERROR == res)
        {
            _applicationState = AppSmState::FINALIZE;
        }
        else if (CompletionStatus::PENDING == res)
        {
            // do nothing, wait
        }
        else
        {
            _applicationState = AppSmState::FINALIZE;
        }
    }
    break;
    case AppSmState::RECORD_FINALIZATION: {
        const auto res = do_record_finalize();
        if(CompletionStatus::DONE == res)
        {
            _applicationState = AppSmState::CONNECT;
        }
        else if (CompletionStatus::PENDING == res)
        {
            // do nothing, wait
        }
        else
        {
            _applicationState = AppSmState::FINALIZE;
        }
    }
    break;
    case AppSmState::CONNECT: {
        const auto res = do_connect();
        if(CompletionStatus::DONE == res)
        {
            _applicationState = AppSmState::TRANSFER;
        }
        else if(CompletionStatus::RESTART_DETECTED == res)
        {
            _applicationState = AppSmState::RESTART;
        }
        else if (CompletionStatus::PENDING == res)
        {
            // do nothing, wait
        }
        else
        {
            _applicationState = AppSmState::FINALIZE;
        }
    }
    break;
    case AppSmState::TRANSFER: {
        const auto res = do_transfer();
        if(CompletionStatus::DONE == res)
        {
            _applicationState = AppSmState::DISCONNECT;
        }
        else if(CompletionStatus::TIMEOUT == res)
        {
            _applicationState = AppSmState::FINALIZE;
        }
        else if(CompletionStatus::RESTART_DETECTED == res)
        {
            _applicationState = AppSmState::RESTART;
        }
        else if (CompletionStatus::PENDING == res)
        {
            // do nothing, wait
        }
        else
        {
            _applicationState = AppSmState::FINALIZE;
        }
    }
    break;
    case AppSmState::DISCONNECT: {
        const auto res = do_disconnect();
        if(CompletionStatus::DONE == res)
        {
            _applicationState = AppSmState::FINALIZE;
        }
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

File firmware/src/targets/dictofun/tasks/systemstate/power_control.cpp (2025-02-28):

// SPDX-License-Identifier:  Apache-2.0
/*
 * Copyright (c) 2023, Roman Turkin
 */

#include "FreeRTOS.h"
#include "task.h"
#include "task_state.h"

#include "nrf_gpio.h"
#include "nrf_log.h"
#include "nrf_log_ctrl.h"

#include "boards.h"

namespace systemstate
{

static constexpr uint8_t power_flipflop_clk{LDO_LATCH_CLK_PIN};
static constexpr uint8_t power_flipflop_d{LDO_LATCH_D_PIN};

void configure_power_latch()
{
    nrf_gpio_cfg_output(power_flipflop_clk);
    nrf_gpio_cfg_output(power_flipflop_d);

    nrf_gpio_pin_clear(power_flipflop_clk);
    nrf_gpio_pin_set(power_flipflop_d);

    vTaskDelay(1);
    nrf_gpio_pin_set(power_flipflop_clk);
    vTaskDelay(1);
    nrf_gpio_pin_clear(power_flipflop_clk);
    vTaskDelay(1);
}

void shutdown_ldo()
{
    NRF_LOG_INFO("shutting the system down");
    // Letting logger to print out all it needs to print
    NRF_LOG_FLUSH();
    vTaskDelay(100);
    nrf_gpio_pin_clear(power_flipflop_d);
    vTaskDelay(1);
    nrf_gpio_pin_clear(power_flipflop_clk);
    vTaskDelay(1);
    nrf_gpio_pin_set(power_flipflop_clk);
    vTaskDelay(1);
    nrf_gpio_pin_clear(power_flipflop_clk);
    vTaskDelay(2000);
    // In some setups it happens, that at this point there is still power provided
    // (in particular, when the device is in the harness). Enforcing a reset for this case.
    NVIC_SystemReset();
}

} // namespace systemstate

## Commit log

2021-10-06 initial commit at github.com
    [dictofun_1.0_bom.csv, dictofun_1.0_bom.xlsx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]
2021-10-24 [pcb] added electrical OR for multiple power inputs
    [nRF52832_qfaa.kicad_pcb, nRF52832_qfaa.sch]
2021-11-06 [android] removed DeviceDiscoveryService
2021-11-21 hw version 1.1 draft
    [2450AT18B100E.STEP, 8-WSON (6x5).STEP, BQ24078RGTR.STEP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]
2021-11-23 [pcb] added fabrication outputs for the jlcpcb order
    [nRF52832_qfaa-B_Mask.gbr, nRF52832_qfaa-B_Paste.gbr, nRF52832_qfaa-B_SilkS.gbr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]
2021-12-11 [nrf] fixed pairing. now the whole pipeline works
    [BleSystem.h, task_state.cpp]
2021-12-13 [nrf] added LED indication
2021-12-13 [nrf] separate board-specific parameters into boards.h
2021-12-28 [nrf] fix build after SDK change
    [boards.c, boards.h, main.cpp]
2022-01-02 [pcb] added remarks on hw errors
2022-01-23 [case] added IPT and STL models of case
    [bottom.ipt, bottom.stl, button.ipt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]
2022-01-23 [nrf] fixed pca10040 build, slightly refactored folder structure
    [boards.c, boards.h, dictofun_1_0.h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]
2022-01-24 [nrf] fixed bootloader linker error
    [sdk_config.h]
2022-01-25 [nrf] disable uart log in bootloader
2022-01-26 [nrf] debugged new SPI driver wrapper
2022-02-03 [nrf] working on simple predicable FS over SPI Flash
2022-02-11 [nrf] simple_fs integration step 1: replace all calls to lfs with simple_fs, reach compilable state
    [BleSystem.h, main.cpp, task_state.cpp]
2022-02-11 [nrf] simple_fs integration step 2: add glue API implementation
2022-02-15 [nrf] added printout of memory stats at finalize stage
2022-02-18 [nrf] few fixes for error handling
    [task_led.cpp, task_state.cpp]
2022-03-18 [nrf] fixed bug with files >1 failing to get recognized/to play
    [main.cpp, task_state.cpp]
2022-03-18 fixes upon the review
    [main.cpp]
2022-04-30 [pcb] v1.2 schematics and PCB, start of the fixture
    [nRF52832_qfaa-B_Mask.gbr, nRF52832_qfaa-B_Paste.gbr, nRF52832_qfaa-B_Silkscreen.gbr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]
2022-04-30 [pcb] finalized the fixture
    [test_fixture-B_Cu.gbr, test_fixture-B_Mask.gbr, test_fixture-B_Paste.gbr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]
2022-04-30 [pcb] placed v1.2 order
    [nRF52832_qfaa.csv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]
2022-06-08 added secure characteristic for ios pairing workaround
    [sdk_config.h]
2022-06-16 [nordic] added repeated request for the case of error at file info transmission
2022-07-23 [nordic] achieved correct record restart from perspective of FS.
    For BLE connection restart is still unstable.
    Added shutdown after APP_ERROR_CHECK.
    [main.cpp, task_state.cpp]
2022-07-27 [nordic] added battery level measurement logic
2022-07-28 [case] added Fusion 3D files for the case
    [dictofun_button.f3d, dictofun_case_bottom.f3d, ductofun_case_top.f3d]
2022-08-28 [nrf] added active transfer FSM hang detection; moved battery measurement to start
2022-08-28 [nrf] extended FSM failure detection timeout; fixed bug with file not closed at restart
    [task_state.cpp]
2022-08-29 [nrf] stabilized single file transmission by an artificial delay at first BLE transaction
    [task_state.cpp]
2022-08-31 [nrf] fixed few stability issues
    [task_state.cpp]
2022-12-09 [cli] integrate Nordic CLI (#74)
    * [cli] moved logger to a dedicated task, fixed RTOS running issue
    * [cli] enabled nordic CLI
    [cli_commands.c, dictofun_1_1.h, main.cpp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]
2022-12-15 [pcb] version 1.3 (#75)
    Changes:
    LDO voltage regulator replaced with DC-DC (expected increase in efficiency)
    added small-footprint RTC chip
    analog latch for regulator EN pin replaced with a digital flip-flop
    Fixture:
    added Raspberry Pico to the PCB
    added current measurement setup
    planning to reduce hardware in use to a single PCB
    [nRF52832_qfaa-Bottom.dxf, nRF52832_qfaa-Edge_Cuts.dxf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]
2023-01-06 [fw] Refactor application using FreeRTOS tasks to decouple functionality (#76)
    [fw] Kick-off of architecture refactoring
    * introduced basic queue-based communication between CLI, SystemState and Audio tasks
    * refactored tasks' structure to isolate tasks from each other
    * added CLI command that launches a record for a fixed amount of time
    [app_error_handler.cpp, cli_commands.c, main.cpp]
2023-01-08 [nordic] implement PDM microphone (#77)
    - implementation of PDM microphone using Nordic PDM driver
    - implementation of a data sync (targeting at integration tests)
2023-01-10 [fw] introduce storage infrastructure (#78)
    - integrate LittleFS
    - change Spi Flash driver to use abstract interface (also implementing a setup for unit tests)
    - change SPI Flash to use synchronous access API
    - fix bug in SPI Flash driver (erase command has never been launched due to a wrong opcode)
    - implement all tasks- and cli- infrastructure for storage subsystem
    [cli_commands.c, main.cpp, task_memory.cpp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]
2023-01-11 [ble] added BLE subsystem (#80)
    - added CLI commands to start and stop BLE
    - added BLE configuration
    - managed to connect to and disconnect from the device
    - added NRF error decoder to ease debugging
    [cli_commands.c, main.cpp]
2023-01-12 [nordic] implement operational LBS (LEDs only) (#81)
2023-01-12 [bugfix] fix SPI driver issue with the stack (#82)
    [app_error_handler.cpp, task_memory.cpp]
2023-02-06 [test fts] refactoring BLE FTS infrasturcture (#89)
    * separated dictofun BLE control and FTS Client code
    * improve robustness of connection to the Dictofun
    * made test output less mouthful in case of correct execution of tests
2023-02-19 [nordic] introduce decimation + fix LittleFS losing data issues (#97)
    [main.cpp, task_memory.cpp]
2023-02-20 [audio] fix audio quality issue (#99)
    [main.cpp]
2023-03-12 [rtc] add functional I2C driver base (#112)
2023-03-13 [rtc] implement RV4162-C7 driver (#113)
2023-03-14 [button] added task_button (#115)
2023-03-18 [state] refactor task_state (#119)
    * [state] refactor task state: move cli logic out of main body
    * [state] move power control to separate compilation unit
2023-03-18 [state] implemented record launch upon button press (#120)
    * also fixed bug in record stop procedure
    [task_state.cpp]
2023-03-18 [state] implement memory ownership switch in field modes (#121)
2023-03-19 [app] implemented filesystem access keepalive for power management (#123)
2023-03-19 [led] implement LED control (#124)
    * implemented LED control
    * implemented CLI commands for testing
2023-03-19 [led] implemented application indication (#125)
2023-03-19 [led] implemented application indication (#126)
2023-05-02 [case] added models for harness v1.3
    [dictofun_1.3_bed_of_nails.f3d, dictofun_1.3_bed_of_nails.stl, dictofun_1.3_bed_top.f3d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]
2023-07-24 [fts] reset data queue before a new request of files count (#136)
    * [fts] reset data queue before a new request of files count
    [power_control.cpp]
2023-08-05 [build] add versioning output (#138)
    * versioning info is now generated and printed
2023-09-25 added workaround and a warning regarding the new FS issue (missing end of the files) (#149)
    [task_memory.cpp]
2023-10-07 [batt] implement battery measurement task (#150)
2023-10-15 [batt] added periodic battery level print to console (#153)
2023-10-15 reduced amount of printed logs per default (#154)
2023-10-15 added RAII time profiling printout for memory operations (#155)
2023-10-15 add BLE-enabling in case of FS error prior to reset (#157)
    [task_memory.cpp, task_state.cpp]
2023-10-15 added FS formatting if memory is full/files count is too high (#158)
    [main.cpp, task_memory.cpp, task_state.cpp]
2023-10-16 changed battery levels, added no-op reaction in case of a low battery (#159)
    * changed battery levels, added no-op reaction in case of a low battery
2023-11-13 reduced battery measurements frequency, added printout in case of multiple FTS commands
2023-11-20 added erasure of flash memory at the formatting stage (#166)
2023-11-26 measures added to assure that timeouts don't interrupt the memory erasure (#167)
2023-11-26 fixed multiple issues (#168)
    - BLE timeouts upon double recording
    - file not found reporting
    - file system repair, if not closed file was found
    [task_memory.cpp, task_state.cpp]
2023-12-04 corrected timeouts for easier use in the field
    [sdk_config.h, task_state.cpp]
2024-01-13 added additional check of button state before creating a record (#171)
2024-01-13 implemented unpairing (should be moved to device information service) (#172)
2024-01-19 Replace file search algortithm at the mounting stage (#173)
    * replace linear files' scanning with logarithmic
    * introduce and implement unit-tests over myfs
    [task_memory.cpp]
2024-04-14 PCB v1.4 (#175)
    [dictofun-Bottom.dxf, dictofun-Edge_Cuts.dxf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]
2024-05-06 bugifx: existing FTS issues (#176)
    * added buffer canaries to workaround issue
    * Investigate memory corruption issue #177
    * added printout of disconnect cause
    * implemented a disconnect upon transfer completion
2024-06-01 fixed initial battery level value setting
    [task_battery.cpp, task_state.cpp]
